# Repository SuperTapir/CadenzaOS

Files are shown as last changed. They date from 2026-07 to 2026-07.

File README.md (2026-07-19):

# Cadenza OS

**English** · [简体中文](README.zh-CN.md)

<p align="center">
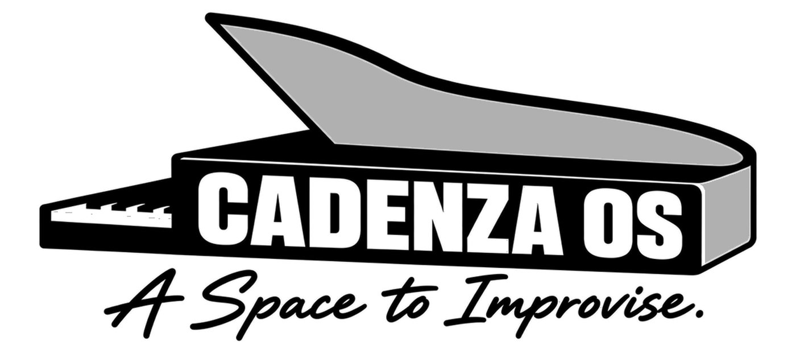
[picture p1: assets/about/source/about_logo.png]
Cadenza OS — A Space to Improvise.
  
</p>

**Cadenza** is a personal interactive-device and creative platform by Tapir.
Its system, **Cadenza OS**, explores a portable 1-bit App/Runtime, system
interaction model, and animation language for resource-constrained hardware.
The current prototype targets the original LILYGO T-Embed (not the CC1101
edition).

https://github.com/user-attachments/assets/4cbb17ba-b52b-44dc-b557-88dd9fdf3d63

The walkthrough above includes sound and covers Launcher, Timer, the background
Timer indicator, System Menu, Motion, Settings, and Animation Gallery. The
current build also adds the SIGHT note-reading trainer. Cadenza supports the
T-Embed 320×170 and Sharp Memory LCD 400×240 display profiles.

> **Prototype status:** desktop, headless, and firmware build gates are in
> place. Encoder feel, display behavior, real frame rate, and speaker quality
> still require validation on an original T-Embed device.

> **Non-commercial hobby project:** Cadenza is a personal project made for the
> enjoyment of designing and building it. There is no plan to commercialize
> it, sell it, or turn it into a business.

## Motivation

A *cadenza* is a passage in music where a performer is given room for free
expression. That idea fits this project: a restrained and coherent device that
leaves space for small games, tools, animation, and interaction experiments.

Cadenza grows out of Tapir's deep affection for Playdate's design and art
direction—not simply for it as a handheld, but for it as a carefully designed
digital object: a reflective black-and-white display, direct physical input,
expressive motion, and a small set of features with a strong point of view.
Many Launcher behaviors, interaction rhythms, animations, and visual details
in Cadenza deliberately study and attempt to recreate how Playdate works and
feels. Rebuilding those ideas is a way to understand the craft behind them and
to carry that learning into a personal platform, rather than an attempt to run
or replace Playdate software.

The T-Embed is the first software and interaction prototype. The longer-term
hardware direction centers on a 400×240 Sharp `LS027B7DH01` Memory LCD and a
dedicated handheld design. The software is structured so the prototype proves
the platform without defining the final device.

## Highlights

- One 1-bit framebuffer, App/Runtime, and layout model shared by the 320×170
  T-Embed and 400×240 Sharp profiles;
- six built-in Apps—Launcher, Timer, SIGHT, Motion, Settings, and Animation
  Gallery—with encoder navigation, button input, a System Menu, and explicit
  return to Launcher;
- system-owned background Timer, expiry alert, session volume, Reduced Motion,
  and vertical or horizontal Launcher orientation;
- 18 semantic sound cues plus bounded 1–4 note MIDI playback, backed by the
  same 44.1 kHz, four-voice synthesis core in the SDL callback and T-Embed I²S
  task;
- allocation-free Tween, Timeline, Spring, transitions, camera effects,
  particles, and atlas animation state machines;
- an SDL3 desktop simulator, deterministic headless host, PNG/GIF capture,
  pixel snapshots, and tests for lifecycle, input, animation, audio, and system
  services.

Cadenza is currently a 1-bit interaction and animation runtime, not a complete
game engine. Physics, collision, tilemaps, ECS, and level systems are
deliberately out of scope.

## Quick start on macOS

```bash
brew install cmake sdl3
./tools/simulator.py run --profile t-embed --scale 2 --overlay
```

For the source-watching development loop:

```bash
./tools/simulator.py dev --profile t-embed --scale 2 --overlay
```

Common presentation options are `--profile t-embed|sharp`, `--scale 1..4`,
`--palette reflective|pure`, `--overlay`, and `--device-frame`. The default
`reflective` palette approximates a reflective Memory LCD; `pure` is for strict
black-and-white inspection. These options do not change the framebuffer,
captures, snapshot hashes, or firmware output.

## Desktop controls

| Input | Action |
| --- | --- |
| Mouse wheel or `Left` / `Right` | Rotate the encoder |
| Tap `Space` / `Enter` | Click the button |
| Hold `Space` / `Enter` | Open the System Menu |
| `F1` | Toggle the debug HUD |
| `F2` / `F3` | Pause or resume / single-step while paused |
| `F4` / `F5` | Toggle fixed/real step / cycle time scale |
| `F6` / `F7` | Capture PNG / start or stop PNG+GIF recording |

See [`docs/development.md`](docs/development.md) for complete controls, Timer
behavior, display options, and the Launcher Cover workflow.

## Build and verification

```bash
tools/check.sh host           # host build and full test suite
tools/check.sh desktop        # SDL3 build and launch smoke test
tools/check.sh firmware       # ESP-IDF 5.5 T-Embed primary (UAC+CDC)
tools/firmware_uac.sh flash   # flash primary firmware to T-Embed
tools/check.sh firmware-pio   # PlatformIO rollback (no UAC)
tools/check.sh all            # host + desktop + ESP-IDF firmware + diff
```

Primary firmware needs ESP-IDF v5.5 (`CADENZA_IDF_PATH` or `../esp-idf-v5.5`).
PlatformIO rollback (no microphone):

```bash
../.platformio-env/bin/pio run
../.platformio-env/bin/pio run --target upload
../.platformio-env/bin/pio device monitor --baud 115200
```

Create an ad-hoc-signed macOS development package with:

```bash
./tools/simulator.py package
```

The resulting `.app` and zip are intended for local or same-architecture Mac
development. They are not Developer ID signed or notarized releases.

## Hardware safety

The current pin configuration comes from the official original LILYGO T-Embed
configuration. **Do not flash it to a T-Embed CC1101.** Check the packaging and
board markings before using firmware from this repository.

## Development disclosure

Most source code in this repository has been generated and iterated with
**OpenAI Codex** under Tapir's direction. Tapir defines the product vision,
requirements, architecture decisions, review standards, and acceptance
criteria; Codex performs much of the implementation, refactoring,
documentation, and test authoring.

AI-generated code is not treated as independently trustworthy. Accepted
changes are reviewed and checked through builds, tests, snapshots, research
records, and hardware gates where hardware is available. Tapir remains the
project's author and maintainer and is responsible for the work accepted into
the repository.

## Acknowledgements

- Deepest thanks to [Panic](https://panic.com/) and the
  [Playdate](https://play.date/) team. Cadenza would not exist without the
  affection and respect Tapir has for Playdate's industrial design, art
  direction, interaction design, and animation craft. The project openly
  studies and attempts to recreate many of those interaction patterns and
  qualities. Cadenza remains an independent project, is not compatible with
  Playdate software, and is not endorsed by Panic. The vendored Playdate
  Roobert font subset is used under CC BY 4.0 as documented in
  [`THIRD_PARTY_NOTICES.md`](THIRD_PARTY_NOTICES.md).
- [LILYGO](https://www.lilygo.cc/) created the T-Embed hardware used for the
  first prototype and publishes the reference material used by the platform
  adapter.
- SDL3, U8g2, doctest, stb_image_write, and gif-h make the portable build,
  rendering, testing, and desktop tooling possible. Exact versions, source
  boundaries, and licenses are recorded in
  [`THIRD_PARTY_NOTICES.md`](THIRD_PARTY_NOTICES.md).

## Further reading

- [`docs/project-vision.md`](docs/project-vision.md): long-term goals,
  motivation, and hardware direction;
- [`docs/platform-architecture.md`](docs/platform-architecture.md): platform
  responsibilities and architectural boundaries;
- [`docs/development.md`](docs/development.md): development, testing, and
  simulator reference;
- [`docs/verification.md`](docs/verification.md): current evidence, gates, and
  device verification scripts;
- [`docs/engine-adoption-decision.md`](docs/engine-adoption-decision.md): engine
  and library adoption boundaries;
- [`docs/audio-reference-research.md`](docs/audio-reference-research.md): audio
  research and adoption decisions;
- [`docs/audio-asset-contract.md`](docs/audio-asset-contract.md): delivery and
  acceptance rules for future WAV assets.

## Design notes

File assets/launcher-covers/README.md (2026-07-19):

# Launcher Covers

`timer.pbm`、`motion.pbm`、`settings.pbm` 与 `gallery.pbm` 是四个内置
App 经人工确认后的 350×155、1-bit 封面。`*_t_embed.pbm` 是直接从同一
高分辨率母图生成的 280×124 T-Embed 版本。它们以屏幕像素为
最终审阅单位，不在设备运行时解码 PNG、缩放或分配临时 framebuffer。

`source/` 保存四张清理后的原始 PNG，用于未来重新调阈值、支持新尺寸或
重新导出；固件不直接编译这些 PNG。

源插图由用户提供并经 AI 辅助精简；使用 Pillow 的 LANCZOS 缩放到
350×155 与 280×124。新版 MOTION、SETTINGS 与 GALLERY 使用五档 ordered dither，并启用通用
`--edge-cleanup`：同时邻接近黑与近白的抗锯齿过渡像素及其 1 px guard band
改用 coverage threshold，宽阔灰面仍保留 ordered dither，避免标题、圆环和
baseline、控制台或人物轮廓的灰边变成 Bayer 毛刺。SETTINGS 的母图另经插画门禁，
拒绝连续产品渲染光照，要求硬边离散平面与独立的实色外轮廓。TIMER 使用五档 ordered dither，并在已批准标题区域保留原 coverage hint，避免
改变其既有 hash。
禁止从已二值化的 PBM 二次缩放，否则细线会碎裂并产生孤立黑点。

MOTION 的可复现生成与检查命令：

```sh
python3 .codex/skills/generate-launcher-cover-art/scripts/prepare_cover.py \
  assets/launcher-covers/source/motion.png assets/launcher-covers \
  --name motion --levels 5 --edge-cleanup

python3 .codex/skills/generate-launcher-cover-art/scripts/prepare_cover.py \
  assets/launcher-covers/source/motion.png assets/launcher-covers \
  --name motion --levels 5 --edge-cleanup --check
```

GALLERY 使用相同管线：

```sh
python3 .codex/skills/generate-launcher-cover-art/scripts/prepare_cover.py \
  assets/launcher-covers/source/gallery.png assets/launcher-covers \
  --name gallery --levels 5 --edge-cleanup --check
```

SETTINGS 使用相同管线：

```sh
python3 .codex/skills/generate-launcher-cover-art/scripts/prepare_cover.py \
  assets/launcher-covers/source/settings.png assets/launcher-covers \
  --name settings --levels 5 --edge-cleanup --check
```

非 `--check` 模式还会自动生成双 profile 的硬阈值、ordered-dither pure/reflective
及 nearest-neighbor 4× 审阅图；硬阈值负责证明标题与主轮廓不依赖灰阶，4× 图负责
区分规则像素阶梯与贴边 Bayer 毛刺。

这些工具需要 Pillow；CMake 使用的 Python 能导入 Pillow 时会自动注册八个母图
来源检查，没有 Pillow 时仍保留不依赖 Pillow 的八个 PBM→header 检查。

TIMER 的可复现生成与检查命令：

```sh
python3 .codex/skills/generate-launcher-cover-art/scripts/prepare_cover.py \
  assets/launcher-covers/source/timer.png assets/launcher-covers \
  --name timer --levels 5 \
  --solid-light-region 0.026 0.40 0.70 0.92

python3 .codex/skills/generate-launcher-cover-art/scripts/prepare_cover.py \
  assets/launcher-covers/source/timer.png assets/launcher-covers \
  --name timer --levels 5 \
  --solid-light-region 0.026 0.40 0.70 0.92 --check
```

生成 packed headers：

```sh
python3 tools/pack_bitmap.py assets/launcher-covers/timer.pbm \
  lib/cadenza_apps/src/generated/timer_cover.h \
  --symbol kTimerCover \
  --provenance "Cadenza original AI-assisted 3D TIMER artwork, user-approved 2026-07-19; canonical PBM in assets/launcher-covers/timer.pbm"
```

`motion`、`settings`、`gallery` 以及对应的 `*_t_embed` 使用同样命令与
对应符号。CMake host tests 会使用 `--check` 验证八个 header 与 PBM
逐字节一致。

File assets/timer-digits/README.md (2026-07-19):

# Timer numeral atlases

`tools/generate_timer_digits.py` 生成 Cadenza 自有的工业仪表数字 atlas。运行时只读取已打包的 1-bit header，不依赖字体引擎、Pillow 或 heap。

- T-Embed：digit cell `50×84`、colon cell `28×84`，组合 `MM:SS` 为 `228×84`。
- Sharp：digit cell `68×120`、colon cell `36×120`，组合 `MM:SS` 为 `308×120`。
- `source/timer_digits_master.svg` 是平滑可编辑母稿；两个 PBM 是原生 profile 资产。

生成命令：

```bash
python3 tools/generate_timer_digits.py
python3 tools/pack_bitmap.py assets/timer-digits/timer_digits_t_embed.pbm \
  lib/cadenza_core/include/cadenza/presentation/generated/timer_digits_t_embed.h \
  --symbol kTimerDigitsTEmbed \
  --provenance "Cadenza-authored industrial Timer numerals; native 528x84 atlas from tools/generate_timer_digits.py"
python3 tools/pack_bitmap.py assets/timer-digits/timer_digits_sharp.pbm \
  lib/cadenza_core/include/cadenza/presentation/generated/timer_digits_sharp.h \
  --symbol kTimerDigitsSharp \
  --provenance "Cadenza-authored industrial Timer numerals; native 716x120 atlas from tools/generate_timer_digits.py"
```

封面裁切、灰阶缩略图和 reflective preview 使用 `tools/asset-requirements.txt` 中固定版本的 Pillow；该依赖仅属于离线资产流程。

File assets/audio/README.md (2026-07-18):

# Audio source assets

此目录用于未来经人工选中的交互音效无损母版。当前运行时仍使用参数合成，仓库尚未包含 sample voice 或默认 WAV 资产。

提交文件前请遵循 [`docs/audio-asset-contract.md`](../../docs/audio-asset-contract.md)，并为每个 WAV 提供 manifest。不要把临时生成结果、来源不明素材或有损预览文件提交到这里。

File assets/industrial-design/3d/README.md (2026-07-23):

# Cadenza 3D 概念模型 V1

这是用于讨论外观比例、握持和器件包络的参数化 OpenSCAD 概念模型，不是可直接开模、CNC 或装配的生产 CAD。

## 当前包络

- 主机本体概念尺寸：`120 × 50 × 16 mm`
- 一体式实心后壳最大凸出：约 `10 mm`
- 中央最大总厚度：约 `26 mm`；四周边缘仍保持圆润纤薄
- 固定屏幕玻璃：`62.8 × 42.82 × 1.64 mm`
- 屏幕可视区：`58.8 × 35.28 mm`
- 旋压 `A` 控制器有效哑光面径：约 `20.5 mm`；低饱和银蓝色外环总直径约 `22.6 mm`
- 屏幕玻璃包络隐藏在前壳下；外露黑色窗口约 `60.0 × 36.5 mm`，可视区外只留约 `0.6 mm` 细黑收口
- 正面以屏幕中心线为整机中轴，屏幕几何居中；左右控制区宽度完全相等
- `B` 面径约 `10.5 mm`；`Menu` 为约 `8.5 × 3.4 mm` 的低矮胶囊键；旋压 `A` 约 `20.5 mm`

模型包含屏幕、`B`、`Menu`、旋压 `A`、顶部金属 `Power/Lock`、向机顶中央收近的 USB-C 充电口、机顶一体化声学槽阵列、左端短边齐平红外光学窗、机底右下角 MicroSD 和干净的可维护后盖。USB-C 与 MicroSD 分属上、下两边，避免同时插拔干涉。左端约 `10 × 3 mm` 的深酒红烟熏长圆透镜同时服务红外发射与接收；透镜表面封闭并带轻微弧度，后方只若隐若现地表现一大一小两枚圆形光学元件，以区别于 USB 或耳机端口，外表不暴露 LED。窗口材料、红外透过率、内部遮光隔舱、发射角和接收角均由第三方验证。屏幕玻璃的安装黑边由珍珠银白前壳覆盖，屏幕表面比前壳低约 `0.5–0.7 mm`，正面只显示窄黑色窗口收口。`Menu` 键不再使用文字，改为键帽上的三点 `•••` 标识。当前不包含扩展坞、背板导轨或外接模块。

背面采用 Sony / 日系仪器方向：大面积安静表面中嵌入一块居中的长圆角电池与维修盖，只保留窄分件缝、四条开启防滑纹和一个低调紧固点。该结构借鉴 SONIC SticKURU Timer 背面“功能细节集中、其余表面克制”的秩序，不复制其具体电池仓几何。

背面采用一体式实心楔形后壳：从主机后壳的宽大根部连续收窄到外侧平台，约凸出 `10 mm`。侧面轮廓内全部为实体，没有空隙、背夹、支撑杆、翻板、转轴或活动支架。斜线是实心后壳的外轮廓，不是独立零件。外表面保留居中长圆角维修盖板和极少服务细节。它通过宽而顺滑的过渡与主体融合，避免成为额外挂载的“书包”。各摆放姿态的重心、摩擦力和按键操作稳定性必须由第三方用真实重量样机验证。

维修盖中央使用缩小后的浅浮雕花体 `Cadenza` 字样，同材质、同颜色，主要依靠侧光阴影显现，不做高对比印刷。字样以机顶（声学槽阵列与 Power/Lock 所在长边）朝上时保持正读；背面正投影视图已按这个正常观看方向校核，不上下翻转。

机底不使用独立深色橡胶条，改为两条与外壳一体成型、同色且仅轻微突出的纵向小棱。小棱沿机身前后厚度方向延伸，不沿机身左右长边横置；其轮廓必须完整收在机底银白侧壁内，不跨越与楔形后壳的交界线。实际防滑性必须结合表面纹理和样机摩擦测试确认。

机顶使用九条等形长圆声学槽：左右各四条服务扬声器，中间一条作为麦克风拾音入口，外观上是一组连续、对称且有秩序的开孔。正面不再出现独立麦克风黑点。槽阵内侧覆盖深灰色细密声学防尘网；中心拾音槽必须通过独立密封声道连接麦克风，并与左右扬声器音腔及壳体振动软隔离，不能共用音腔。第三方必须根据扬声器频响、声压、麦克风指向性和防尘要求选择网材、目数、声阻与固定工艺，并用声学样机验证回声、串音和结构振动。

当前 CMF 概念以 `PANTONE Cool Gray 2 C` 作为正面塑料按钮浅灰参考，以偏暖的 `PANTONE Black 7 C` 作为 `A/B` 字标深石墨灰参考。`A` 旋压控制器增加低反光、低饱和的银蓝色窄外环（约 `PANTONE 7544 C` 方向），内部有效操作面仍为哑光浅灰塑料；触觉点收敛为 10 个。所有键帽都使用大面积近似平整的顶面和小半径圆滑肩部，不做纯直筒圆柱，也不做过分饱满的半球；其中 A 保留约 `1.5–1.7 mm` 可抓握侧高，B 与 `•••` 只略高于面板。顶部 Power/Lock 仍为中性缎面银色。整体复古感来自博朗式的克制比例、低饱和材料、明确功能层级和精确细节秩序，不复制具体产品。模型中的 RGB 只能用于屏幕预览，实体必须用近期 Pantone 色卡和实际材料样片确认。

## 文件

- `cadenza-concept-v1.scad`：可继续调整的参数化源文件
- `cadenza-concept-v1.csg`：OpenSCAD 展开后的几何树，适合交换或排查模型
- `cadenza-concept-v1.stl`：通用网格预览文件
- `cadenza-concept-v1.3mf`：优先用于支持 3MF 的查看器
- `cadenza-concept-v1-preview.png`：快速预览图
- `cadenza-concept-v1-back-pod-preview.png`：一体式实心后壳与顺滑过渡的预览
- `cadenza-concept-v1-front.png`：用于检查屏幕中轴与左右控制区对称关系的正投影视图
- `cadenza-concept-v1-back.png`：用于检查日系仪器式电池/维修盖秩序的背面正投影视图
- `cadenza-concept-v1-side.png`：用于检查“外轮廓内全实体”的楔形侧面
- `cadenza-concept-v1-top.png`：用于检查 USB-C、扬声器防尘网开孔与 `Power/Lock` 的机顶布局
- `cadenza-concept-v1-bottom.png`：用于检查右下角 MicroSD 与两条纵向防滑小棱
- `cadenza-concept-v1-ir-left.png`：用于检查左端短边齐平红外发射/接收光学窗

## 边界

圆角、壁厚、卡扣、螺钉、按键行程、屏幕固定、音腔、天线净空、连接器安装、公差和材料收缩均未完成工程验证。第三方结构工程师必须以真实器件和制造工艺重新设计。

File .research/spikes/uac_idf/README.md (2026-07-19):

# CadenzaOS ESP-IDF 5.5 UAC / T-Embed firmware composition

这是 CadenzaOS **主固件组合根**（ESP-IDF 5.5：Runtime Apps + UAC2 麦 + CDC）。
PlatformIO Arduino 2.0.17 仅作无 UAC 回滚（`tools/check.sh firmware-pio`）。

```sh
# 从仓库根目录
tools/check.sh firmware          # 构建（firmware-uac 为同义别名）
tools/firmware_uac.sh flash      # 烧录
tools/firmware_uac.sh size
tools/firmware_uac.sh connectivity
```

SDK 组合：ESP32-S3、ESP-IDF 5.5.0、Arduino-ESP32 3.3.10、`usb_device_uac`
1.3.1、TinyUSB 0.19.0~3、`esp_codec_dev` 1.5.10、UAC2 microphone-only + CDC。
portable Runtime / voice / Apps 仍在仓库 `lib/`；本目录只做板级装配，不私补
本机 PlatformIO Arduino 2.0.17 package。

已定麦克风基线（2026-07-19 真机）：双 MEMS 平均、24 dB、USB 重连强制回收
I²S/DMA 帧对齐；macOS 枚举为 48 kHz mono 系统麦。

## 前置条件

- 官方 ESP-IDF v5.5 checkout；验证 commit 为
  `8c750b088c7cd857d079c0eeb495da199b359461`。
- `install.sh esp32s3` 与 `export.sh`，或由 `tools/firmware_uac.sh` 通过
  `CADENZA_IDF_PATH` / `../esp-idf-v5.5` 自动 `source export.sh`。

## 构建（底层命令；优先用 tools/ 入口）

```sh
cd .research/spikes/uac_idf
idf.py -B build-idf-arduino-composite build size

idf.py -B build-idf-hardware \
  -DSDKCONFIG="$PWD/sdkconfig.hardware" \
  -DSDKCONFIG_DEFAULTS='sdkconfig.defaults;sdkconfig.hardware.defaults' build
idf.py -B build-idf-hardware size

idf.py -B build-idf-connectivity \
  -DSDKCONFIG="$PWD/sdkconfig.connectivity" \
  -DSDKCONFIG_DEFAULTS='sdkconfig.defaults;sdkconfig.hardware.defaults' build
idf.py -B build-idf-connectivity size
```

它链接 ESP-IDF 内置的 NVS、`esp_netif`、event loop、Wi-Fi station、NimBLE、
software coexistence、`wifi_provisioning` 与 protocomm Security 2。Security 0/1
在该配置中关闭；仓库不带通用 verifier 或 salt，量产方必须覆盖弱符号
`cadenza_load_security2_material`，从受控平台边界提供设备材料。

`sdkconfig.defaults` 只启用 `esp_codec_dev` 的 ES7210 driver，关闭未使用 codec。
默认 board config 固定 I²C0 SDA 18/SCL 8、I²S1 MCLK 48/BCLK 47/LRCK 21/DIN 14，
48 kHz、32-bit stereo DMA 输入在 portable normalizer 中平均为 S16 mono。
已定真机基线：双 MEMS 平均、24 dB in-gain。

当前完整 candidate binary 为 388,032 B（`0x5ebc0`），size tool total image
387,911 B、DIRAM 146,103 B（42.75%）、Flash Code 235,552 B、Flash Data
75,328 B。UI/main、TinyUSB、UAC mic、ES7210 capture 与 speaker 的显式 stack
预算合计 26,624 B，运行时 free heap/high-water 仍待真机测量。

2026-07-18 clean reconfigure 后，不带连接 adapter 的完整 candidate 为
390,752 B，total image 390,607 B、static D/IRAM 147,767 B。带连接 adapter 的
candidate 为 1,176,672 B，total image 1,176,519 B、static D/IRAM 226,823 B，
相对前者分别增加 785,920 B、785,912 B 与 79,056 B；1.5 MiB app partition
剩余约 23%，static D/IRAM 余 114,937 B。该差值包含 Wi-Fi、NimBLE、protocomm、
Security 2 与它们的链接闭包，不代表运行时 heap/stack 已验收。

ESP-IDF 5.5 的官方 `protocomm_nimble.c` 会自行调用 `nimble_port_init()`、覆盖
`ble_hs_cfg` callback，并创建/停止 NimBLE host task。当前 adapter 因而把普通
App BLE 与 BLE provisioning 定义为排他角色：普通 BLE 仅在需要时启动自己的
NimBLE host；Security 2 配网仅在普通 BLE 未请求/未初始化时启动，否则返回 busy。
这不是推测性的共存承诺，角色切换与资源释放仍须真机验证。

`dependencies.lock` 锁定 32 个解析组件。供应链复验逐项校验所有
`CHECKSUMS.json`，共 7,600 个文件、0 个错误；ELF 审计确认 Cadenza adapter、
`wifi_prov_mgr_start_provisioning`、NimBLE init/stop 与 UAC public/upstream callback
符号同时存在，且没有修改 `managed_components` 源码。

`dependencies.lock` 是本次成功解析得到的完整依赖锁。不要修改本机 Arduino
2.0.17 framework package 来绕过 TinyUSB audio 配置。

PlatformIO 的 ESP-IDF builder 在本 spike 中曾因同一 managed-component object
出现重复 action 而失败；`platformio.ini` 仅保留失败复现入口。候选 baseline
使用官方 `idf.py`，现有 Arduino firmware target 继续作为回滚路径。
当前 UAC component 内部会在 TinyUSB alt-setting callback 中维护 `mic_active`，
但没有向 user callback 暴露 microphone close/open。candidate CMake 对锁定的
1.3.1 两个 callback 做编译期符号重命名；Cadenza adapter 提供公共入口、先委托
原实现，再把 mount/alt-setting 写入 callback-safe `UsbVoiceSessionBridge`。该方式
不修改 managed component 源码；升级 component 时必须重跑 callback 源码与 ELF
符号审计。它证明 session wiring 可构建，不把 build-only 行为当作真机断连/重连
验收。

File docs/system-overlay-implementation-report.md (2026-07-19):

# System Overlay 实现与验证记录

状态：portable 实现与软件门禁完成；实体 T-Embed 的手感、可读性和 100 次循环验收待真机。

## 已交付边界

- `SystemSurfaceCoordinator`：单 interactive slot、完整按键序列 capture、转场 defer、固定容量 transient queue 和稳定 rejection diagnostics；
- System Menu：只保留 Resume、Sound、Motion，以及非 Home 场景的 Home action；Connectivity/Device 等无动作状态不占菜单空间；不进入 App catalog，不暴露 callback、driver 或任意 View；
- suspend-with-snapshot：Menu active 时冻结 App update/input/render 与背景，但 `SystemServiceHost` 继续 begin/commit；
- stateless `Panel`、`MenuRow`、`Selection`、`VolumeIndicator` 与 `Switch`；
- 固定合成顺序：App/transition → transient → interactive Menu → FrameCoordinator critical indicator；
- 320×170 与 400×240 使用同一 model、layout policy 和 renderer；不透明 Menu
  drawer 在 160 ms 内从右侧滑入，mask 同步渐强，左侧冻结 App 仍保留上下文，
  视觉语义对齐 Playdate 的覆盖式 System Menu。最终视觉去掉标题栏、箭头、双边框
  和横向 value 文本列；可操作项使用大字号，Sound 始终显示实心/空心音量柱，Motion
  使用紧凑横向开关，不绘制无动作底栏，Home 页面不显示冗余 Home action。

## 输入与生命周期证据

`cadenza_system_surface_tests` 与 `cadenza_app_runtime_tests` 锁定：

- opening long-press 的 held/release/click 不确认 Menu；
- closing long-press 到 release 全部由 System 消费，下一新序列才恢复 App；
- Menu turn 不进入 App，快速 delta 有界且每帧最多一个 Navigate intent；
- 转场中的 Menu 请求先 capture，目标 App stable 后再冻结并打开；
- Menu 多帧期间 App 不 update/render，也不发生 exit/enter；
- 平台事件和 setting command 仍在 frame transaction 中提交；
- busy、denied、invalid action 和 transient full 都保留 surface 并累计诊断。

双 profile Menu golden：

- 320×170 右侧 Menu drawer：`17166433962280013512`；
- 400×240 右侧 Menu drawer：`13747170315493377016`；
- 320×170 transient + indicator：`325176067826602694`；
- 400×240 transient + indicator：`3852824331461943778`。

## 内存与固件差异

Apple arm64 Debug 对象探针：

| 对象 | 大小 |
|---|---:|
| `MonoFramebuffer` | 12,024 B |
| `SystemSurfaceCoordinator` | 200 B |
| `AppRuntime` | 24,912 B |

`system_overlay_size_probe` 带编译期断言，要求 `AppRuntime` 小于三块最大
`MonoFramebuffer`；实现只复用既有 `outgoingFrame_`/`incomingFrame_`，没有第三块
12 KiB framebuffer。

PlatformIO Arduino-ESP32 2.0.17：

| 指标 | 改动前 | 当前 | 增量 |
|---|---:|---:|---:|
| static RAM | 98,808 B | 99,000 B | +192 B |
| flash | 358,805 B | 361,705 B | +2,900 B |

ESP-IDF 5.5 connectivity candidate 也实际编译 `system_surface.cpp`：binary
1,188,496 B、total image 1,188,351 B、static D/IRAM 231,143 B、Flash
1,052,528 B。Overlay 没有新增 task 或 stack，coordinator 继续在既有 frame
transaction 内同步推进。GCC 14 candidate 发现并修复了 Xtensa 上 `int32_t` 为 `long` 时
`std::min/std::max(int32_t, int)` 推导失败的问题。

## 实体验收（2026-07-19）

在实体 320×170 T-Embed 上完成，结论如下：

1. 650 ms 长按适合频繁打开，保留 `InputConfig::longPressMs = 650`；
2. 触发 release、关闭 held release 与快速连续开/关手感通过，无误确认与输入泄漏；
3. Menu 文本、selection、音量格与开关在面板上可读；
4. Muted/有声反馈等价，反复 open/close 稳定，串口无 panic/TWDT；
5. 不调整视觉常量，无 contract 回写需求。

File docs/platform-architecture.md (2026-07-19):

# Cadenza OS 平台架构（原型 v0.1）

当前目标不是把三个 Demo 做完整，而是确定一套小应用可以长期生长的稳定边界。Demo 只负责证明平台契约确实可用。

## 运行链路

```text
platform callbacks ──→ bounded typed PlatformEvent queue
                              ↓ beginFrame
raw input ──→ InputReducer ──→ frozen SystemSnapshot + AppUpdateContext
                              ↓ typed SystemCommand queue
                         SystemServiceHost commit
                              ↓ same-frame AppRenderContext
                         AppRuntime + transition
                              ↓
                       canonical MonoFramebuffer
                              ↓
               T-Embed / SDL / headless / future Sharp

ES7210/I²S1 ──→ 48 kHz voice coordinator ──┬─→ analyzer snapshot ─→ Apps
                                           └─→ UAC packetizer ───→ macOS
SoundCue / bounded MusicalNoteSet ─→ 44.1 kHz sound service ─→ I²S0 / SDL / headless
monotonic now ─→ TimerService deadline ─→ snapshot / critical TimerAlert
```

## 平台负责什么

- 初始化硬件和维护稳定的帧循环；
- 将旋钮和按钮统一成与具体 GPIO 无关的 `InputFrame`；
- 组合 `cadenza_core`、`cadenza_apps`、`cadenza_system` 与平台 adapter；
- 注册应用、维护当前应用，并调用生命周期；
- 拦截“长按打开 System Menu”这样的系统手势；
- 绘制统一的应用切换转场；
- 提供 row-major、MSB-first、`1 = black` 的 1-bit 画布，禁止应用依赖彩色
  TFT 或 SDL 特性；
- 将显示提交与应用绘制分离；
- 拥有 `InteractionSoundService`，把 Navigate、Confirm、Back 等语义提交给
  独立音频消费者；允许具备 SoundPlay capability 的 App 提交最多四音、钢琴
  MIDI 范围内的 `MusicalNoteSet`，但应用不得操作 SDL、I²S、WAV 路径、Hz、
  waveform、gain、duration、priority、voice 或任意 oscillator。
- 拥有 voice capture 生命周期、consumer fan-out、隐私状态与错误降级；App 不得
  取得 raw PCM、codec、DMA、USB、Wi-Fi 或 BLE callback。
- 拥有单一 `TimerService`、单调 deadline、后台 indicator 与 critical alert；App
  不读取平台时钟，也不在自身 `dt` 中累计倒计时。

## 应用负责什么

每个内置应用只实现五个很小的接口：

```cpp
const char* name() const;
void onEnter();
void onExit();
void update(const AppUpdateContext& context);
void render(MonoCanvas& canvas, const AppRenderContext& context);
```

update context 只含 `dt`、`InputFrame`、只读 `SystemSnapshot`、catalog view、
`AppNavigator` 与绑定当前 App 身份的 `AppCommandPort`；render context 只含只读 snapshot。
应用不读取 GPIO，不直接持有屏幕，不自行实现页面切换，也不通过 `delay()` 控制
节奏。状态只属于应用实例；系统可以随时离开它，再通过 `onEnter()` 重新进入。

## 模块与所有权

- `cadenza_core`：App 契约/目录/生命周期、输入、图形、动画、声音语义；不知道
  bundled App 与平台 SDK。
- `cadenza_apps`：Launcher、Timer、SIGHT、Motion、Settings、Gallery；只能依赖窄 App
  context。
- `cadenza_system`：帧事务、权威系统状态、sound/voice services、固定队列、USB
  packetizer 与 DMA normalizer；不含平台 header。
- platform roots：headless、SDL、当前 Arduino firmware、候选 ESP-IDF firmware；
  负责硬件/API 对接，不重新定义业务状态或 PCM 语义。

System Overlay 属于 `cadenza_core` 的 portable presentation state，不是隐藏 App。
它只允许一个 interactive surface，按 App/transition、transient、interactive、
persistent/critical 的固定顺序合成。System Menu 打开时复用 Runtime 已有 framebuffer
冻结 active App；AppId 与 enter/exit 生命周期不变，system frame transaction 继续。
按钮从 long-press 到 release 锁存给 System，避免打开/关闭边界输入泄漏。

## 关键决定

### 输入采样不绑定帧率

主循环每次迭代都采样编码器，事件累积到下一帧再交给应用。这样即使某帧传输较慢，也不会因为只在 60 FPS 的绘制点读取 GPIO 而轻易丢失旋转边沿。

### 先做静态注册

应用目前随固件编译并在 `setup()` 中注册。这个选择让生命周期、内存占用和崩溃边界更容易验证。SD 卡资源、脚本应用和动态加载等到平台契约稳定后再做。

### 唯一权威画面是 1-bit framebuffer

T-Embed 虽然是彩屏，应用拿到的仍然只有黑白图元接口。U8g2 的精选 raster
与字体代码只写入 caller-owned framebuffer；TFT、SDL、PNG、GIF 和测试都只
读取同一份像素。Sharp profile 已在桌面和快照中验证，未来只需增加 presenter，
不再替换画布或 App 代码。

### 两块屏幕使用各自的原生分辨率

T-Embed 后端使用 320 × 170，Sharp 后端使用 400 × 240。平台不对整幅画面做非等比缩放；应用从 `MonoCanvas` 读取实际宽高，按区域、边距和锚点响应式布局。这样既不会把 Sharp 的像素构图锁死在临时硬件上，也能充分利用 T-Embed 的整块屏幕。

### 动画与内存边界

Tween、Sequence、Parallel、Timeline、Spring、粒子和状态机都使用值语义或
固定容量，不在逐帧路径分配。SDL3、stb 和 gif-h 只属于 desktop adapter；
core 不包含 Arduino、TFT_eSPI 或 SDL header。转场采用明确的 source/
destination framebuffer 所有权，代价见 [`memory-budget.md`](memory-budget.md)。

### 音频时钟不绑定图形帧

App 与 Runtime 只在状态实际变化时提交 `SoundCue`。16 项固定 SPSC 队列把
主线程与音频消费者隔离；Navigate/Boundary 最多占 12 项，为关键提示和控制
保留容量。Muted/StopAll 另有原子安全邮箱，因此即使关键 cue 填满队列也不能
阻塞静音。

`AudioEngine` 由唯一消费者拥有：桌面是 SDL3 AudioStream callback，T-Embed
是固定到 core 0 的 FreeRTOS task，headless 测试同步拉取。三者消费相同的
44.1 kHz、S16、mono PCM。T-Embed adapter 只负责将 mono 复制为 right-left
I²S frame；任何平台 adapter 都不得另写一套音色。

当前音色是集中在 `sound_cue_library.cpp` 的 16 项参数合成 palette。四声部
`AudioEngine` 提供 wavetable Sine、预计算指数包络与二次谐波；固定容量的
consumer-owned event 调度器支持 sample-offset 延迟，Muted/StopAll 会同时清空
当前声部和未来 event。它不是不可替换的产品资产；未来 WAV 仍映射到相同
`SoundCue` Event，母版、平台转换、来源权利和真机验收遵循
[`audio-asset-contract.md`](audio-asset-contract.md)。

### 帧事务与异步回调

Wi-Fi、BLE、USB、I²S 等 callback 只能写入有界 adapter/mailbox 或
`PlatformEvent` queue；它们不能调用 App 生命周期或直接修改 snapshot。
SDK callback 使用单 producer/单 consumer 的 `PlatformEventMailbox<N>`，满时
拒绝 newest 并记录 posted/consumed/rejected/high-water；主 system loop 再将
Wi-Fi/Bluetooth LE 等 typed event 摄取进 host。App 只看到稳定的
`ConnectivitySnapshot`，不看到 mailbox、SSID/凭据、socket 或 GATT callback。
`beginFrame()` 在预算内摄取事件并冻结 update snapshot，App update 只排队命令，
`commitCommands()` 按 FIFO 提交并生成同帧 render snapshot。队列满、拒绝原因和
high-water 都可观测，避免把中断/SDK 线程变成隐式重入路径。

Timer 使用同一 frame transaction，但时间真相来自显式 `beginFrameAt(nowMs, dt)`：
firmware、SDL 和 headless 分别注入各自 64-bit 单调时间。动画 `dt` 为零或被 clamp
不会暂停 Timer；只有 Pause 命令会。到期 edge 在 begin phase 产生一次 bounded
alert 请求，App command 仍在 commit phase 生效。

### App 能力路由不是进程沙箱

组合根用固定 `AppDescriptor`/`AppCapabilitySet` 声明每个 App 的最小能力；未声明
即默认拒绝。Runtime 只把绑定当前 AppId 的 operation port 放进 update context，
App 不能通过该 API 自选 caller。port 在入队前检查 capability，SystemServiceHost
在 commit 时通过只读 catalog resolver 再检查一次，因此错误 adapter 直接注入 App
信封也不能绕过策略。System 与 USB 使用不同 owner，拒绝原因、owner、operation 和
queue high-water 可审计。

这是同一地址空间内的 policy enforcement，不是 native process sandbox：C++ 固件
中的恶意或内存越界代码仍可能绕过类型边界。当前目标是约束受支持 App API、减少
误用并提供可验证审计；若未来加载不可信第三方代码，需要 MPU/process/WASM 等另一个
隔离层，不能把 capability set 宣称为安全沙箱。

### 系统资源使用租约

网络、BLE advertising/scanning 与 voice analyzer 使用固定容量 owner-aware lease，
而不是“最后一次 bool 写入获胜”。Foreground lease 在 App 实际完成 transition swap
的同一帧、command commit 前自动回收；Session 由会话结束释放；Persistent 仅允许
受信 System/平台 owner，普通 App 会被拒绝。资源 desired state 从 owner count 推导，
所以一个 App 退出不会错误关闭另一个 owner 正在使用的资源，最后一个 owner 释放后
才停止硬件。acquire 幂等，unknown release、容量失败、自动清理与 high-water 都有
计数器。

### Voice session、隐私与 backpressure

capture coordinator 固定输出 48 kHz、S16、mono、480-sample/10 ms blocks。
Analyzer 与 USB 各有容量 4 的 SPSC queue；慢 consumer 只丢自己的 newest block，
不阻塞采集也不破坏另一个 consumer。USB 再切成 48-sample/1 ms packets，underflow
发等长静音，disconnect/alt inactive 清除 stale data。任一 consumer active 时全局
显示 `MIC`；USB streaming 时默认抑制系统 cue，避免扬声器被板载麦克风回录。

T-Embed 候选输入由 ES7210/I²S1 adapter 独占，输出由 I²S0 adapter 独占；两者不得
共享 task、DMA 或可变 buffer。当前自动化覆盖 portable 语义和各自构建，真实并发、
左右通道、增益、时钟和声学泄漏仍是到货后的硬件门禁。

## 后续平台工作

1. 增加应用级持久化存储命名空间；
2. 根据真机测量决定是否复用 Gallery/Runtime 的离屏 framebuffer；
3. 实现 Sharp presenter，并在实体屏上对比 400×240 快照；
4. 根据实体 T-Embed 试听选择默认音色，并在需要时实现 sample voice；
5. 定义休眠、背光/对比度等系统服务，而不是让应用直接操作硬件。
6. 为 Wi-Fi provisioning、凭据、BLE service/RF coexistence 单独建立 OpenSpec，
   复用 platform-event → service state machine → snapshot/command，不暴露 raw socket
   或 GATT callback。

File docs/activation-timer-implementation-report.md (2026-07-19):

# Activation Timer 实现与验证报告

日期：2026-07-19  
OpenSpec changes：`build-activation-timer-app`、`polish-activation-timer-presentation`

## 产品行为

首个可用 App 使用 `TimerApp` / `kTimerAppId` 和获批的 TIMER Launcher Cover，
catalog 数值仍为 `0x0101`，旧 Clock C++ 符号、兼容 alias 与 Cover 资产均已删除。
内部功能为单任务 Activation Timer：

- Ready 默认 10 分钟，旋钮以整分钟在 1–99 分钟间循环设定，短按开始；
- Running 短按暂停，误转旋钮只给 Boundary，不修改 deadline；
- Paused 旋钮按整分钟增减并将秒数归零，短按继续；
- 离开 Timer、回 Launcher、打开 System Menu 或切换其他 App 时继续计时；
- 到期由 system-owned critical alert 抢占当前界面，确认后回到最近配置时长；
- Reset 不加入 System Menu。首版用 Paused 调整和到期后保留时长覆盖重设需求，
  避免为单个 App 引入长期的 Menu contribution 契约。

## 架构边界

`TimerService` 是 `SystemServiceHost` 持有的单一权威状态机。App 只能读取冻结的
`TimerSnapshot`，并通过 `TimerControl` capability 提交 Start/Pause/Resume/
SetRemaining 命令；只有 system owner 能 Acknowledge。service 固定状态、无 callback、
无平台 handle、无逐操作堆分配。

计时真相使用 64-bit 单调毫秒 deadline：firmware 注入
`esp_timer_get_time()/1000`，SDL 注入 `SDL_GetTicks()`，headless 注入模拟时间。
presentation `dt` 仍可为零或被限制到 50 ms，不影响倒计时。timestamp 回退被拒绝且
不能增加 remaining；一次大步跨越只产生一个 expiration generation。

Timer Alert 高于 System Menu。到期时若按钮 sequence 已开始，第一次 release 只解除
capture，必须下一次完整短按才确认。Alert active 时 App update 和 transition 均冻结，
system service 仍推进。后台 Running/Paused Timer 在 owner App 外显示向上取整的
`T 08` / `P 08` 指示，owner 前台不重复显示。

## 声音

新增第 16 个语义 `TimerComplete`，不改变原 15 项 PCM golden。最终候选为三次
清脆上行铃击：783.99 Hz 位于 0 ms、1046.50 Hz 位于 140 ms，第三击在
290 ms 叠加 1318.51/1567.98 Hz 明亮和弦；最后非零采样在 699.841 ms。
44.1 kHz / S16 / mono 一秒 PCM FNV-1a 为 `0xF5AB40E42CF75F78`，导出 WAV
SHA-256 为 `85c913ef78cbab8221c2774eeac184072ac54e91cde29f6a59ce6727ffdf5fda`，
峰值 5622，RMS 1275.800。

到期 edge 立即播放一次，此后每 2 秒当前帧至多再请求一次，不补播卡顿期间错过的
历史重复。Muted 下 PCM 保持全零但 alert 完整；Acknowledge 走 StopAll 安全邮箱，
清除 active voice、scheduled event 和已排队提醒。

## 自动化证据

- TimerService：Ready/Running/Paused/Expired、1/99 分钟、inclusive deadline、
  pause/resume、07:18 + 2 分钟、timestamp regression、large step、single
  generation、deterministic replay、owner/state/duration 和零分配；
- command/frame：默认拒绝 capability、commit 再校验、FIFO、update/render snapshot、
  `dt=0` 与 clamp 独立、Muted、repeat no-backlog 和 acknowledge stop；
- App/surface：Ready/Running/Paused/Expired 输入、离开 App、后台 indicator、Menu
  preemption、held-button sequence、transition freeze、双 profile alert golden 和
  alert 零分配；
- presentation：双 profile 原生 Timer 数字 atlas、`10:00`/`05:00`/`00:01`
  等宽与冒号光学中心、Starting/Pausing/Resuming 粗扫光首/中/末帧、Reduced
  Motion 静态双框及 onEnter/onExit 清理；
- Menu：mask 在 panel 尚未到达的整屏区域渐现、opening/closing 同进度逐像素反向
  等价、fully-open 与稳定 Menu 逐像素相同；
- Cover：1400×620 平滑母稿、350×155 与 280×124 PBM/header 可复现、reflective
  palette、静态 Cover、launch/return endpoint 与 30 FPS 邻帧变化门禁；
- E2E：Launcher → Timer → Start → System Menu Home → Expire → Acknowledge →
  Timer → Start，以及桌面真实 InputReducer 路径；
- 320×170 Ready hash `12921254497184521768`，400×240 Ready hash
  `4523606151491982558`；两个 PNG、Timer Alert、Menu 与 handoff PNG 已人工检查；
- 当前 macOS ABI：`SystemSnapshot` 88 B、`TimerService` 64 B、
  `SystemSurfaceCoordinator` 208 B，仍不新增第三块 framebuffer；
- normal host suite 77/77、warnings-as-errors 与 ASan+UBSan host suite 76/76
  均通过；最终粗扫光改动另在 strict/sanitized allocation 与 App 关键帧 focused
  suite 通过；SDL 3.4.12 dummy
  T-Embed/Sharp 实进程通过；OpenSpec、source/research/naming audit 均通过；
- PlatformIO 6.1.19、`espressif32@6.12.0`、Arduino-ESP32 2.0.17 实际编译通过：
  RAM 100,112 / 327,680 B（30.6%），Flash 433,029 / 3,145,728 B（13.8%），
  `firmware.bin` SHA-256
  `659a9d49d04dee0c8f982e124c770af656807bf875df00ae55059de47948b5c0`；
- ESP-IDF v5.5 候选共享源码图也实际编译通过，包含 `timer_service.cpp`：
  image 1,242,819 B，生成 bin 1,242,928 / 1,536,000 B，尚余 293,072 B（19%），
  SHA-256 为
  `45601e5f9c01ea2550f60d15747db6d46c8d0ebf63f1ebd7dc75b16e327e8c69`。

## 仍需实体设备确认

自动化不能替代真实旋钮 detent 速度、1–99 分钟循环调节手感、T-Embed 屏幕可读性、
扬声器响度/疲劳感、外壳共振和长时间运行。软件实现已经完成，但 TimerComplete 最终
音色和 2 秒重复间隔在实体试听前仍是候选；deep sleep、断电/重启恢复也明确不在本次
范围内。

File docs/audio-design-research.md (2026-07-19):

# Cadenza 交互声音与 Playdate 听感调研

> 状态：源码参考、公开实机样本和平台边界调研已完成；最终实体 T-Embed 听感仍是实现后的硬件验收项。完整参考矩阵见 `docs/audio-reference-research.md`，采纳边界见 `docs/audio-engine-adoption-decision.md`。

本调研服务于 Cadenza 的系统交互声音，不讨论背景音乐、语音或录音。资料优先采用平台厂商、芯片厂商与硬件厂商的一手文档；“事实”“设计推论”“待验证”分开记录，避免把审美判断冒充硬件结论。

## 结论

Cadenza 不应追求“低采样率等于复古”的表面效果。Playdate 的 1-bit 视觉背后是 44.1 kHz 的现代音频系统；其值得继承的是约束方法：短促、克制、与动作同步、在小扬声器上成立、允许静音、永远不承担唯一信息通道。

Cadenza 的声音意象定为“纸张视觉 × 精密小机构 × 微型数字乐器”。实现从首轮 Triangle/Square 草案收敛为四声部 Semantic Hierarchy：Sine 共振与指数衰减承担低调、圆润的触点，Triangle/Square/Noise 保留给方向、边界和拒绝；确认/开启使用上行动势，返回/关闭使用下行动势，旋钮 tick 需要冷却而不能排队轰炸。

## 已拍板的 Semantic Hierarchy

当前 Semantic Hierarchy 共 17 项，另有 TimerComplete 业务 cue；按信息重要度控制密度，而不是让所有操作复用同一个滑音：

| 家族 | Cue | 设计职责 |
| --- | --- | --- |
| Input | Navigate、Boundary | 高频操作的低调触点；到边界必须与移动成功不同 |
| Action | Confirm、Back、ToggleOn、ToggleOff、Reject | 用方向、时序和材质区分进入/返回、状态开/关与未执行 |
| Surface | MenuOpen、MenuClose | 与菜单形变同帧的单动作上扬/下潜，不借用 Confirm/Back 双敲 |
| Outcome | Complete、Warning、Failure | 只用于确有结果的较重要事件，允许更完整但仍短促的结构 |
| System | Notification、Connect、Disconnect、PowerOn、PowerOff | 用于非直接输入或硬件生命周期，不伪造不存在的触发点 |

Navigate/Select v6 与 ToggleOn/ToggleOff 已在本地 A/B 试听中获用户接受；正式实现只保存重新创作的合成参数，不嵌入三个参考 WAV。Select 使用四个约 1.64–5.84 kHz 的极短阻尼共振器；Toggle 以两个错时事件和相反方向提高 On/Off 区分度。详细测量、相似度和 fallback 边界见 [`audio-palette-calibration.md`](audio-palette-calibration.md)。

## Playdate 公开实机样本分析

样本来自公开的 [Playdate - Unboxing and Setup](https://www.youtube.com/watch?v=OwCXGcFwhJI)，不是 Playdate SDK 或系统资产。分析保留原视频时间轴，以 44.1 kHz 解码公开音轨、2,048-sample Hann window / 256-sample hop 查看频谱，并用对应视频帧确认动作：

| 时间点 | 画面动作 | 可观察声音 | 设计影响 |
| --- | --- | --- | --- |
| `10:29.15` 附近 | System Menu 从 `screenshot` 移到 `saved` | 约 40 ms 的稳定短音，主峰约 860 Hz | Navigate 应非常短、单一、轻，不承担奖励感 |
| `10:34.00–10:34.20` | 关闭 System Menu，回到 Launcher | 约 0.2 s，从约 940 Hz 向约 660 Hz 下行 | Back/Close 用下降轮廓表达收束，长度仍明显短于转场动画 |

录像包含讲解人声、房间声、视频压缩和相机/设备距离未知，因此以上是“数量级与轮廓证据”，不是对 Playdate 私有母带的精确还原。Cadenza 不复制这些频率或声音；参数将重新创作。最重要的观察是：Playdate 的日常系统反馈并不持续铺底，也不使用夸张的 chiptune 乐句。

## 一手资料事实

### Playdate：复古外观不等于受限音频

- [Designing for Playdate](https://help.play.date/developer/designing-for-playdate/) 明确说明 Playdate 可播放 44,100 Hz 的压缩或未压缩音频，并要求在设备扬声器与耳机上验证低频缺失、峰值噪声和样本响度一致性。
- [Inside Playdate / Sound](https://sdk.play.date/inside-playdate) 记录了短样本内存播放、长文件流式播放、ADPCM/MP3/PCM、实时 synth、channel、signal 与 effect。合成器提供正弦、方波、锯齿、三角、噪声、wavetable、ADSR、音高/振幅调制；说明“computer-y”是可选择的音色，不是硬件上限。
- [Playdate Pulp](https://play.date/pulp/docs/) 把声音创作压缩成五种 voice（sine、square、sawtooth、triangle、noise）、音符网格和 ADSR。Sound 只允许单 voice、最多四小节；Song 才允许五 voice、最多 32 小节。这个产品分层证明：交互短音值得拥有比音乐更严格的创作边界。
- Pulp 文档还允许 Launcher 卡片配置 launch sound。声音不是游戏启动后的附加物，而可以与 Launcher 的选中、启动动画共同组成第一次接触。
- [Playdate UX 与无障碍检查清单](https://help.play.date/developer/user-experience-checklist/) 要求音量一致且不过响，在真实 Playdate 和多种环境中试听，并为依赖声音的玩法提供可见提示。
- [Playdate 用户手册](https://help.play.date/hardware/manual/) 把系统音量作为随时可调的全局能力，而不是由单个游戏各自解释。

### 通用交互反馈：重要程度、可关闭、重复变化

- [Apple HIG: Feedback](https://developer.apple.com/design/human-interface-guidelines/feedback) 要求反馈强度与信息重要程度匹配，并建议用视觉、声音、触觉等多种通道共同表达，避免声音成为唯一通道。
- [Apple HIG: Playing audio](https://developer.apple.com/design/human-interface-guidelines/playing-audio) 指出非必要交互音应服从静音与用户音量预期；重复声音可以轻微改变音高与音量以降低机械疲劳。
- 这并不意味着随机化每次 cue 的语义音程。系统反馈的方向性必须稳定；只允许不改变身份的微小变化。

### T-Embed 与 ESP32-S3：原型硬件已经具备数字音频链路

- [LILYGO T-Embed 官方资料](https://wiki.lilygo.cc/products/t-embed-series/t-embed/) 记录原版设备带 MAX98357A I²S 放大器与内置扬声器。
- [LILYGO 官方 sound 示例](https://github.com/Xinyuan-LilyGO/T-Embed/tree/master/examples/sound) 将 BCLK/WCLK/DOUT 分别定义为 GPIO 7/5/6，并使用 I²S 输出。厂商示例把库音量设为最大诊断值 21；这不能直接当作产品默认响度。
- [Arduino-ESP32 I²S 文档](https://docs.espressif.com/projects/arduino-esp32/en/latest/api/i2s.html) 支持标准 I²S、mono/stereo、8/16-bit 与可选引脚映射。Cadenza 只需 44.1 kHz、16-bit mono PCM，不需要媒体解码框架。
- ESP32-S3 的 [LEDC 文档](https://docs.espressif.com/projects/esp-idf/en/latest/esp32s3/api-reference/peripherals/ledc.html) 也能产生 PWM，但 T-Embed 已有 I²S DAC/功放链路；使用 LEDC 蜂鸣器会主动丢失现有硬件能力，且不利于未来 sample voice，因此不选。

## 从 Playdate 推导出的 Cadenza 原则

以下为设计推论，不是 Panic 对其系统私有音色参数的公开说明。

### 1. 语义先于波形

声音应绑定“选择真的改变”“切换真的完成”“动作被拒绝”，而不是绑定 GPIO 边沿。相同点击在不同状态下可以是 Confirm、Toggle 或 Reject；只有 Runtime/App 知道结果。

### 2. 声音与动画共用动作方向

| 语义 | 视觉动作 | 声音轮廓 |
| --- | --- | --- |
| Navigate | 选择卡片弹一下 | 极短、干燥、单音 |
| Confirm | 内容展开/进入 | 上行二音或上滑 |
| Back | 内容收回/返回 | Confirm 的下行镜像 |
| MenuOpen | Surface 从右侧牵开 | 低音区单起音上扬，音身短于动画 |
| MenuClose | Surface 向右卷收 | 同族单起音下潜，收尾比展开更干脆 |
| ToggleOn | 开关进入活跃态 | 短上滑 |
| ToggleOff | 开关进入安静态 | 更短下滑 |
| Boundary | 位置不再移动 | 低、钝、少量噪声 |
| Reject | 动作未执行 | 与成功音不同的短噪声脉冲 |

### 3. 舒适来自密度控制

- 一个 `InputFrame` 即使聚合多个 detent，也只触发一个 Navigate。
- Navigate 设置最短重触发间隔；窗口内请求直接丢弃，不排队补播。
- 错误音不能比成功音更响，只需更容易区分。
- 重要完成音必须稀少；日常选择不应借用“奖励”动机。

### 4. 小扬声器是母带目标

电脑音箱能重放的低频可能在 T-Embed 上消失；裸方波高频又可能在小声腔中显得尖锐。首版集中使用中频、短 attack/release 和保守 gain，最终频率与响度必须在实体设备上调整。

## 首轮参数范围（历史设计起点）

| Cue | 建议时长 | 方向 | 原语 | 重复策略 |
| --- | ---: | --- | --- | --- |
| Navigate | 28–40 ms | 轻微上扬或固定 | triangle + 低增益 square | 约 20 ms 冷却 |
| Boundary | 45–70 ms | 下落 | triangle/noise | 不排队 |
| Confirm | 90–140 ms | 上行 | 两个 triangle voice | 高优先级 |
| Back | 80–130 ms | 下行 | 两个 triangle voice | 高优先级 |
| Toggle | 60–100 ms | on 上行/off 下行 | triangle/square | 状态改变才播放 |
| Reject | 60–100 ms | 不规则下落 | noise + triangle | 高于 Navigate 优先级 |

所有范围都必须满足：开头和结尾不在峰值硬切、混音饱和而不环绕、Muted 立即清空 voice。

该表保留为设计演进记录，不再是当前 palette 的实现约束。获批 Select 约 10 ms，Toggle 约 63–65 ms，MenuOpen/MenuClose 约 160/140 ms；当前 18 项枚举的精确参数与 golden 以 `sound_cue_library.cpp` 和测试为准，最终扬声器 gain 仍由真机决定。

## 评估矩阵

自动化可以证明：

- PCM 格式、确定性、非零输出、最终回零；
- 包络首尾、音高方向、复音抢占、饱和；
- Navigate 冷却、静音、Settings 文案和 Runtime 路由；
- SDL/firmware 构建与设备失败降级。

自动化不能证明：

- T-Embed 声腔中的实际响度、刺耳程度与低频可闻性；
- 旋钮连续操作一分钟后的疲劳感；
- 动画可见冲击与扬声器出声之间的端到端延迟；
- 最终 Sharp 定制硬件上的音色迁移效果。

## 真机验证脚本

1. 系统音量 Medium，距离设备约正常手持距离；慢转 24 格，确认每次有效选择有反馈且无爆音。
2. 一秒内快速转动多格，确认声音密度被抑制、不在停止后继续补响。
3. 连续执行打开/System Menu Home 20 次，确认 Confirm/Back 方向可辨且 Menu/转场起点同步。
4. 在 Settings 循环 High → Muted → Low → Medium；Muted 切换瞬间不得残留尾音，视觉仍完整表达状态。
5. 分别在安静室内、普通环境噪声下试听；检查 Low 可用、Medium 舒适、High 不破音。
6. 录制扬声器输出并检查直流点击、削顶和明显缓冲间断；记录固件 FPS/最慢帧，确认 I²S 不破坏图形交互。

通过以上实体步骤前，项目只能声称“音频逻辑、输出链路与构建已验证”，不能声称“最终听感已验收”。

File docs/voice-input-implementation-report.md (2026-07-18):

# Portable Voice Input 实现与自动化证据

日期：2026-07-18

本报告只覆盖 portable/system/headless 与 current firmware build 证据。没有实体
T-Embed，因此不代表 ES7210 真实采音、macOS 枚举、录音质量、USB 时钟稳定或
Wi-Fi/BLE 射频共存通过；这些项目继续标记为 hardware validation pending。

## 已实现契约

- 固定 PCM：48,000 Hz、signed 16-bit、mono、10 ms / 480 samples；
- 单一 `VoiceCaptureCoordinator` 聚合 Analyzer/USB consumer intent，并区分
  unavailable、stopped、starting、running、error；
- Analyzer 与 USB 各自使用容量 4 的固定 SPSC queue，producer 不等待，满时对
  该 consumer 执行 drop-newest 并累计 overrun/high-water；
- Analyzer 输出 RMS、peak、clipping 和带 attack/release 的基础 VAD；App 只能从
  `SystemSnapshot.voice` 读取结果并提交 analyzer start/stop command，不能取得 PCM；
- 任一 consumer active 时 frame coordinator 绘制持续 `MIC` 隐私标记；USB active
  时 SoundCue 默认抑制并累计 `suppressedSoundCues`；
- USB packetizer 把一个 480-sample block 切为十个 1 ms / 48-sample packet；
  underflow 补同长度 silence，inactive/disconnect/reactivation 清除 stale/partial data；
- `UsbVoiceSessionBridge` 用 callback-safe atomics 接收 USB mount 与 microphone
  alt-setting，数据 owner 在下一次 input callback 同步状态；close 后立即撤销 capture
  intent，generation 变化保证 close/open 夹在两次数据 callback 之间时也会 flush；
- headless microphone 可注入 silence、constant、sine、speech burst、error 和
  consumer overrun，使用相同 system service/queue 路径。
- `VoiceDmaNormalizer` 接受任意长度的 32-bit DMA slot chunk，跨调用保留 partial
  stereo frame/block，支持声道选择或平均、MSB/LSB alignment、S16 saturation；
  连续 3 次 timeout/read error 后清空 partial data 并进入 capture error。

## 固定容量与资源结果

在 AppleClang 21、64-bit host 上：

| 对象 | `sizeof` |
|---|---:|
| `VoiceBlock` | 968 B |
| `VoiceCaptureCoordinator`（两个 4-block queue） | 7,840 B |
| `SystemServiceHost` | 9,728 B |

10,000-block burst 测试保持 USB sequence 逐块连续且 USB high-water 为 1；故意每
11 block 才消费一次的 Analyzer 达到 high-water 4，只增加自己的 overrun，清空后
从新 sequence 恢复。该用例包含 20,064 个断言，并在 normal、strict-warning 与
ASan/UBSan 构建下通过。

current PlatformIO/Arduino 2.0.17 firmware 在链接 portable voice core 后：

- RAM：92,824 / 327,680 B（28.3%）；
- flash：344,521 / 3,145,728 B（11.0%）；
- 相对迁移前一轮 84,696 B / 342,605 B，增加 8,064 B RAM、1,892 B flash。

这只证明当前旧 firmware 能容纳 portable 状态与队列；它尚未包含 ES7210 capture
task/DMA，也不是 ESP-IDF 5.5 UAC candidate 的最终资源数。

## 已运行门禁

```text
tools/check.sh host                       49/49 pass
strict-warning disposable build          48/48 pass (desktop target disabled)
ASan/UBSan disposable build               48/48 pass (desktop target disabled)
tools/check.sh desktop                    launch pass (SDL 3.4.12; CoreAudio unavailable in runner)
cadenza_voice_input_core_tests            5 cases / 20,064 assertions pass
cadenza_usb_voice_packetizer_tests        3 cases / 47 assertions pass
cadenza_headless_microphone_tests          3 cases / 39 assertions pass
tools/check.sh firmware                    success, size as above
openspec validate ... --strict             valid
git diff --check                           pass
```

ESP-IDF 5.5 UAC spike 直接链接 portable coordinator/packetizer/session bridge 后
成功：binary 242,256 B（`0x3b250`）；共享 descriptor contract 的 host lint 为 2
cases / 31 assertions，session bridge 为 3 cases / 28 assertions。上游 component
未公开 mic lifecycle callback，因此 candidate 在 CMake 中只对锁定的
`usb_device_uac` 1.3.1 两个 callback 名做编译期重命名，Cadenza 公共 callback
先调用原实现，再发布 alt-setting 状态。ELF 符号审计确认原实现与公共入口均存在；
未修改 managed component 源码，也未用超时猜测断连。该证据仍不能替代真机
reconnect/alt-setting 验收。

完整 hardware candidate 进一步把 portable Runtime、全部 bundled Apps、u8g2、
ESP-IDF `esp_lcd` ST7789 presenter、GPIO encoder、官方 `esp_codec_dev` 1.5.10
（component hash
`896c67360ae1f8dedaf8a53dfe48c015317fa455f061a5165307892296990028`）接入后，
同一 build 同时链接 ES7210/I²C0/I²S1 input、MAX98357A/I²S0
output、DMA normalizer、portable sound/voice、session bridge 与 UAC。构建成功，
binary 388,032 B（`0x5ebc0`），size tool total image 387,911 B，DIRAM 146,103 B
（42.75%，`.bss` 85,488 B），Flash Code 235,552 B、Flash Data 75,328 B；
1 MiB app partition 尚余 63%。
speaker 独占 I²S0/core 0/4,096 B stack/4×128-frame DMA；microphone 独占
I²S1/core 1/6,144 B stack/4×240-frame DMA，两者只使用对象内 local buffer。
UI/main task 预留 8,192 B stack，ST7789 用 8-row / 5,120 B 固定 transfer buffer，
不分配整幅 RGB565 framebuffer。ELF 审计确认 Launcher、FrameCoordinator、display
presenter、UAC lifecycle 和上游委托实现同时存在。相对 current PlatformIO build，
total image 增加 43,390 B；静态 DIRAM 增加 53,279 B，但两套 SDK 的 size 分类并非
完全同口径。host 并发模型以 496 个断言验证输出队列压力不会破坏输入 timeline。
以上仍只证明 SDK/链接/静态预算，不证明真实显示方向、输入电气、同时时钟与声学
回录。

## 仍待完成

- 真机 Mac 枚举、重连/睡眠、至少 30 分钟录音、时钟漂移、声学泄漏和 RF/功耗。

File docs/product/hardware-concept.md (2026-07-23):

# Cadenza 硬件概念设计边界

## 结论

Cadenza 后续只在产品概念和工业设计层面讨论硬件，不再由本项目产出可直接打板、代焊、开模或量产的电气与结构工程文件。专业硬件工程师和结构工程师负责器件选型、原理图、PCB、精确结构、制造资料、样机验证与最终放行。

本文记录产品意图和空间概念，不是制造依据。

## 产品意图

Cadenza 是一台属于项目所有者个人、用于日常工具、实验和轻量交互的可扩展手持设备，也可以被理解为一块带完整外壳、显示与输入的专属开发板。硬件概念应优先满足：

- 阳光下可读、低功耗的常显信息界面；
- 单手或双手均可完成的导航、确认、返回和菜单操作；
- 清晰的提示音，以及与电脑连接的能力；
- 安静、克制、耐用，避免游戏掌机式的复杂控制布局；
- 可拆卸维护主要部件，不把屏幕、排线、电池等脆弱部件永久封死。
- 未来可以重新讨论外部模块，但当前阶段先把主机自身功能、体积、操作和外观做好，不让扩展结构主导设计。

具体能力是否采用、如何实现，均由后续专业工程设计确认。

## 外观与交互概念

- 形态：横向手持设备，正面以中央屏幕为视觉中心。
- 显示：固定使用 Sharp `LS027B7DH01`，2.7 英寸、400 × 240 黑白反射式 Memory LCD；玻璃包络约为 `62.8 × 42.82 × 1.64 mm`，可视区约为 `58.8 × 35.28 mm`。
- 左侧输入：独立 `B` 与 `Menu`，用于返回和系统操作。
- 右侧输入：一个可旋转、可按压的主控制器；旋转用于导航，中心按压作为 `A/确认`。
- 其他可见元素：向机顶中央收近的 USB-C 充电口、机顶中央竖向长圆扬声器开孔阵列、机顶右侧独立 `Power/Lock` 键、屏幕凹槽上侧内壁中央的隐藏式麦克风微孔，以及机底右下角 MicroSD。USB-C 与 MicroSD 分属上、下两边，避免同时插拔干涉。
- `Power/Lock`：采用类似 Playdate 的顶部低矮胶囊形金属键，尺寸小、行程明确、不易误触；表面为细腻喷砂或缎面银色，不使用镜面高光，也不使用突兀的大型彩色电源键。
- 设计语言：参考现有 Timer 的圆润胶囊形态，正面、侧面与背面连续过渡，端部圆润，分件线克制；控制件数量少，层级清楚，避免装饰性开孔和无功能细节。
- 风格定位：整体属于 Sony 式消费电子与日系测量/文具仪器之间的克制工具感。重点是精确比例、清楚层级、低饱和配色、细小而可信的功能标识、明确但不过度暴露的分件关系；避免玩具感、电竞感、户外三防感和黑客工具感。
- 背面语言：参考 SONIC SticKURU Timer 背面“功能细节集中、其余表面安静”的秩序。设置一块居中的长圆角电池与维修盖，只保留细分件缝、少量开启防滑纹和低调紧固点；不复制其具体电池仓，不增加扩展导轨或装饰面板。
- 桌面支撑：背面采用一体成型的实心楔形后壳，从主机后壳曲面直接连续收窄到外侧平台，最大凸出约 `10 mm`。侧面外轮廓内全部为实体，交界处无肩台或分件线；斜线是后壳外轮廓，不是支撑杆。无空隙、背夹、翻板、转轴或铰链。外侧平台保留居中长圆角维修盖板，盖板中央使用同材质浅浮雕的花体 `Cadenza` 字样。机底不贴深色橡胶条，只保留两条与外壳一体成型、同色且轻微突出的纵向小棱；小棱沿机身前后厚度方向延伸。第三方必须验证内部维修路径、各摆放姿态的实际角度、重心、摩擦力、倾倒稳定性和按键操作稳定性。
- CMF：外壳使用珍珠银白、细腻哑光磨砂质感；`B`、`Menu` 与旋压 `A` 的操作面使用 `PANTONE Cool Gray 2 C` 浅灰作为颜色参考，并保持同样的哑光磨砂触感；`A/B` 字标使用偏暖的 `PANTONE Black 7 C` 深石墨灰参考，不用纯黑。`A` 旋压控制器使用约 `22.6 mm` 的低反光银蓝色窄外环（约 `PANTONE 7544 C` 方向）包围约 `20.5 mm` 哑光浅灰有效操作面，环形触觉点收敛为 10 个。所有键帽使用近似平整的宽顶面与小半径圆滑肩部，避免直筒圆柱和饱满半球；A 保留约 `1.5–1.7 mm` 可抓握侧高，B 与 `•••` 只略高于面板。顶部 `Power/Lock` 保持中性喷砂/缎面银色。不使用橙色或其他高饱和强调色。
- 潘通标注用于建立视觉基准，`C` 后缀描述的是 coated 印刷色卡，不等同于塑料色母或金属表面配方。第三方必须使用近期实体色卡，在真实树脂、纹理、丝印或镭雕工艺上打样，并在目标光源下确认色差；模型中的 RGB 近似值不能作为生产验收值。
- 屏幕边界：屏幕玻璃是整机比例锚点，安装黑边由珍珠银白前壳覆盖，可视区外只留约 `0.5–0.8 mm` 细黑收口。屏幕表面比前壳低约 `0.5–0.7 mm`，形成窄而连续的保护唇边；不做凸起屏幕或“大壳套小屏”。
- 正面对称：以屏幕中心线作为整机正面中轴，屏幕必须几何居中；左右控制区宽度完全相等。`B` 保持普通圆键，`Menu` 收缩为低矮次要胶囊键，不写文字，直接在键帽上使用三点 `•••` 标识；旋压 `A` 面径约 `20.5 mm`，作为主控制器稍大，但必须与左侧 `B + •••` 组合的整体视觉重量平衡。正面不设置任何独立麦克风黑点；麦克风拾音入口并入机顶九条等形声学槽的正中一条，左右各四条服务扬声器，内部声道和音腔必须完全隔离。
- 复古语言：参考博朗经典产品的克制比例、低饱和 CMF、清楚的操作层级、精确的圆角与标识秩序，不复制任何具体机型的外壳或控件布局。复古感应来自长期耐看的秩序，而不是装饰性仿旧。

历史探索曾使用 `130 × 60 mm` 的 PCB 平面和约 `132 × 64 mm` 的整机平面包络进行比例讨论。当前对称版主机本体约为 `120 × 50 × 16 mm`，一体式实心后壳最大凸出约 `10 mm`，因此中心最大总厚度约 `26 mm`；四周边缘仍保持圆润纤薄。屏幕玻璃上下名义余量约 `3.6 mm`，屏幕几何居中，左右控制区各约 `28.6 mm` 宽。此前 `106 mm` 的极限紧凑稿和 `114 mm` 的轻微偏心稿均因左右不协调而放弃。这些数字都只是工业设计目标，不能作为板框、外壳或开模尺寸；第三方必须结合真实器件、强度和装配重新验证。

## 已确定的必要硬件

以下是基础主机必须具备的产品能力。除屏幕外，这份清单不指定具体芯片、型号、针脚或电路实现。

- **固定屏幕**：Sharp `LS027B7DH01`，并为屏幕玻璃、可视区和 FPC 保留安全安装空间。
- **运算平台**：能够稳定运行 Cadenza OS、Launcher、1-bit 图形、动画和内置应用的主控、运行内存与程序存储。
- **主控制器**：一个可连续旋转并可按压的物理控制器；旋转负责导航和调节，按压对应 `A/确认`。
- **独立按键**：`B/返回` 与 `Menu/系统菜单`。
- **电源操作**：明确、独立且不易误触的开机、关机或锁定操作。
- **声音输出**：使用一只质量稍好的全频动圈扬声器，而不是蜂鸣器；优先保证提示音、语音和常用应用声音清晰自然。
- **声音输入**：内置麦克风，用于录音、声音感知和后续交互实验。
- **动作感知**：内置动作或姿态传感器。
- **触觉反馈**：内置振动执行器及其驱动能力。
- **便携供电**：内置可充电电池、电量检测、充电与必要的电池安全保护。
- **USB-C**：至少承担充电、固件更新、恢复和与电脑的数据连接。
- **持久存储**：内部存储用于系统和恢复，另内置 MicroSD 卡槽保存应用资源与用户数据。
- **无线连接**：基础主机具备无线通信能力；采用哪些无线标准及天线方案由第三方评估。
- **红外**：内置红外接收与发射能力；左端短边设置约 `10 × 3 mm`、与外壳齐平的深酒红烟熏长圆光学透镜，表面封闭并带轻微弧度。发射 LED 与接收器隐藏在窗内并通过内部遮光结构隔离；外观模型用一大一小两枚若隐若现的圆形光学元件暗示其功能，避免被误认为数据端口。窗口材料、红外透过率、发射距离和有效角度由第三方结合真实器件验证。
- **NFC**：内置 13.56 MHz NFC 读写及模拟能力。
- **Sub-GHz**：内置 Sub-GHz 收发能力；可用频段和发射能力必须遵守销售或使用地区法规。
- **维护与恢复能力**：设备在系统或固件异常时仍可刷写、恢复和诊断。
- **完整产品结构**：前后壳、屏幕保护、控制件、扬声器音腔和可维护的装配方式。

## 声音产品目标

- 扬声器优先朝向正面或上方，不能被桌面或正常握持明显遮挡；当前概念把细密扬声器孔移到顶部斜面，以便屏幕尽量占满正面高度。
- 扬声器长圆开孔内侧覆盖一整片细密声学防尘网。麦克风使用屏幕凹槽上侧内壁中央的侧向隐藏微孔，正视时由前壳保护唇遮挡。外观微孔可通过密封声道将实际麦克风单元横向引开，并与扬声器独立音腔、壳体振动做软隔离；若需在播放时拾音，还应预留回声消除能力。网材、目数、声阻、防水防尘等级与固定工艺由第三方通过声学样机确认，不得导致可感知的音量或高频损失。
- 概念包络可按约 `20 × 30 mm` 至 `30 × 40 mm`、深度 `4–7 mm` 的单只全频扬声器预留，并留出约 `5–15 cm³` 的独立密闭后腔讨论空间。
- 在 `0.5 m` 距离，常用音量可先以约 `65–75 dBA` 为目标，最大音量约 `80 dBA` 且不出现明显破音；优先覆盖约 `400 Hz–10 kHz`，常用音量下 `500 Hz–8 kHz` 的 THD 概念目标小于 `5%`。
- 不接受壳体共振、杂音、明显底噪或开关机爆音。麦克风、马达与扬声器应彼此隔离，降低串扰。
- 上述数字是第三方声学设计与样机验收的起点，不是当前模型已经实现的性能。第三方必须用量产结构样机验证扬声器与功放匹配、音腔、频响、声压、失真、握持/桌面遮挡、麦克风串扰、振动串扰、温升和功耗。

## 尚未确定是否内置

以下能力可以有价值，但目前不属于已经确认的基础硬件：

- 独立实时时钟；

## 已明确不做

- 不内置 GPS，也不把 GPS 扩展模块列为产品必做内容。
- 不内置温度、湿度、气压或空气质量等环境传感器，也不把环境传感器扩展模块列为产品必做内容。

## 未来扩展方向（当前暂缓）

曾讨论过借鉴 Flipper Zero / Flipper One 的外部模块思路，但当前阶段不把扩展接口列为基础主机的必要硬件，也不在外观上设置扩展仓、背部导轨或外接模块。先完成一台体积紧凑、功能完整、外观干净的主机。

未来重启扩展设计时，再重新评估以下体验目标：

- 不打开主外壳即可连接和更换扩展模块；
- 扩展区域有明确方向，尽量避免插反、错位和意外短路；
- 模块安装后不遮挡屏幕、主要按键、扬声器和 USB；
- 可以连接常见的数字模块、简单传感器、灯光、旋钮或实验附件；
- 主机能够识别或由用户选择当前附件，并在软件中提供对应入口；
- 不使用扩展时，接口可由保护盖或结构设计隐藏，保持整机外观完整；
- 外壳概念应考虑小型直插模块、短线连接和较大背负式附件三类形态。

当前 3D 模型不为扩展接口占用外部空间。未来若恢复这一需求，不在概念阶段自行规定 GPIO 数量、总线类型、针脚定义、电压、电流、热插拔、ESD、防反接或连接器型号；这些内容必须由专业工程师统一设计和验证。

首批可以讨论的附件方向包括：

- 其他用途的实验传感器；
- 灯光或其他有线控制附件；
- 无线或红外实验模块；
- 面包板转接、调试和个人创作模块；
- 改变握持、摆放或佩戴方式的纯机械附件。

这些只是产品可能性，不代表基础设备必须内置所有对应硬件。

## 内部空间概念

概念模型可以用简单包络体表达以下内容及相互位置：

- 屏幕、可视区及排线弯折空间；
- 主板区域和安装平面；
- 电池及线材出口；
- 扬声器与音腔；
- USB 接口和插拔空间；
- 旋转编码器、按键及其按压行程；
- 麦克风及声孔；
- 螺钉、外壳分件和基本拆装路径。

包络模型只回答“能否大致容纳、比例是否合理、操作位置是否自然”，不回答电气连接、精确堆叠、公差、强度、散热、声学或可制造性。

## 3D 概念模型交付

必须交付：

- 外观曲面和整体比例模型；
- CMF、颜色、纹理与表面处理提案；
- 正视、侧视、剖视、爆炸图和场景渲染；
- 内部器件包络和空间分区；
- 用于人体工学讨论的低成本外形样机；
- 提供给专业工程师的 STEP 概念参考或设计 brief。

当前 V1 参数模型位于 `assets/industrial-design/3d/`，包含可编辑的 OpenSCAD 源文件、3MF、STL、CSG 与预览图。它表达约 `120 × 50 × 16 mm` 的严格对称横向主机、最大凸出约 `10 mm` 的一体式实心后壳、下沉屏幕包络和主要控制件位置，不包含外部扩展结构。

不应把概念模型用于 CNC、开模或最终 3D 打印装配。固定柱、卡扣、壁厚、拔模、圆角、公差、材料收缩、按键手感、连接器方向、排线折弯和装配顺序均须由专业人员重新设计并实测。

## 专业工程交接内容

进入实物开发时，本项目只向专业人员提供：

- 功能清单与优先级；
- 用户流程和输入语义；
- 外观方向、目标尺寸范围及内部空间意图；
- 屏幕、输入、音频、连接和续航目标；
- 若未来恢复扩展需求，再补充附件使用场景、安装形态和安全目标；
- 概念 3D 模型、渲染图和未决问题清单；
- 成本、可维护性和样机阶段的验收目标。

专业人员必须重新完成并负责：

- 器件选型、原理图、PCB、天线、电源、USB 与音频设计；
- 精确结构、堆叠、公差、材料、强度、散热与声学设计；
- BOM、Gerber、CPL、DFM/DFA、生产测试及认证；
- 样机调试、可靠性验证、制造复核和下单放行。

## 这次教训

规则检查、仿真、导入成功、零碰撞或文件可上传，都不能独立证明一块板或一套结构可以制造并可靠工作。无法由项目所有者理解、复核和承担验证成本的工程交付，不应被描述为可下单设计。

今后所有相关交付必须显著标注为“概念设计”，并区分：

- 已确定的产品需求；
- 供专业人员参考的设计建议；
- 必须由专业工程验证的未知项。

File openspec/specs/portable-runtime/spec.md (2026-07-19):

# portable-runtime Specification

## Purpose
定义 Cadenza OS 1-bit 互动运行时的可移植边界，包括 App 生命周期、输入语义、平台适配、模拟时间、诊断和明确的非游戏引擎范围。
## Requirements
### Requirement: Runtime scope is explicit
The project SHALL define the current deliverable as a 1-bit interaction and animation runtime for Cadenza OS, while physics, collision, Tilemap, ECS, and level systems SHALL remain outside this change.

#### Scenario: Scope is reviewed
- **WHEN** a contributor reads the project and change documentation
- **THEN** the runtime goals and excluded game-engine capabilities are stated without contradicting the long-term personal-platform vision

### Requirement: Core is standard C++
Application, runtime, input semantics, graphics, and animation headers and sources SHALL compile as C++17 without Arduino, ESP32, TFT_eSPI, or SDL headers.

#### Scenario: Host compiles the core
- **WHEN** the host build compiles all core sources
- **THEN** it succeeds without defining Arduino compatibility shims

### Requirement: Platform dependencies are adapters
Hardware time, raw input, logging, memory metrics, and framebuffer presentation SHALL enter the core through explicit adapters or injected values; T-Embed, desktop, and future Sharp presentation SHALL not change App behavior contracts.

#### Scenario: Platform headers are audited
- **WHEN** core include and source trees are searched for platform APIs
- **THEN** direct `Serial`, GPIO, `millis`, `micros`, TFT_eSPI, and SDL usage is absent

### Requirement: Simulation time is controllable

The runtime SHALL update applications and animations only from an injected presentation/simulation delta, while system deadline services SHALL use a separately injected nondecreasing monotonic time; pausing or clamping presentation delta SHALL not silently pause or shorten a running Timer.

#### Scenario: Simulation is paused
- **WHEN** monotonic time and input polling continue while presentation simulation delta is zero
- **THEN** App and animation state do not advance while a Running Timer remaining value continues to follow its monotonic deadline

#### Scenario: Long frame is clamped for presentation
- **WHEN** one platform frame stalls for 2 seconds and presentation delta is clamped to 50 ms
- **THEN** animation receives 50 ms while TimerService observes the full monotonic advance and does not gain 1.95 seconds

### Requirement: Logging is optional and structured
The core SHALL emit diagnostics through an optional sink and SHALL behave correctly with a no-op sink.

#### Scenario: Runtime has no logger
- **WHEN** an App transition runs without a configured log sink
- **THEN** the transition completes without platform calls or null access

### Requirement: Input semantics are shared
Raw turn and button events SHALL be reduced by one core `InputReducer` into a per-frame `InputFrame` containing saturated turn delta, press, release, click, long-press, and held duration.

#### Scenario: Short press is reduced
- **WHEN** a button-down and button-up occur after debounce but before the long-press threshold
- **THEN** exactly one click and one release are delivered and no long-press is delivered

#### Scenario: Long press is reduced
- **WHEN** a button remains down through the configured long-press threshold
- **THEN** exactly one long-press is delivered and release does not produce a click

#### Scenario: High-speed turn input is accumulated
- **WHEN** raw turn deltas exceed the range of an 8-bit signed integer before a frame is taken
- **THEN** the frame preserves the value within the documented 16-bit saturation bounds rather than wrapping

### Requirement: Application lifecycle is platform-independent

Launcher, Timer, Motion, Settings, and Gallery SHALL implement the same static App lifecycle and registry contract on firmware, headless host, and desktop simulator; the configured Home App SHALL be reached through an explicit System Menu action rather than a direct long-press transition. System Menu SHALL suspend the active App without changing AppId, while system-owned Timer state continues independently. Timer service remaining active SHALL NOT imply that its passive status indicator is visible on non-Home Apps.

#### Scenario: App is switched
- **WHEN** the runtime opens a registered App and completes its transition
- **THEN** the outgoing App receives `onExit`, the incoming App receives `onEnter`, and only the active App receives normal updates

#### Scenario: System Menu gesture is used
- **WHEN** any stable App receives long-press
- **THEN** the runtime opens the system-owned Menu over that App without changing current AppId or emitting App exit/enter

#### Scenario: System Menu returns Home
- **WHEN** a non-Home App is active and the user confirms Home in System Menu
- **THEN** the Menu closes and the runtime initiates a normal transition to the composition root configured Home App without App-specific hardware handling

#### Scenario: Active App is suspended by Menu
- **WHEN** System Menu remains active for one or more frames
- **THEN** the active App receives no normal update/input/render until resume, system services continue, and resume does not emit App exit/enter

#### Scenario: Timer owner leaves foreground
- **WHEN** Timer App starts a Timer and transitions to Launcher or another App
- **THEN** Timer App stops receiving normal updates but the Timer service remains owned, continues toward its deadline, remains visible in system snapshot, and its passive indicator is shown only while Home/Launcher is the current App

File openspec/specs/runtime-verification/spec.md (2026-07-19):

# runtime-verification Specification

## Purpose
定义 core、headless、desktop 与 firmware 的分层验证、golden/snapshot、共享源码审计、性能预算和实体设备声明规则。
## Requirements
### Requirement: Development follows a TDD gate
Every behavior introduced by this change SHALL first have an automated test or executable failing case that demonstrates the missing contract, followed by implementation and relevant regression verification.

#### Scenario: A capability task is completed
- **WHEN** an implementation task is marked complete
- **THEN** its associated test is present, was capable of failing before implementation, and passes after implementation

### Requirement: App lifecycle is tested
Automated tests SHALL cover registration, initial entry, open guards, `onExit`/`onEnter` order, transition input freeze, System Menu input ownership, suspend-with-snapshot, transition defer, explicit Menu Home return, capacity diagnostics, and both framebuffer profiles.

#### Scenario: Lifecycle suite runs
- **WHEN** the host test suite / runtime test target executes lifecycle cases
- **THEN** it proves the opening and closing button sequences do not leak, Menu active freezes App update/render without exit/enter, system services continue, transition-time Menu requests open on the stable destination, and Home uses the configured normal Back transition

### Requirement: Input state machine is tested
Automated tests SHALL cover debounce, short press, long press, release, repeated samples, turn direction, saturation, and frame reset behavior without GPIO.

#### Scenario: Boundary timing is tested
- **WHEN** release occurs immediately before, at, and after the long-press threshold
- **THEN** click and long-press outputs match the defined inclusive boundary

### Requirement: Transitions are tested

Automated tests SHALL cover every direct transition endpoint, representative midpoint, lifecycle swap, interruption guard, and source/destination immutability. Staged handoffs SHALL additionally cover pre-midpoint App launch-frame or Cover-bridge composition, exact continuity across the midpoint buffer swap, post-midpoint destination composition, direction routing, per-App distinction, fallback, motion profiles, 30 FPS adjacent-frame change bounds, fixed return Cover geometry, and the absence of a third full-screen buffer. System Menu tests SHALL cover monotonic open/close motion, closing input ownership, frozen App lifetime, one-shot sound/diagnostics, and release after full exit.

#### Scenario: Transition suite runs
- **WHEN** direct and staged transitions are rendered from known source, bridge, and destination patterns
- **THEN** golden endpoint, phase, midpoint-continuity, and direction results match for both profiles where resolution affects geometry

### Requirement: Tween numerical behavior is tested
Automated tests SHALL cover every easing endpoint/interior sample, Tween start/mid/end, delay, completion, seek, Sequence, Parallel, and Timeline offsets.

#### Scenario: Tween golden vectors run
- **WHEN** the animation numerical suite executes
- **THEN** all values and state transitions match exact or epsilon-appropriate expectations

### Requirement: Reverse and repeat behavior is tested
Automated tests SHALL cover reverse playback, yoyo, repeat count, repeat delay, boundary crossing, and infinite-repeat safety.

#### Scenario: Repeat boundary is crossed with a large delta
- **WHEN** one update spans multiple repeat boundaries
- **THEN** final value, repeat state, and callback count match the defined traversal semantics

### Requirement: Both display profiles have snapshots

Approved screenshot/framebuffer snapshots SHALL cover Launcher, Clock, Motion, Settings, Gallery, system menu/overlay surfaces, and representative transitions at 320×170 and 400×240. Typography migrations SHALL update the full matrix rather than a single representative screen, and failures SHALL emit inspectable lossless PNG output.

#### Scenario: Snapshot regression runs
- **WHEN** deterministic fixed-step scenes render their capture frames after the typography migration
- **THEN** dimensions and framebuffer hashes match approved snapshots or fail with inspectable PNG output for the exact App, surface and profile

#### Scenario: Launcher interaction regression runs
- **WHEN** automated Launcher cases exercise loop boundaries, repeated and reversed turns, both Motion profiles, orientation switching, and click before settle
- **THEN** logical selection, continuous visual position, immutable Cover pixels, opened App, command count, geometry/text diagnostics, and final stable frames match the launcher-card-navigation contract

### Requirement: Simulator tests require no hardware
All unit, integration, deterministic replay, screenshot, and desktop smoke tests SHALL run without a connected T-Embed or physical display.

#### Scenario: Clean host executes tests
- **WHEN** tests run on a macOS host with build dependencies but no serial or GPIO device
- **THEN** the complete P7 host suite passes

### Requirement: Build matrix is verified
Completion SHALL require successful host tests, SDL3 desktop build, desktop smoke/E2E, and PlatformIO T-Embed compile, plus `git diff --check` or equivalent whitespace validation.

#### Scenario: Change completion is audited
- **WHEN** P0–P7 are claimed complete
- **THEN** fresh command output proves every required build and test gate and lists P8 as the only intentionally unexecuted phase

### Requirement: 新版 Cover 的来源、端点与固件成本可验证
验证套件 SHALL 覆盖三张批准母图的双 profile 来源复现、PBM/header 一致性、Launcher 静态交互、launch p0、return bridge、snapshots、完整 build matrix 与 firmware size gate；TIMER 资产与 hash SHALL 保持原批准值。

#### Scenario: 三组批准资产进入集成
- **WHEN** 新 source、PBM 与 headers 纳入构建
- **THEN** 资产、immutability、handoff、snapshot、host/desktop/firmware-compatible build 与 size gate 全部通过

#### Scenario: 派生资产发生漂移
- **WHEN** PBM 无法由记录母图复现或 header 与 canonical PBM 不一致
- **THEN** 验证指出具体 App/profile/文件并失败，不允许用刷新 snapshot 掩盖错误

### Requirement: Desktop 可近似反射屏而不改变 1-bit 真值
Mac SDL 模拟器 SHALL 默认提供基于 Playdate 1.12.3 参考的暖灰 reflective ink/paper 呈现，并 SHALL 提供显式 pure 黑白模式。palette 转换 SHALL 只发生在 SDL texture 呈现边界，不得改变 MonoFramebuffer、截图/录制、hash、headless 输出或 firmware。

#### Scenario: 默认启动 Desktop
- **WHEN** 用户未指定 palette 启动任一 framebuffer profile
- **THEN** SDL 窗口将黑白像素分别显示为 `#322F28` 与 `#B1AEA7`

#### Scenario: 检查纯 1-bit 对比
- **WHEN** 用户以 `--palette pure` 启动 Desktop
- **THEN** SDL 窗口使用 `#000000` 与 `#FFFFFF`，而两种 palette 下 canonical framebuffer hash 相同

#### Scenario: 传入未知 palette
- **WHEN** 用户传入不支持的 palette 名称
- **THEN** Desktop 拒绝启动并显示包含受支持值的 usage

#### Scenario: 在 Retina Mac 启动 Desktop
- **WHEN** SDL/macOS 提供 2x backing scale
- **THEN** 窗口请求 high-pixel-density surface，日志报告逻辑尺寸、2x 实际像素尺寸与 `2.00x` density，同时 framebuffer 仍按整数最近邻呈现

### Requirement: Cover 目标尺寸必须直接源自母图
Sharp 350×155 与 T-Embed 280×124 Cover SHALL 分别从同一高分辨率 PNG 母图直接 LANCZOS fit 并阈值化，不得从已 1-bit 化的另一个 profile 资产二次缩放。转换参数 SHALL 可复现，运行时仍 SHALL 只 blit 目标尺寸 packed bitmap。

#### Scenario: 检查 Cover 来源
- **WHEN** 对任一内置 Cover 运行母图来源检查
- **THEN** 两个 profile 的 PBM 像素分别与其记录的目标尺寸和阈值直接转换结果完全一致

### Requirement: Timer 状态机和时间边界先由失败测试锁定
自动化 SHALL 在实现前覆盖 Ready/Running/Paused/Expired、1/99 分钟选择与服务边界、非法命令、capability/owner、deadline 前/等于/之后、timestamp regression、large step、generation 和 zero-allocation。

双 profile AppRuntime 测试 SHALL 在 Home/Launcher 前台以后台 `T 99` 验证最大分钟标签及右侧 padding 均位于 System indicator 胶囊内，并 SHALL 断言非 Home 前台不绘制该 indicator。

#### Scenario: Deadline inclusive boundary
- **WHEN** host 分别推进到 deadline 前 1 ms、恰好 deadline 和 deadline 后 1 ms
- **THEN** 只有后两者为 Expired，expiration edge/generation/cue 次数与规格一致

#### Scenario: 最大标签在 Home 上可测
- **WHEN** Home 前台且后台 Timer 显示 `T 99` 或 `P 99`
- **THEN** indicator 胶囊完整包住标签与右侧 padding

### Requirement: Timer 后台与 alert 输入链路有可执行 E2E
Headless/desktop E2E SHALL 从 Launcher 打开 Timer、设定并开始、打开 System Menu或返回 Launcher、跨过 deadline、确认 alert、再次启动，并 SHALL 覆盖 alert 出现在 held button 与 App transition 中的 trace。

#### Scenario: 完整十分钟流程的缩时重放
- **WHEN** deterministic host 以缩时 monotonic trace 执行 Launcher→Timer→Start→Home→Expire→Acknowledge→Timer→Start
- **THEN** Timer 在后台连续、alert 抢占和恢复正确、最近时长保留、current App/lifecycle/input owner/声音序列全部匹配规格

### Requirement: Timer 变更通过完整构建与审计门禁
完成 SHALL 需要相关 unit/integration/snapshot/PCM/headless/desktop 测试、strict warnings、sanitizer、shared-source/platform-header/allocation audit、SDL build/smoke、PlatformIO T-Embed compile、size report 与 `git diff --check`。

#### Scenario: 完成审计
- **WHEN** Timer App 被声明完成
- **THEN** 新鲜命令输出证明所有软件门禁通过，并明确列出只能在实体 T-Embed 执行的旋钮手感、响度和长时间运行验收

### Requirement: Timer migration and presentation are exhaustively verified
自动化验证 SHALL 覆盖产品 Clock 残留审计、双 profile 代表时间几何、Start/Pause/Resume 首帧中点末帧与清理、Alert 多相位/循环/Reduced Motion/Muted/确认抢占、Menu 中间帧全屏 mask 和 fully-open 像素一致性。

#### Scenario: 完整变更门禁
- **WHEN** 该 change 声明实现完成
- **THEN** host suite、strict warnings、sanitizer、SDL smoke/E2E、allocation/size audit、PlatformIO T-Embed 构建和 `git diff --check` 均有通过证据

### Requirement: Typography visual regression must be reviewed as a complete matrix
Completion SHALL produce a deterministic contact sheet containing every built-in App, business Display typography and representative system surface at both display profiles. The review SHALL record whether each frame has accidental text clipping, overlap, illegible thin strokes, inconsistent hierarchy, excessive density, incorrect business-font replacement, or incorrect selected-row inversion; any observed severe defect SHALL be fixed before approval.

#### Scenario: Final typography baseline is audited
- **WHEN** the implementation is proposed as visually complete
- **THEN** an inspectable contact sheet and review record cover the full matrix, with no unresolved severe typography defect

### Requirement: Font flash cost must be explicit
The build SHALL report the compiled bytes for each font descriptor and their total, and SHALL enforce a documented typography flash budget without allocating runtime heap or additional framebuffer storage.

#### Scenario: Font assets are regenerated
- **WHEN** the deterministic font conversion runs
- **THEN** its manifest reports per-role bitmap, glyph metadata and kerning bytes plus the total used by all unique font resources

### Requirement: HomeOnly 角标与 Settings 滚动有自动化回归
自动化 SHALL 锁定 `HomeOnly` Timer/MIC 角标仅在 Home 可见、在代表性非 Home App 不可见，并 SHALL 验证 Settings 在双 profile 下可通过旋钮到达最后一项且选中行完整落在 canvas 内。

#### Scenario: Timer 角标 Home 可见非 Home 不可见
- **WHEN** 后台 Timer Running 且分别渲染 Home 与 Settings（或 Motion）画面
- **THEN** 仅 Home framebuffer 含 Timer indicator 像素，非 Home 不含

#### Scenario: MIC 角标 Home 可见非 Home 不可见
- **WHEN** `microphoneInUse` 为真且分别在 Home 与非 Home App 上跑 frame
- **THEN** 仅 Home 出现 MIC 角标，非 Home 不出现

#### Scenario: Settings 旋到末项仍可见
- **WHEN** 在 320×170 与 400×240 上将 Settings 选中项转到最后一项
- **THEN** 选中行完整位于 canvas 可视区内且可通过 click 触发该行动作（如打开 About）

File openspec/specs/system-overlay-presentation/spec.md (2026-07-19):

# system-overlay-presentation Specification

## Purpose
定义系统 surface 固定层级与容量、按钮序列唯一输入 owner、Menu 暂停 App、与 App transition 的组合语义，以及非交互反馈不得抢占输入的契约。
## Requirements
### Requirement: 系统 surface 使用固定层级与容量
系统 SHALL 以 base App、transient feedback、单个 interactive surface 和 persistent/critical indicator 的固定顺序合成画面，interactive surface 容量 SHALL 为一且不得使用无界 stack 或逐帧 heap 分配。

#### Scenario: System Menu 覆盖 App
- **WHEN** System Menu 在稳定 App 画面上打开
- **THEN** 系统先呈现冻结 App 背景，再呈现 Menu 和更高优先级 indicator，App 不得覆盖系统 surface

#### Scenario: Interactive slot 已占用
- **WHEN** 一个普通 interactive surface 已 active 且另一个普通请求到达
- **THEN** 新请求按稳定 busy/reject policy 处理，现有 surface、App 和 framebuffer 保持有效且诊断计数增加

### Requirement: 完整按钮序列只属于一个输入 owner
系统 SHALL 将一次 button press、long-press、release/click 序列锁存给唯一 App 或 System owner；打开、关闭或替换 surface 不得把同一序列的后续事件交给另一 owner。

#### Scenario: 长按打开菜单后释放
- **WHEN** 用户在 App 中按住按钮至 long-press 打开 System Menu 后释放
- **THEN** release 只完成系统 capture，Menu 不执行当前选项且 App 不收到 release/click

#### Scenario: 菜单关闭期间保持按下
- **WHEN** 一个菜单动作在按钮序列尚未完成时关闭 Menu
- **THEN** 该序列的剩余事件仍由 System 消费，直到新的空闲序列才允许 App 接收按钮输入

#### Scenario: Menu active 时旋转
- **WHEN** interactive System Menu active 且用户产生 turn input
- **THEN** turn 只改变 Menu selection，active App 不接收该 turn

### Requirement: System Menu 暂停 App 而不退出 App
系统 SHALL 在 System Menu active 时停止 active App 的普通 update、input 和 render，使用进入 Menu 前的已提交 framebuffer 作为冻结背景；system services SHALL 继续 begin/commit，关闭 Menu 不得产生 App `onExit` 或 `onEnter`。

#### Scenario: Menu 打开多个 frame
- **WHEN** Menu 保持 active 并经过多个 frame
- **THEN** App update/render 计数和背景像素保持冻结，系统时间、平台事件摄取和系统服务状态继续推进

#### Scenario: Resume 当前 App
- **WHEN** 用户选择 Resume 或关闭 Menu
- **THEN** 同一个 App 在下一稳定 frame 恢复 update/input，期间没有 exit/enter 生命周期事件

### Requirement: Menu 与 App transition 的组合确定
普通 Menu 请求在 App transition 期间 SHALL 捕获触发输入并 defer 到 transition 完成后的首个稳定 frame，且不得冻结半完成 transition 或把输入交给 outgoing/incoming App。

#### Scenario: 转场中长按
- **WHEN** 用户在 App transition 进行时触发 Menu long-press
- **THEN** 系统捕获完整按钮序列，正常完成 transition，然后在目标 App 的稳定画面上打开 Menu

### Requirement: Surface 请求与结果异步且可诊断
系统 surface 的 open、action、close、reject SHALL 在明确 frame 阶段推进，不得从 draw 或 App callback 同步重入 Runtime/SystemService；容量耗尽、busy、invalid action 与 denied owner SHALL 产生稳定拒绝原因和累计诊断。

#### Scenario: Action 在 render 前提交
- **WHEN** Menu action 修改一个系统设置
- **THEN** action 通过 typed command 在 frame commit 阶段执行，Menu render 读取 commit 后 snapshot 且 draw 调用不改变 authoritative state

#### Scenario: 无效 action
- **WHEN** surface 收到当前 model 不支持的 action id
- **THEN** action 被拒绝、现有 surface 保持可用并记录 stable invalid-action diagnostic

### Requirement: 非交互反馈不得抢占 App 输入
Transient feedback 和 passive indicator SHALL 可按各自 scope 覆盖允许的画面但不得成为按钮/turn owner；其容量、过期、去重或丢弃策略 SHALL 有界且可测试。`HomeOnly` passive indicator SHALL 不得覆盖非 Home App 画面。

#### Scenario: Toast 显示期间操作 App
- **WHEN** 无 interactive surface 且 transient feedback 可见
- **THEN** App 继续 update 并接收输入，feedback 按注入时间过期而不阻塞 App

#### Scenario: HomeOnly indicator 不阻挡非 Home 输入
- **WHEN** 非 Home App 前台且仅有 `HomeOnly` passive indicator 处于逻辑 active
- **THEN** 该 App 继续 update 并接收输入，且画面上不出现该 indicator

### Requirement: 被动 indicator 使用显式 presentation scope
系统 SHALL 为被动/persistent indicator 使用封闭的 presentation scope；`HomeOnly` scope SHALL 仅在当前 AppId 等于配置的 Home/Launcher AppId 时合成该 indicator，且 SHALL 不成为按钮/turn owner。

#### Scenario: HomeOnly 在 Launcher 可见
- **WHEN** 一个 `HomeOnly` passive indicator 处于 active 且当前 App 为 Home
- **THEN** 系统在 persistent indicator layer 绘制该 indicator，Home App 继续接收输入

#### Scenario: HomeOnly 在非 Home App 不可见
- **WHEN** 同一 `HomeOnly` indicator 仍 active 但当前 App 不是 Home
- **THEN** 该 indicator 不绘制到 framebuffer，且不改变 App update/input 所有权

#### Scenario: System Menu 覆盖非 Home 时不显示 HomeOnly
- **WHEN** 非 Home App 前台且 System Menu active，同时存在 `HomeOnly` indicator
- **THEN** indicator 保持不绘制；Menu 关闭后若仍停留在该非 Home App，indicator 仍不绘制

### Requirement: USB MIC 隐私角标遵循 HomeOnly
当 `voice.microphoneInUse` 为真时，系统 SHALL 以 `HomeOnly` scope 绘制 MIC 隐私角标；声音 cue 抑制等非呈现策略 SHALL 不因 scope 改变而失效。

#### Scenario: Launcher 上 USB 麦占用显示 MIC
- **WHEN** USB voice streaming 使 `microphoneInUse` 为真且当前为 Home
- **THEN** framebuffer 在约定 MIC 区域出现可读角标

#### Scenario: 非 Home App 上不显示 MIC 角标
- **WHEN** `microphoneInUse` 为真且当前为非 Home App
- **THEN** 该 App 画面上不出现 MIC 角标像素，同时 cue 抑制策略仍可生效

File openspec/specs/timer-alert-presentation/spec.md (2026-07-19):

# Timer Alert Presentation Specification

## Purpose
定义 Timer 完成后的视觉告警、确认路径、后台提示、声音协作以及 Reduced Motion 呈现边界。
## Requirements
### Requirement: 后台 Timer 使用持久系统指示
Running 或 Paused Timer 的 owner App 不在前台时，系统 SHALL 仅在 Home/Launcher 前台于 persistent indicator layer 显示紧凑状态和向上取整的剩余分钟；indicator SHALL 使用 `HomeOnly` scope、不抢占输入，owner App 前台 SHALL 不重复显示，且非 Home 前台 App SHALL 不显示该 indicator。

#### Scenario: Launcher 显示后台 Timer
- **WHEN** Timer 启动 10 分钟 Timer 后返回 Launcher 且 remaining 为 07:18
- **THEN** Launcher 保持可操作并显示可读的 Running indicator `T 08`

#### Scenario: 非 Home App 不显示后台 Timer 角标
- **WHEN** Timer 在后台 Running 或 Paused 且当前 App 为 Settings、Motion 或其他非 Home App
- **THEN** 该 App 画面不绘制 Timer status indicator，Timer 服务继续推进

#### Scenario: 最大分钟数保持在 indicator 内
- **WHEN** Launcher 前台且后台 Running 或 Paused Timer 显示 `T 99` 或 `P 99`
- **THEN** indicator SHALL 按当前 profile 的 Compact 字体测量宽度，完整包住标签和右侧 padding，不得溢出胶囊

### Requirement: 到期使用 critical Timer Alert
Timer 进入 Expired SHALL 打开 system-owned TimerAlert，覆盖任意 App 或 System Menu、冻结 App update/input/render 并保持 system services 推进；确认 SHALL 停止 alert 并恢复原 current AppId，不产生 App exit/enter。

#### Scenario: 其他 App 中到期
- **WHEN** Motion App active 时 Timer 到期
- **THEN** TimerAlert 覆盖 Motion、current AppId 不变、Motion 不再 update，确认后恢复同一 Motion 实例

#### Scenario: System Menu 中到期
- **WHEN** System Menu active 时 Timer 到期
- **THEN** TimerAlert 以 critical 优先级替换 Menu、复用冻结背景且确认后返回被覆盖 App而不是执行隐藏的 Menu action

### Requirement: Alert 捕获完整按钮 sequence
TimerAlert SHALL 在出现时接管后续 input，并 SHALL 在已有按钮 sequence 未 release 时保持 unarmed；触发前的 release/click 不得确认 alert或泄漏到 App。

#### Scenario: 按住按钮时到期
- **WHEN** 用户按住按钮且 Timer 在该 sequence 中到期
- **THEN** alert 出现但第一次 release 只完成 capture，用户下一次完整短按才确认

### Requirement: Alert 与 transition 组合确定
TimerAlert SHALL 在 App transition 期间立即拥有输入并在当前可组合 frame 上显示，不得等待目标 App update 或丢失 expiration generation。

#### Scenario: launch transition 中到期
- **WHEN** Timer 到 Motion 的 transition 中 Timer 到期
- **THEN** alert 在该帧后成为唯一 interactive surface、App transition 不接收确认输入且确认后 runtime 回到确定的 stable App state

### Requirement: Alert 双 profile 可读且无声等价
TimerAlert SHALL 在 320×170 和 400×240 显示完成状态、configured duration 和确认提示，并 SHALL 在 Muted/Reduced Motion 下保持完整意义、bounds 安全和稳定 snapshot。

#### Scenario: 静音到期
- **WHEN** sound volume 为 Muted 且 Timer 到期
- **THEN** 不输出 PCM，但高对比 critical surface 持续到短按确认且所有文字在 framebuffer 内

### Requirement: Timer Alert owns a deterministic visual phase
SystemSurfaceCoordinator SHALL 在 Timer 首次进入 Expired 时将 Alert presentation elapsed 清零，在 Alert 活跃期间推进 elapsed，并在确认或离开 Expired 后清除。该 elapsed SHALL 为只读 presentation 信息且不得写入 Timer snapshot。

#### Scenario: 到期 edge 启动反馈
- **WHEN** Timer 状态从非 Expired 进入 Expired
- **THEN** Alert 获得输入和 App 冻结权，presentation elapsed 从零开始推进

#### Scenario: 确认到期
- **WHEN** 用户确认 Alert 或 Timer 不再 Expired
- **THEN** Alert 退出且 presentation elapsed 被清零

### Requirement: Timer Alert adapts to Motion Profile
`renderTimerAlert` SHALL 接收 visual elapsed 与 MotionProfile，并保留大号 `TIME UP` 作为到期告警主视觉。Normal SHALL 使用约 1.2 秒循环的两侧短导轨，不进行全屏反相；Reduced Motion SHALL 使用与 elapsed 无关的静态双框高强调。

#### Scenario: Normal 周期循环
- **WHEN** 以相差 1.2 秒的 elapsed 绘制同一 Timer snapshot
- **THEN** framebuffer 像素完全相同，且周期内代表相位存在可见差异

#### Scenario: Reduced Motion 静态替代
- **WHEN** 以不同 elapsed 和 Reduced Motion 绘制 Alert
- **THEN** framebuffer 像素完全相同且保持静态双框

### Requirement: Existing Timer Alert ownership and audio remain intact
视觉反馈 SHALL 保持 Alert 冻结 App、拥有输入并使用 TimerComplete 声音；TimerComplete SHALL 为三次具有快速起音与自然衰减的清脆铃击，并在末次形成明亮和弦，Alert SHALL 约每两秒重复一次且不得补播错过的轮次。Muted SHALL 仅抑制声音而不抑制视觉反馈。

#### Scenario: Muted Alert
- **WHEN** Timer 在 Muted 状态到期
- **THEN** Alert 视觉仍然活跃、输入仍被抢占且不会提交可听声音

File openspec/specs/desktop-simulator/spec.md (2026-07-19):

# desktop-simulator Specification

## Purpose
定义 SDL3 桌面模拟器作为共享 Runtime 的平台适配器所需的显示、输入、profile、设备外框和真实可执行 smoke 契约。
## Requirements
### Requirement: Desktop has an independent build target
The project SHALL provide a CMake desktop executable using SDL3 and the same core library compiled by the firmware target.

#### Scenario: Desktop target is built
- **WHEN** CMake configures with SDL3 available and builds the simulator target
- **THEN** the executable links without Arduino or TFT_eSPI

### Requirement: Both display profiles are selectable
The simulator SHALL run at native logical resolutions 320×170 for T-Embed and 400×240 for Sharp without non-uniform content scaling.

#### Scenario: Profile is changed
- **WHEN** the user selects either supported profile
- **THEN** the runtime receives that canvas width and height and Apps lay out against the actual dimensions

### Requirement: Integer presentation is supported
The simulator SHALL display framebuffer pixels using nearest-neighbor 1×, 2×, 3×, or 4× integer scale.

#### Scenario: Scale is selected
- **WHEN** a scale from 1 through 4 is chosen
- **THEN** one logical pixel occupies an exact square of that integer size without interpolation

### Requirement: Desktop input maps to raw device semantics
Mouse wheel and Left/Right keys SHALL emit turn events, while Space and Enter SHALL emit button events that pass through the shared InputReducer and System Overlay input router.

#### Scenario: Keyboard enters an App
- **WHEN** the user rotates selection with an arrow key and taps Enter
- **THEN** the same click semantics used by T-Embed open the selected App

#### Scenario: Desktop long press opens System Menu
- **WHEN** Space or Enter is held past the configured long-press threshold in any stable App
- **THEN** the runtime opens the same system-owned Menu used on T-Embed without immediately changing current App

#### Scenario: Desktop Menu returns home
- **WHEN** scripted desktop input selects Home in System Menu from a non-Home App
- **THEN** the runtime closes Menu and returns to the configured Home App through the shared transition path

### Requirement: Basic runtime metrics are visible
The simulator SHALL expose FPS, frame duration, current App, and recent input events without modifying the App framebuffer used for snapshots unless the overlay is explicitly included.

#### Scenario: Overlay is toggled
- **WHEN** the diagnostics overlay is enabled or disabled
- **THEN** App state and framebuffer truth remain unchanged

### Requirement: Existing Apps complete the desktop loop
Launcher, Timer, Motion, Settings, and Gallery SHALL open, receive input, render, switch, open/close System Menu, and return home through its explicit Home action in the macOS simulator.

#### Scenario: Full navigation smoke path runs
- **WHEN** scripted inputs visit every registered App and use System Menu Home to return to Launcher
- **THEN** no platform-specific alternate UI, App implementation, or direct long-press Home shortcut is invoked

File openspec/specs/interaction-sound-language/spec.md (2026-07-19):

# interaction-sound-language Specification

## Purpose
定义 Cadenza OS 的交互声音语义、克制音色方向、高频输入抑制、会话音量、静音与视觉等价反馈契约。
## Requirements
### Requirement: 语义声音词汇

系统 SHALL 定义 Input 家族的 Navigate、Boundary，Action 家族的 Confirm、Back、ToggleOn、ToggleOff、Reject，Surface 家族的 MenuOpen、MenuClose，Outcome 家族的 Complete、Warning、Failure，以及 System 家族的 Notification、Connect、Disconnect、PowerOn、PowerOff；调用方 SHALL 请求交互语义而不是平台设备操作或资源路径。

#### Scenario: Launcher 或 System Menu 选择改变
- **WHEN** 旋钮输入实际改变 Launcher 或 System Menu 当前选择
- **THEN** 系统触发一次 Navigate，并保留同步的视觉选择反馈

#### Scenario: 打开 App
- **WHEN** 用户确认打开 App
- **THEN** 系统触发 Confirm，且提示与转场开始属于同一次语义动作

#### Scenario: 无效动作
- **WHEN** 用户动作没有改变状态或被边界拒绝
- **THEN** 系统不触发成功提示，并可触发 Boundary 或 Reject

#### Scenario: System Menu 展开与收起
- **WHEN** System Menu 开始展开或收起
- **THEN** 系统分别触发 MenuOpen 或 MenuClose，声音与视觉形变同帧开始，且不得复用 Confirm 或 Back

#### Scenario: Menu Home 返回
- **WHEN** 用户确认 Menu 中的 Home 动作
- **THEN** 系统触发 Back，且 Menu 关闭与到配置 Home App 的 transition 属于同一次语义动作

#### Scenario: 结果与系统事件
- **WHEN** 调用方提交一个有效的 Outcome 或 System cue
- **THEN** 系统按其稳定语义播放对应 palette，且声音不替代视觉状态

### Requirement: 克制的 Cadenza 声音语言
系统 SHALL 使用短促、带 attack/release 的参数化数字音色，以 triangle 为主体、低增益 PolyBLEP square 为数字边缘；Confirm 与 ToggleOn SHALL 具有上行动势，Back 与 ToggleOff SHALL 具有下行动势，Boundary/Reject SHALL 与成功音色可区分。

#### Scenario: 成对提示方向可辨
- **WHEN** 以相同音量依次渲染 Confirm 与 Back
- **THEN** Confirm 的结束频率高于开始频率，Back 的结束频率低于开始频率

#### Scenario: 避免直流点击
- **WHEN** 任一系统 cue 开始和结束
- **THEN** 非零 attack 或 release 使波形不会从峰值瞬时切入或切断

#### Scenario: Playdate 风格密度
- **WHEN** 日常 Navigate 与 Confirm/Back 同时出现在短交互序列
- **THEN** Navigate 保持单一短音，Confirm/Back 仅使用短方向轮廓，不形成持续音乐或奖励音墙

### Requirement: 高频输入抑制

系统 SHALL 为 Navigate 使用最短重触发间隔，并 SHALL 把单个 `InputFrame` 中任意幅度的 turn 聚合为至多一个 Navigate，不得排队补播被抑制、溢出或丢弃的历史 tick。

#### Scenario: 快速连续旋转
- **WHEN** 多次 Navigate 请求发生在冷却窗口内
- **THEN** 只有第一次请求启动 voice，其余请求被丢弃且稍后不会补播

#### Scenario: 冷却后再次旋转
- **WHEN** Navigate 冷却时间已经过去并再次改变选择
- **THEN** 新的 Navigate 被接受

### Requirement: 音量、静音与视觉等价反馈

系统 SHALL 提供 Muted、Low、Medium、High 四档会话音量且默认 Medium；进入 Muted SHALL 立即停止所有 active 与 delayed voice，此后渲染全零。任何重要状态 SHALL 具有声音之外的视觉反馈。

#### Scenario: Settings 切换音量
- **WHEN** 用户在 Settings 的 Sound 行确认
- **THEN** 音量循环到下一档，屏幕文字立即显示新档位，并以新设置决定是否播放反馈

#### Scenario: 立即静音
- **WHEN** 活动声音期间把音量设为 Muted
- **THEN** 活动与延迟 voice 被清除且下一批样本全部为零

#### Scenario: 无声使用
- **WHEN** 系统处于 Muted
- **THEN** 选择、确认、返回和错误仍通过现有或新增视觉状态表达

### Requirement: TimerComplete 是持续但有界的提醒语义
系统 SHALL 提供与 Navigate、Confirm 和 Toggle 可辨的 TimerComplete cue；Expired edge SHALL 立即请求一次并在未确认时以固定有界间隔重复，frame stall SHALL 不补播错过的历史重复，确认 SHALL 停止活动及已调度提醒声音。

#### Scenario: Timer 正常到期
- **WHEN** Running Timer 首次跨过 deadline 且音量非 Muted
- **THEN** 系统请求一次 TimerComplete，之后每个提醒间隔至多一次且不会形成无界 cue queue

#### Scenario: 到期后立即确认
- **WHEN** TimerComplete 尚在播放或含 scheduled event 时用户确认 alert
- **THEN** 所有 alert voice/scheduled event 停止且稍后不再补播

#### Scenario: 静音到期
- **WHEN** volume 为 Muted 且 Timer 到期
- **THEN** PCM 保持数字零、suppressed cue 可诊断且 TimerAlert 提供完整视觉反馈

### Requirement: TimerComplete 合成保持克制和可验证
TimerComplete SHALL 使用固定容量参数化 tone/event palette、非零 attack/release 和确定 event structure；它 SHALL 足以引起注意但不得成为持续音乐、无限 voice 或 caller 自定义 waveform。

#### Scenario: PCM golden 生成
- **WHEN** portable audio core 以固定 sample rate/volume 渲染 TimerComplete
- **THEN** duration、event offsets、peak/RMS、回零和 PCM hash 匹配批准的 golden，且 cue 结束后所有样本精确为零

### Requirement: 分层的 Cadenza 声音语言
系统 SHALL 使用原创参数合成实现经人工拍板的 Semantic Hierarchy palette；Navigate、ToggleOn 与 ToggleOff SHALL 分别以 Select、Turn On、Turn Off 的时长、低调程度和动作轮廓作为本地校准参考，但 SHALL NOT 嵌入或分发参考采样。Input SHALL 最轻，Action SHALL 可辨动作类型，Surface SHALL 使用低于 Confirm/Back 的单起音形变声，Outcome 与 System MAY 使用更完整音身，但不得形成持续背景音乐。

#### Scenario: Navigate 近似校准
- **WHEN** headless 渲染 Navigate
- **THEN** 输出为极短、低注意力的合成反馈，时长、包络峰和主频范围处于已记录校准边界且结束后精确静音

#### Scenario: Toggle 成对可辨
- **WHEN** 以相同音量依次渲染 ToggleOn 与 ToggleOff
- **THEN** 两者在时长和材质上同族、动作轮廓可辨，且不被误认为 Confirm 或 Back

#### Scenario: 进入与退出保持拍板原型
- **WHEN** headless 分别渲染 App 进入使用的 Confirm 与长按返回使用的 Back
- **THEN** Confirm 保持两段上行调音敲击，Back 保持不对称的两段下行且第二段更闷更短；两者的事件 offset、有效时长、包络峰和主频范围处于已记录的 `09-semantic-hierarchy-full` 校准边界，并与旧版连续 Triangle/Square 滑音可区分

#### Scenario: Menu Surface 成对可辨
- **WHEN** headless 分别渲染 MenuOpen 与 MenuClose
- **THEN** 两者均为无延迟第二敲击的单动作声，MenuOpen 在约 160 ms 内从低音区明显上扬，MenuClose 在约 140 ms 内明显下潜，且上下文试听不被误认为 Confirm/Back

#### Scenario: 家族层级
- **WHEN** 依次渲染 Input、Action、Surface、Outcome 与 System cue
- **THEN** 每个 cue 使用唯一名称和确定性合成定义，且重要状态仍具有非声音反馈

### Requirement: 参考音频不进入产品
系统 SHALL 只记录参考音频的非版权听感特征与本地校准结论，SHALL NOT 把用户提供或任天堂参考 WAV、其 PCM、波形片段或可逆变形加入仓库、生成代码或运行时资产。

#### Scenario: 重新生成 palette
- **WHEN** 开发者构建或导出全部 cue
- **THEN** 结果仅由仓库内参数与合成原语确定，不读取本地参考文件

#### Scenario: 审计仓库资产
- **WHEN** 执行 shared-source 与音频资产审计
- **THEN** 不存在 Select、Turn On、Turn Off 或任天堂参考采样的嵌入副本

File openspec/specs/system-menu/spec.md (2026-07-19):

# system-menu Specification

## Purpose
定义系统拥有的 System Menu：长按开闭、最小系统动作、有界 UI primitives、语义反馈，以及普通 App 不得改写菜单结构的边界。

## Requirements
### Requirement: 长按从任意 App 打开系统菜单
系统 SHALL 将共享 long-press gesture 解释为打开或关闭 System Menu，不要求 App 实现硬件处理；System Menu SHALL 由系统拥有且不进入 App catalog。

#### Scenario: 非 Home App 打开菜单
- **WHEN** active App 稳定且用户触发 long-press
- **THEN** System Menu 覆盖该 App，catalog/current AppId 不变且不开始 Home transition

#### Scenario: Home 打开菜单
- **WHEN** Home App active 且用户触发 long-press
- **THEN** System Menu 打开但省略冗余的 Home action，导航顺序只包含当前可用动作

### Requirement: System Menu 提供最小系统动作
首版 System Menu SHALL 只提供 Resume、Sound、Motion 以及仅在非 Home App 中出现的 Home action；动作和状态 SHALL 来自 stable enum/typed snapshot/command，不得持有平台 driver 或任意 callback。Connectivity、Device 等只读信息 SHALL 不为了填充空间而进入此高频菜单。

#### Scenario: 返回 Launcher
- **WHEN** 用户在非 Home App 的 Menu 中确认 Home
- **THEN** Menu 关闭并以 Back 语义启动到配置 Home AppId 的正常 transition

#### Scenario: 修改声音设置
- **WHEN** 用户确认 Sound 行
- **THEN** 系统提交现有 typed volume command并在同帧 render显示 commit 后值，Muted 时视觉反馈仍完整

#### Scenario: 不展示无动作的状态行
- **WHEN** System Menu 渲染
- **THEN** Connectivity、Device 等无直接动作的状态不占用菜单行或页脚，复杂状态留给独立系统页面

### Requirement: 系统菜单使用有限且一致的 UI primitives
System Menu SHALL 使用 stateless Panel、Header、MenuRow、Selection、Value 与 StatusIndicator primitives；primitives SHALL 只依赖 canvas、bounds 和显式 visual state，不得拥有 input、service、App、callback 或动态树。

#### Scenario: 双 profile 渲染
- **WHEN** 同一个 Menu model 分别在 320×170 和 400×240 profile 渲染
- **THEN** 两者以有界时间从右侧滑入不透明 Menu panel，mask 同步渐强，冻结 App 的左侧上下文经 mask 后仍可见，并保持相同项目顺序、selection 和动作语义，所有文字与边框在 framebuffer bounds 内且可读
- **AND** Header 与可容纳的短 action label 优先使用接近行高的大字号，长 label 由 bounded-text 确定性降级，value 保持次级字号

#### Scenario: 选择与控件状态
- **WHEN** 行被选择或未选择，Sound 为任意音量，或 Motion 开关变化
- **THEN** 每种状态都有不依赖声音的稳定视觉表达并通过 snapshot/golden 锁定

### Requirement: 菜单导航与提示音使用语义反馈
Menu selection 变化 SHALL 产生至多一次 Navigate；打开、关闭、返回 Home、设置修改和拒绝 SHALL 使用既有 Confirm、Back、Toggle/Boundary/Reject 语义，不得请求资源路径或自定义 waveform。

#### Scenario: 快速旋转菜单
- **WHEN** 单个 frame 的任意 turn delta 改变 Menu selection
- **THEN** selection 按有界规则移动且至多提交一次 Navigate，不补播被抑制的历史 tick

#### Scenario: Home 不出现冗余动作
- **WHEN** current App 已是 Home
- **THEN** Home action 不渲染且旋钮导航跳过该 action，不产生隐藏 selection 或 transition

### Requirement: 普通 App 不控制系统菜单结构
第一阶段普通 App SHALL 不能枚举、删除、重排系统条目或注入任意 View/同步 callback；任何未来 App contribution SHALL 通过独立规格定义有界 descriptor 与异步 result。

#### Scenario: App context 被审计
- **WHEN** core/App public headers 与 bundled App source 被检查
- **THEN** 不存在可修改 System Menu system items 或传入 renderer/callback 指针的 App API

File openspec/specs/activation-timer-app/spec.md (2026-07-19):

# Activation Timer App Specification

## Purpose
定义 Activation Timer App 的时长调整、启动暂停、完成确认、后台运行与系统服务交互契约。

## Requirements

### Requirement: Activation Timer 提供低摩擦分钟设定
Timer App SHALL 在没有活动倒计时时进入 Ready，默认配置 10 分钟，并 SHALL 允许旋钮以整分钟在 1–99 分钟内循环调整；单帧任意 turn delta SHALL 只产生一次语义反馈。

#### Scenario: 首次进入 Timer
- **WHEN** 系统尚未启动或恢复任何 Timer 且用户打开 Timer App
- **THEN** App 显示 10:00、Ready 状态、可见时间体和按下开始提示

#### Scenario: 设定穿越边界
- **WHEN** Ready 为 99 分钟继续增加，或为 01 分钟继续减少
- **THEN** duration 分别循环到 01:00 或 99:00，视觉保持两位分钟并产生一次 Navigate

### Requirement: 单按钮控制开始暂停和继续
Timer App SHALL 在 Ready 短按开始，在 Running 短按暂停，在 Paused 短按继续；长按 SHALL 始终保留给 System Menu。

#### Scenario: 开始十分钟行动
- **WHEN** Ready 配置为 10 分钟且用户短按
- **THEN** Timer 进入 Running、remaining 从 10:00 开始按系统单调时间减少并产生成功视觉/声音反馈

#### Scenario: 暂停后继续
- **WHEN** Running 短按后经过任意系统时间再短按
- **THEN** Paused 期间 remaining 不变且 Resume 从同一 remaining 建立新 deadline

### Requirement: 暂停状态允许重设剩余分钟
Paused 状态 SHALL 允许旋钮按整分钟在 1–99 分钟间循环调整 remaining，每次调整 SHALL 将秒数归零，并 SHALL 以新 remaining 继续；Running 旋钮 SHALL 不修改 deadline。

#### Scenario: 暂停时延长时间
- **WHEN** Paused remaining 为 07:18 且旋钮增加 2 分钟
- **THEN** remaining 变为 09:00、configured duration 同步为新的可复用时长且一次反馈表达状态改变

#### Scenario: 暂停调整穿越边界
- **WHEN** Paused remaining 为 99:00 且旋钮增加 1 分钟
- **THEN** remaining 和 configured duration 均变为 01:00，并产生一次 Navigate

#### Scenario: 最后一分钟暂停后调整
- **WHEN** Paused remaining 为 00:18 且旋钮增加 1 分钟
- **THEN** remaining 和 configured duration 均变为 01:00，而不是 02:00 或 01:18

#### Scenario: 运行时误转旋钮
- **WHEN** Running 收到任意 turn delta
- **THEN** deadline 和 remaining 真相不改变并至多产生一次 Boundary

### Requirement: 到期确认保留最近时长
Expired SHALL 由系统 alert 接管输入；用户确认后 Timer SHALL 回到 Ready 并保留最近 configured duration，不自动开始下一轮。

#### Scenario: 完成后再来一次
- **WHEN** 10 分钟 Timer 到期且用户短按确认
- **THEN** alert 停止、Timer App 下次显示 Ready 10:00，用户再短按才开始新一轮

### Requirement: 剩余时间同时提供精确和感知表达
Timer App SHALL 同时渲染 `MM:SS` 和随剩余比例单调减少的 1-bit 时间体，并 SHALL 在 Ready、Running、Paused 和 Reduced Motion 下保持无声音也可识别的状态。

#### Scenario: 双 profile 运行画面
- **WHEN** 同一 10 分钟 Timer 在 320×170 和 400×240 分别渲染 10:00、05:00 和 00:01
- **THEN** 数字、状态、操作提示和时间体均在 bounds 内可读，时间体填充比例依次单调减少且不依赖颜色

### Requirement: App 生命周期不拥有 Timer 真相
Timer App 的 `onEnter`、`onExit`、update 和 render SHALL 不重置或累加 authoritative Timer；离开并返回 SHALL 读取同一个 system snapshot。

#### Scenario: 返回 Launcher 后重开
- **WHEN** Running Timer 离开 Timer App、在 Launcher 经过两分钟后重新打开
- **THEN** current Timer identity/state 保持且 remaining 减少约两分钟，不从初始时长重启

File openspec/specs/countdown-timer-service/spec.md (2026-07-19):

# Countdown Timer Service Specification

## Purpose
定义独立于前台 App 生命周期的倒计时服务状态机、单调时钟、完成事件、持久快照、后台运行、恢复语义与确定性验证边界。

## Requirements

### Requirement: 系统拥有单个封闭状态 Timer
SystemServiceHost SHALL 拥有至多一个 `Ready`、`Running`、`Paused` 或 `Expired` Timer，并 SHALL 在 frozen `SystemSnapshot` 中暴露 configured duration、remaining、owner 和 expiration generation，不暴露 callback、driver 或可变 service。

#### Scenario: 初始快照
- **WHEN** SystemServiceHost 初始化
- **THEN** Timer 为 Ready、configured/remaining 为 10 分钟、owner invalid 且 generation 为 0

### Requirement: Running 使用单调 deadline
TimerService SHALL 以注入的 nondecreasing monotonic time 建立 deadline 并从 `deadline - now` 推导 remaining；presentation/App simulation delta SHALL 不成为 Timer 的权威时间。

#### Scenario: App simulation 冻结但时间继续
- **WHEN** presentation delta 连续为 0 而注入 monotonic now 前进 120 秒
- **THEN** Running remaining 减少 120 秒且 App/animation state仍可保持冻结

#### Scenario: 时间源倒退
- **WHEN** 注入 now 小于上一帧 now
- **THEN** Timer remaining 不增加、deadline 不后移并记录稳定 clock-regression 诊断

### Requirement: Timer 命令类型化且受 capability 与 owner 约束
App SHALL 只能以 `TimerControl` capability 提交 Start、Pause、Resume 和 SetRemaining；host SHALL 在提交和 commit 时验证 caller、1–99 分钟范围及合法状态，并 SHALL 允许 system owner Acknowledge Expired。

#### Scenario: 无权限 App 启动 Timer
- **WHEN** 不含 TimerControl 的 App 提交 Start
- **THEN** 命令以 CapabilityDenied 拒绝且 Timer snapshot 不变

#### Scenario: 非法状态继续
- **WHEN** Ready Timer 收到 Resume 或 Running Timer 收到 SetRemaining
- **THEN** 命令以稳定 InvalidState/InvalidCommand 原因拒绝且 deadline 不变

### Requirement: Timer 跨前台生命周期继续
Running Timer SHALL 在 owner App exit、Launcher active 或 System Menu suspend-with-snapshot 期间继续，且 foreground resource cleanup SHALL 不取消 session Timer。

#### Scenario: System Menu 覆盖到期
- **WHEN** Running Timer 剩余 5 秒且 System Menu 保持打开 10 秒
- **THEN** Timer 在 deadline crossing 时进入 Expired，不能等 Menu 关闭后才计算到期

### Requirement: 到期边沿精确一次且无 backlog
TimerService SHALL 在 `now >= deadline` 的首帧只产生一次 Running→Expired edge并递增 generation；frame stall 跨过 deadline 或多个提醒间隔 SHALL 不补播历史到期/提醒事件。

#### Scenario: 大步跨越 deadline
- **WHEN** remaining 为 1 秒且下一个 monotonic now 前进 30 秒
- **THEN** Timer 只进入一次 Expired、generation 只增加 1 且该帧至多请求一次 TimerComplete

### Requirement: Timer 服务确定且无逐帧分配
TimerService、command、snapshot 和 diagnostics SHALL 使用固定值类型与有界状态，host/headless/desktop/firmware 同一源码 SHALL 对相同 time/command trace 产生相同状态。

#### Scenario: 重放状态 trace
- **WHEN** 两个 host 重放相同 Start、advance、Pause、SetRemaining、Resume、Acknowledge trace
- **THEN** 每帧 TimerSnapshot、generation、rejection 和 cue request 序列一致且 allocation probe 为零

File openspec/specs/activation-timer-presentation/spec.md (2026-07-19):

# Activation Timer Presentation Specification

## Purpose
定义 Activation Timer 在双 framebuffer profile 下的数字层级、状态动效、背景纹理与可读性呈现契约。

## Requirements

### Requirement: Timer is the only current product identity
系统 SHALL 在产品文案、C++ API、host 成员、注册、测试场景、诊断标签、文档与资产中使用 Timer；`TimerApp` 与 `kTimerAppId` SHALL 取代旧 Clock 符号，且 `kTimerAppId` SHALL 保持数值 `0x0101`。系统 MUST NOT 提供旧符号兼容 alias。

#### Scenario: 全仓迁移完成
- **WHEN** 执行源码、测试、文档和资产名称审计并构建所有目标
- **THEN** 现行产品实现只暴露 Timer 命名，且 catalog ID 仍为 `0x0101`

### Requirement: Timer uses native industrial numeral atlases
Timer SHALL 使用仅含 `0–9` 与冒号的双 profile 原生 1-bit bitmap atlas 组合 `MM:SS`，MUST NOT 对通用字体进行运行时缩放。数字 SHALL 等宽，冒号 SHALL 由两个光学校正的倒角方点构成。

#### Scenario: 双 profile 绘制代表时间
- **WHEN** 在 320×170 与 400×240 profile 绘制 `10:00`、`05:00` 和 `00:01`
- **THEN** 时间体为 228×84 与 308×120，数字 advance 等宽、冒号光学居中且 geometry diagnostics 为零

### Requirement: Timer state changes have local presentation feedback
TimerApp SHALL 为 Starting、Pausing、Resuming 持有不改变服务 snapshot 的 presentation elapsed。Normal Motion SHALL 为 Start/Resume 使用约 240/180 ms 的左至右局部扫光，为 Pause 使用约 180 ms 的右至左逆向扫光；Reduced Motion SHALL 使用约 100 ms 的无位移高对比边框。

#### Scenario: 启动暂停恢复
- **WHEN** 相应 Timer 命令成功提交
- **THEN** 首帧、中点和末帧呈现对应局部反馈，且既有 ToggleOn/ToggleOff 声音保持不变

#### Scenario: App handoff 清理反馈
- **WHEN** Timer App 在反馈结束前离开并重新进入
- **THEN** 未完成反馈被清除且不会在返回后继续播放

### Requirement: Timer presentation remains allocation free
Timer 绘制和状态反馈 SHALL 使用固定资产与栈/对象内状态，不得在 steady-state update/render 中产生运行时分配。

#### Scenario: 反馈循环接受 allocation 审计
- **WHEN** 对 Start、Pause、Resume 及其关键帧执行 allocation harness
- **THEN** 运行时分配计数保持为零

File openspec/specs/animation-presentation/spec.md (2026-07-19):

# animation-presentation Specification

## Purpose
定义建立在动画核心之上的转场、选择反馈、相机效果、粒子和 Gallery 展示契约，并保证 reduced-motion、可逆预览与双分辨率行为一致。
## Requirements
### Requirement: Runtime transitions are selectable strategies

AppRuntime SHALL accept a direct or staged transition strategy and duration without requiring Apps to know transition details. The default Launcher/App route SHALL select directional staged Cover handoffs, while venetian blinds and the existing direct transition set SHALL remain selectable rather than hard-coded runtime drawing.

#### Scenario: Transition is selected
- **WHEN** an App is opened with a specified transition
- **THEN** that strategy composes captured outgoing and incoming frames while lifecycle ordering remains correct

#### Scenario: Direct transition is selected
- **WHEN** an App is opened with a specified direct transition
- **THEN** that strategy composes captured outgoing and incoming frames while lifecycle ordering remains correct

#### Scenario: Default Launcher handoff is selected
- **WHEN** the default Runtime opens an App from Launcher or returns from an App to Launcher
- **THEN** it selects the corresponding staged Cover handoff and preserves the same lifecycle ordering contract

### Requirement: Core transition set is complete
The presentation layer SHALL implement Dip/Fade, horizontal wipe, diagonal wipe, iris, venetian blinds, and checker/dither dissolve for 1-bit source and destination frames.

#### Scenario: Transition endpoints are rendered
- **WHEN** every transition renders progress 0 and progress 1
- **THEN** output exactly equals source at 0 and destination at 1

### Requirement: Selection feedback has overshoot and pulse
The UI SHALL provide reusable selection feedback with a short overshoot or pulse envelope that is interruptible and respects reduced-motion settings.

#### Scenario: Selection changes rapidly
- **WHEN** repeated turn input changes selection before feedback completes
- **THEN** feedback retargets continuously without a visible state jump or unbounded amplitude

### Requirement: Camera punch and shake are deterministic
The presentation layer SHALL provide a short camera punch and bounded camera shake using explicit duration, amplitude, decay, and seed.

#### Scenario: Shake is replayed
- **WHEN** two fresh effects use the same seed and fixed time sequence
- **THEN** their camera offsets match and return exactly to neutral at completion

### Requirement: Particles use a fixed pool
The presentation layer SHALL provide fixed-capacity particles with position, velocity, lifetime, optional acceleration, visual primitive/sprite, deterministic seed, and an explicit full-pool policy.

#### Scenario: Particle pool is full
- **WHEN** an emitter requests more particles than capacity
- **THEN** the configured reject-or-replace policy is applied without allocation or storage corruption

### Requirement: Frame animation and state machines are available
Sprite animation SHALL support atlas frame sequences in once, loop, and ping-pong modes, and a fixed-capacity state machine SHALL switch named animation states through explicit triggers.

#### Scenario: State transition changes animation
- **WHEN** a valid trigger moves from idle to active
- **THEN** the configured active frame sequence begins according to its reset policy

### Requirement: Knob can directly control progress
Presentation demos SHALL allow turn input to scrub a Tween, transition, frame animation, or Timeline progress without requiring time playback.

#### Scenario: Knob reverses progress
- **WHEN** turn delta changes controlled progress from a larger to a smaller value
- **THEN** the visual state moves backward deterministically without completion side effects

### Requirement: Animation Gallery centralizes visual QA
The runtime SHALL register an Animation Gallery App containing discoverable pages for easing, Tween composition, Spring, transitions, selection feedback, camera effects, particles, sprite/state animation, and dither/pattern effects.

#### Scenario: Gallery is navigated
- **WHEN** the user rotates through Gallery pages and presses to change demo mode
- **THEN** every required effect can be previewed and its relevant progress or parameters are visible

### Requirement: Motion comfort is configurable
Effects SHALL consume a normal or reduced-motion profile that reduces shake, elastic overshoot, camera displacement, and particle density without disabling core navigation feedback.

#### Scenario: Reduced motion is enabled
- **WHEN** Settings selects quiet/reduced motion
- **THEN** Gallery and runtime effects use reduced amplitudes and density while transitions remain functional

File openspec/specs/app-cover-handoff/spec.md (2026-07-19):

# App Cover Handoff Specification

## Purpose
定义 Launcher Cover 与 App 首帧之间连续、确定、无分配的交接过程及返回 Launcher 时的像素连续性契约。

## Requirements

### Requirement: App switches preserve static Cover identity
The default system transition between Launcher and an App SHALL preserve the App's static Cover identity without passing interaction, time, launch, or lifecycle state to the Cover renderer. A launch sequence SHALL be a separate renderer and returning to Launcher SHALL use a static Cover bridge.

#### Scenario: Launcher opens an App with a Cover
- **WHEN** Launcher opens a registered App that renders a Cover
- **THEN** the transition preserves the selected Cover identity into the App's independent launch sequence without changing the approved Cover pixels

#### Scenario: App has no Cover
- **WHEN** Launcher opens or returns from a registered App whose Cover renderer declines to draw
- **THEN** the bridge uses a deterministic bounded fallback and completes without invalid or clipped geometry diagnostics

### Requirement: Handoff is staged around the lifecycle midpoint
A staged handoff SHALL compose `source -> launch-or-bridge frame -> destination`, perform exactly one outgoing `onExit` followed by incoming `onEnter` at the midpoint, and SHALL NOT deliver normal App update input until the destination is stable.

#### Scenario: Transition crosses its midpoint
- **WHEN** a staged transition advances from immediately before to at or after progress 0.5
- **THEN** the last pre-midpoint frame and first post-midpoint frame meet at the same bridge state while lifecycle callbacks occur once in exit-before-enter order

#### Scenario: Input arrives during handoff
- **WHEN** turn, click, or held input is present before the transition completes
- **THEN** neither outgoing nor incoming App receives a normal update from that input

### Requirement: Handoff reuses two transition buffers
The Runtime SHALL create and preserve the final launch or bridge frame using the existing outgoing and incoming transition framebuffers and SHALL NOT add a third full-screen transition framebuffer or perform runtime heap allocation.

#### Scenario: Midpoint buffer ownership changes
- **WHEN** a staged transition reaches its lifecycle midpoint
- **THEN** the bridge becomes the outgoing phase source before the destination first frame replaces the incoming buffer

### Requirement: Enter and return have directional timing
Normal motion SHALL use a longer Launcher-to-App handoff that presents the App launch sequence and a shorter App-to-Launcher handoff that resolves directly into the App Cover and Launcher chrome. Reduced Motion SHALL preserve the identity ordering while reducing nonessential waiting and displacement.

#### Scenario: Launcher opens an App
- **WHEN** the default Normal-motion transition starts from Home and targets a visible App
- **THEN** Launcher chrome recedes into the App's independent launch sequence and its stable final frame resolves through ordered dither into the App first frame

#### Scenario: App returns to Launcher
- **WHEN** the default transition targets Home from an App
- **THEN** the App frame resolves to that App's Cover bridge and Launcher chrome returns without replaying the launch loading interval

#### Scenario: Return preserves shared Cover geometry and frame cadence
- **WHEN** each built-in App returns at fixed 30 FPS on either framebuffer profile
- **THEN** the transition starts at the exact outgoing App frame, keeps the selected Cover pixels fixed at the Launcher's content rectangle from the lifecycle midpoint onward, ends at a stable Launcher frame, and changes no more than 16% of framebuffer pixels between adjacent samples

#### Scenario: Reduced Motion is active
- **WHEN** either directional handoff begins under Reduced Motion
- **THEN** source, bridge, and destination remain visually ordered while pure wait time is no greater than under Normal motion

### Requirement: Existing direct transitions remain compatible
Transitions that do not declare staged bridge behavior SHALL retain the existing direct outgoing/incoming capture, endpoint, lifecycle, and custom-duration semantics.

#### Scenario: Caller injects a direct transition
- **WHEN** AppRuntime is constructed with or configured to use Cut, Venetian Blinds, Dip, Wipe, Iris, Dissolve, or another direct strategy
- **THEN** the Runtime does not replace its incoming source with a Cover bridge and the strategy receives the same direct frame model as before this change

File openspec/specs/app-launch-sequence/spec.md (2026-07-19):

# App Launch Sequence Specification

## Purpose
定义各 App 在系统交接之后可独立实现的启动序列边界、上下文输入、端点一致性、生命周期隔离、双 profile 确定性与降级行为。

## Requirements

### Requirement: Apps can provide an independent launch sequence
An App SHALL be able to provide an optional const full-screen launch-frame renderer driven by normalized progress and a read-only AppRenderContext. The Runtime MAY call it before `onEnter`; rendering a launch frame MUST NOT mutate App state, Cover pixels, lifecycle, catalog, or system services.

#### Scenario: Runtime samples a launch sequence
- **WHEN** a registered App is launched from Home and implements the launch renderer
- **THEN** the Runtime can render any progress in `[0, 1]` deterministically before `onEnter` without delivering an App update

#### Scenario: Progress is sampled repeatedly
- **WHEN** the same App, profile, and normalized progress are rendered more than once
- **THEN** the resulting framebuffer bytes are identical and no allocation or diagnostic failure occurs

### Requirement: Built-in Apps have distinct launch identities
Timer, Motion, Settings, and Animation Gallery SHALL each provide a visually distinct code-native launch sequence whose first phase continues its static Cover identity and whose final frame can hand off to the App first frame.

#### Scenario: Built-in launch frames are compared
- **WHEN** representative early, middle, and final launch progress values are captured for all built-in Apps
- **THEN** every App has distinct framebuffer hashes at one or more representative phases and all frames remain valid at both display profiles

### Requirement: Missing launch sequences have a bounded fallback
If an App does not implement launch-frame rendering, Runtime SHALL use a deterministic static Cover bridge or bounded name fallback and SHALL still preserve lifecycle ordering and transition completion.

#### Scenario: Third-party App has no launch renderer
- **WHEN** Launcher opens a registered App whose launch renderer returns false
- **THEN** Runtime uses the fallback handoff without calling the renderer again as ordinary App content or exposing uninitialized transition pixels

### Requirement: Launch-frame progress is scrubbable for verification
Launch renderers SHALL produce valid frames for forward, repeated, and decreasing progress values without completion callbacks or irreversible side effects.

#### Scenario: Verification seeks backward
- **WHEN** a test renders progress 0.8 followed by 0.3 and then 0.8 again
- **THEN** both 0.8 frames match exactly and the 0.3 frame represents the earlier phase

### Requirement: Launch sequence endpoints are visually continuous
Each built-in launch sequence SHALL begin with the exact centered static Cover bridge and SHALL end with the exact first App framebuffer produced for the same App state and SystemSnapshot after its normal `onEnter` semantics. Intermediate frames SHALL evolve between those identities without a hard replacement by an unrelated full-screen composition.

#### Scenario: Launch endpoints are compared
- **WHEN** progress 0 and progress 1 are captured for a built-in App at either display profile
- **THEN** progress 0 matches the centered Cover bridge byte-for-byte and progress 1 matches the App first frame byte-for-byte

#### Scenario: Launch is sampled at 30 FPS
- **WHEN** the full handoff is rendered at fixed 30 FPS
- **THEN** adjacent frames change only a bounded portion of framebuffer pixels and no single frame performs an unmasked full-composition jump

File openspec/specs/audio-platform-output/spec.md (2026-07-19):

# audio-platform-output Specification

## Purpose
定义 portable 音频核心在 headless、SDL3 与原版 T-Embed I²S 上的统一输出格式、线程所有权、失败降级、生命周期和可验证边界。
## Requirements
### Requirement: 同一 core 跨平台消费

SDL、T-Embed 与 headless SHALL 消费 portable core 的同一命令与 44,100 Hz、16-bit mono 合成渲染契约；平台层不得重新定义 cue 音色或语义。

#### Scenario: Headless 观测
- **WHEN** 测试触发任一 cue 并同步消费命令、拉取固定样本数
- **THEN** 测试可检查 PCM、峰值、包络、样本数、结束静音与确定性 hash 而无需设备

#### Scenario: 无输出设备
- **WHEN** 平台音频初始化失败或 headless 不创建设备
- **THEN** 图形、输入和 Runtime 继续运行，错误被报告而不是崩溃

### Requirement: SDL AudioStream callback 输出
桌面应用 SHALL 请求 44,100 Hz、S16、mono AudioStream，由 callback 按设备请求持续消费命令和生成 PCM；音频 SHALL 按真实设备时间而非 simulation speed 运行，并 SHALL 安全停止、销毁。

#### Scenario: 桌面交互
- **WHEN** AudioStream 已启动且主线程提交 cue
- **THEN** callback 在后台生成 PCM，图形循环不被同步播放阻塞

#### Scenario: 调试暂停
- **WHEN** simulation 被暂停且已有 cue 尚未结束
- **THEN** 已有 cue 按真实音频时间自然结束，暂停期间不因 App update 产生新 cue

#### Scenario: 生命周期关闭
- **WHEN** 桌面应用退出
- **THEN** stream 在 Runtime/host 析构前停止并销毁，callback 不访问失效状态

### Requirement: 原版 T-Embed I²S task 输出
固件 SHALL 使用独立 audio task 和 I²S DMA，通过 BCLK GPIO 7、WCLK GPIO 5、DOUT GPIO 6 输出 44,100 Hz、16-bit right-left frames；adapter SHALL 把每个 core mono sample 复制到左右 slot。

#### Scenario: 固件初始化
- **WHEN** 当前 Arduino-ESP32 2.0.17 legacy I²S driver 可用
- **THEN** driver 以指定格式和引脚启动，固定 task 持续供给 DMA，产品默认增益不采用厂商示例最大值

#### Scenario: Mono 转 I²S frame
- **WHEN** core 产生一块 mono PCM
- **THEN** adapter 输出等量左右相同的 stereo frame，顺序与 MAX98357A/driver 配置一致

#### Scenario: I²S 失败
- **WHEN** driver 安装、设定引脚或写入失败
- **THEN** audio adapter 禁用并报告诊断，主 Runtime 继续工作

### Requirement: 验证与真机声明

项目 SHALL 自动验证 portable 合成原语、延迟调度、命令队列、语义路由、静音、参考资产未嵌入、SDL dummy callback、无设备降级、firmware 编译和 I²S frame；项目 SHALL 明确区分自动化特征证明、用户上下文试听与实体 T-Embed 听感验证。

#### Scenario: 自动化门禁
- **WHEN** 执行音频特征、host、desktop、shared-source 与 firmware 检查
- **THEN** PCM golden、延迟/包络、新音频测试和既有回归通过，桌面与固件目标成功构建

#### Scenario: 无实体设备
- **WHEN** 当前环境不能采集 T-Embed 扬声器输出
- **THEN** 文档不得声称最终真机听感通过，并列出可重复的真机步骤与预期

#### Scenario: 参考资产隔离
- **WHEN** 在没有本地参考 WAV 的干净 checkout 构建全部目标
- **THEN** palette 仍可确定性构建和导出，且产物不包含参考 PCM

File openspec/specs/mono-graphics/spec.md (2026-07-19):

# mono-graphics Specification

## Purpose
定义跨 T-Embed 与 Sharp profile 共用的 1-bit framebuffer、MonoCanvas 图元、字体/位图光栅、裁剪与 presenter 像素契约。
## Requirements
### Requirement: Framebuffer format is canonical
The core SHALL own a row-major, MSB-first packed 1-bit framebuffer with `1` representing black, stride `(width + 7) / 8`, and supported dimensions 320×170 and 400×240.

#### Scenario: Buffer size is calculated
- **WHEN** a 400×240 framebuffer is initialized
- **THEN** its stride is 50 bytes and its active storage is exactly 12,000 bytes

#### Scenario: Pixel bit is addressed
- **WHEN** a pixel at a known coordinate is set and cleared
- **THEN** only the specified MSB-first bit changes

### Requirement: Software primitives are deterministic
The core canvas SHALL draw clear, pixel, line, rectangle, filled rectangle, circle, filled circle, and text using integer software rasterization independent of display backends.

#### Scenario: Primitive golden cases render
- **WHEN** boundary, degenerate, and representative primitives are rendered
- **THEN** their exact framebuffer bytes match approved golden results

### Requirement: Drawing is clipped and diagnosable
Every draw operation SHALL respect a half-open clip rectangle and framebuffer bounds; invalid or fully clipped primitives SHALL not write outside storage and SHALL be observable through an optional diagnostic sink.

#### Scenario: Out-of-bounds geometry is drawn
- **WHEN** a primitive crosses every canvas edge
- **THEN** in-bounds pixels are correct, guard bytes are unchanged, and a diagnostic count is updated

### Requirement: Bitmap and sprite drawing are available
The canvas SHALL draw packed 1-bit bitmaps and sprite source regions with copy, set-black, and XOR composition.

#### Scenario: Transparent-style sprite is composed
- **WHEN** a sprite region is drawn with set-black composition
- **THEN** source black pixels are applied while source white pixels leave the destination unchanged

### Requirement: Sprite atlases have fixed metadata
A sprite atlas SHALL reference one bitmap plus a fixed-capacity list of named or indexed frame rectangles and SHALL report lookup or capacity failure explicitly.

#### Scenario: Atlas capacity is exhausted
- **WHEN** a frame is added beyond atlas capacity
- **THEN** the operation fails without changing existing frame metadata

### Requirement: Basic transforms are supported
Sprite drawing SHALL support integer translation and horizontal or vertical flip while respecting source and destination clipping.

#### Scenario: Flipped clipped sprite is drawn
- **WHEN** a horizontally flipped sprite is partially outside the clip rectangle
- **THEN** visible pixels preserve the correct reversed source mapping

### Requirement: Pixel fonts have a legal resource pipeline

Text rendering SHALL use platform-independent bitmap font descriptors with glyph metrics, baseline, tracking, kerning, explicit semantic role, integer scaling, and documented source/license provenance. Measurement, alignment, bounded layout, black/white rasterization and clipping SHALL consume the same descriptor selected by the role. The repository SHALL include a repeatable offline conversion path and stale-output check for every compiled font resource.
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

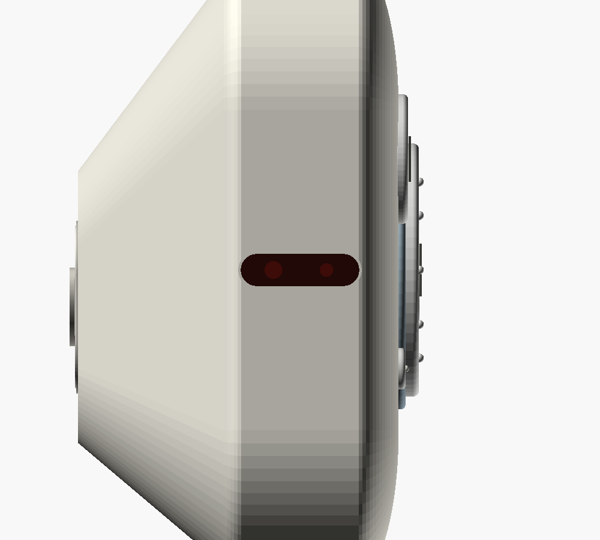
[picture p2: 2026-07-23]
assets/industrial-design/3d/cadenza-concept-v1-ir-left.png

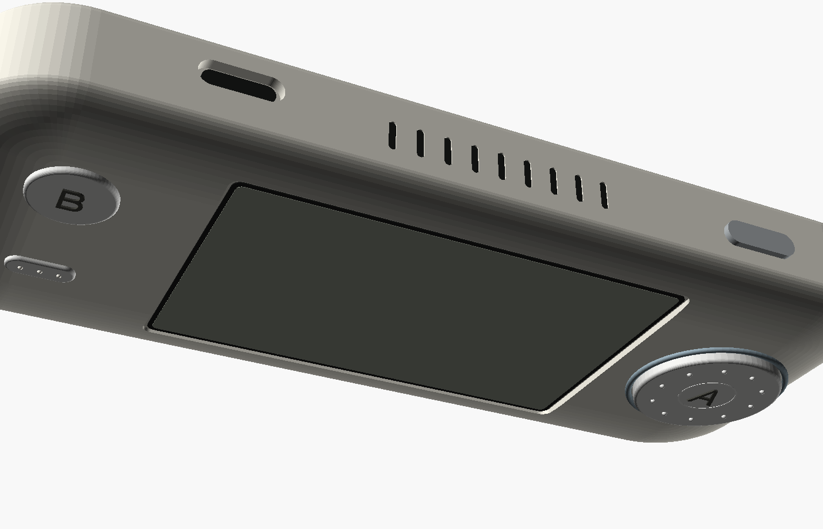
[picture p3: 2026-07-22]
assets/industrial-design/3d/cadenza-concept-v1-preview.png

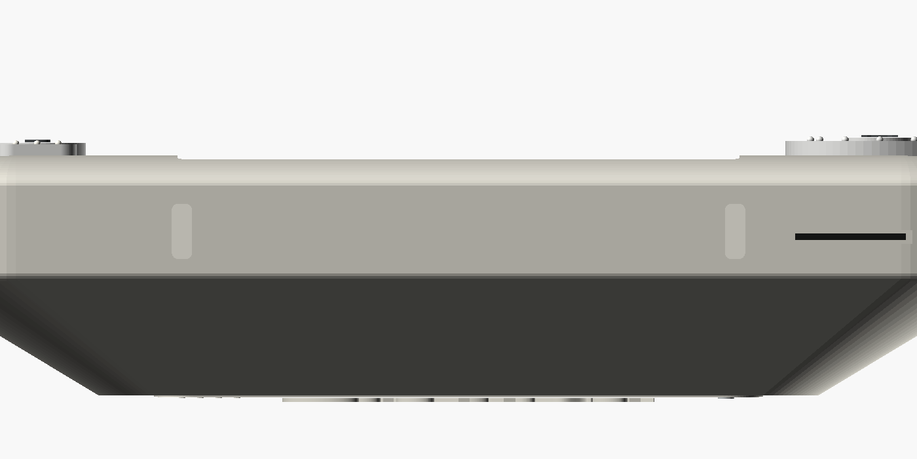
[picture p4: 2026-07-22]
assets/industrial-design/3d/cadenza-concept-v1-bottom.png

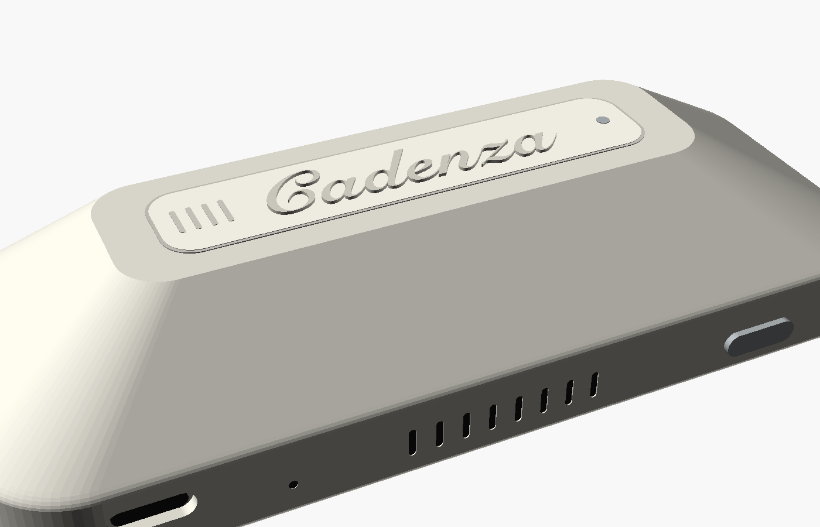
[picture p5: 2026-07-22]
assets/industrial-design/3d/cadenza-concept-v1-back-pod-preview.png

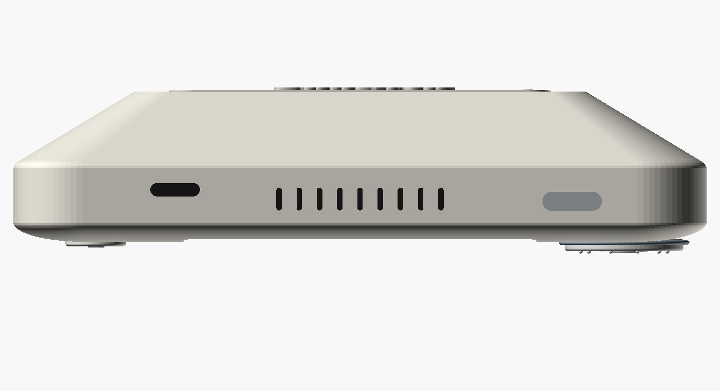
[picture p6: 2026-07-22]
assets/industrial-design/3d/cadenza-concept-v1-top.png

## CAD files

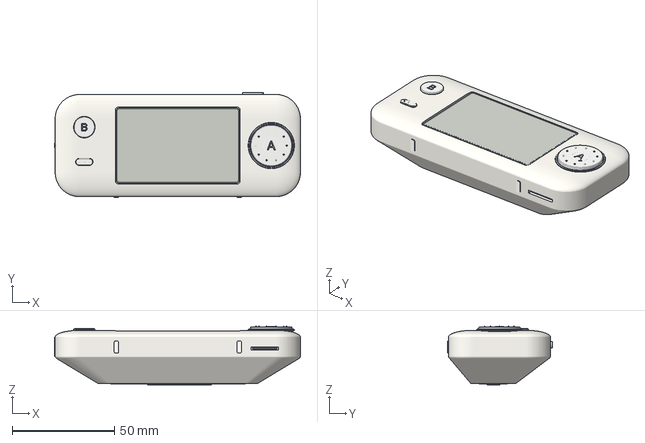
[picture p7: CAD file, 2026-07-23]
assets/industrial-design/3d/cadenza-concept-v1.3mf
120.3 x 51.2 x 28.7 mm

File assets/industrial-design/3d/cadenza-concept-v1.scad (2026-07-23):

// Cadenza compact handheld — industrial-design concept model V1
// Units: millimetres. This is a visual/space concept, not production CAD.

$fn = 72;

body_w = 120;
body_h = 50;
body_d = 16;
rear_wedge_depth = 10;

screen_glass_w = 62.8;
screen_glass_h = 42.82;
screen_view_w = 58.8;
screen_view_h = 35.28;
screen_aperture_w = 60.0;
screen_aperture_h = 36.5;
screen_x = 0;

pearl = [0.84, 0.83, 0.79];
pearl_highlight = [0.93, 0.92, 0.88];
button_gray = [0.816, 0.816, 0.808]; // screen approximation: PANTONE Cool Gray 2 C
button_highlight = [0.86, 0.86, 0.85];
graphite = [0.10, 0.105, 0.10];
display_gray = [0.55, 0.57, 0.52];
label_gray = [0.245, 0.245, 0.225]; // screen approximation: PANTONE Black 7 C
metal_silver = [0.62, 0.64, 0.65];
ring_silver_blue = [0.53, 0.60, 0.64]; // muted cool silver-blue; PANTONE 7544 C direction

module pebble(size = [106, 50, 16], plan_r = 12, edge_r = 3.4) {
    core = [size[0] - 2 * plan_r, size[1] - 2 * plan_r, size[2] - 2 * edge_r];
    minkowski() {
        cube(core, center = true);
        scale([plan_r, plan_r, edge_r]) sphere(1);
    }
}

module rounded_plate(size = [10, 10, 1], radius = 2) {
    linear_extrude(height = size[2], center = true)
        offset(r = radius)
            square([size[0] - 2 * radius, size[1] - 2 * radius], center = true);
}

module capsule_slot(width, height, depth) {
    hull() {
        translate([-(width - height) / 2, 0, 0]) cylinder(h = depth, r = height / 2, center = true);
        translate([ (width - height) / 2, 0, 0]) cylinder(h = depth, r = height / 2, center = true);
    }
}

// Instrument-like keycap: a broad, nearly flat crown with a small continuous
// shoulder radius. This avoids both a raw cylinder and an over-soft pillow.
module softened_round_button(diameter, core_h, edge_r) {
    minkowski() {
        cylinder(h = core_h, d = diameter - 2 * edge_r, center = true);
        sphere(r = edge_r, $fn = 36);
    }
}

module softened_capsule_button(width, height, core_h, edge_r) {
    minkowski() {
        capsule_slot(width - 2 * edge_r, height - 2 * edge_r, core_h);
        sphere(r = edge_r, $fn = 36);
    }
}

// Rounded annular section for a jewellery-like bezel instead of a sharp,
// stacked cylindrical ring.
module rounded_control_ring(outer_d, inner_d, rise) {
    rotate_extrude(convexity = 10)
        translate([(outer_d + inner_d) / 4, 0, 0])
            scale([(outer_d - inner_d) / 4, rise]) circle(r = 1);
}

// Capsule cut/insert on the left short end. The long axis follows the body
// thickness (Z), matching the quiet horizontal window seen on handheld IR
// remotes; shallow cylinder depth follows the body X axis.
module left_end_capsule(length, height, depth, x) {
    hull() {
        for (z = [-(length - height) / 2, (length - height) / 2]) {
            translate([x, 0, z])
                rotate([0, 90, 0]) cylinder(h = depth, d = height, center = true);
        }
    }
}

module face_label(value, size, at, z) {
    color(label_gray)
        translate([at[0], at[1], z])
            linear_extrude(height = 0.22)
                text(value, size = size, halign = "center", valign = "center",
                     font = "Arial:style=Regular");
}

module enclosure() {
    color(pearl)
        difference() {
            // One continuous moulded exterior: the rear wedge is part of the
            // same base volume as the rounded handheld body, not an add-on.
            hull() {
                pebble([body_w, body_h, body_d], 12, 3.4);
                translate([0, -3.0, -body_d / 2 - rear_wedge_depth + 1.0])
                    rounded_plate([78, 22, 2.0], 6.0);
            }

            // Shallow screen pocket: the cover surface sits below the pearl
            // shell, leaving a narrow protective lip around the aperture.
            translate([screen_x, 0, body_d / 2 - 0.15])
                rounded_plate([screen_aperture_w + 1.0,
                               screen_aperture_h + 1.0, 1.50], 1.35);

            // Top-edge USB-C charging port, moved inward from the left end.
            translate([-32, body_h / 2 - 0.35, -1.0])
                rotate([90, 0, 0]) capsule_slot(10, 3.4, 2.4);

            // Nine visually identical top slots: the centre slot is the mic
            // inlet, while the four slots on either side serve the speaker.
            // Their internal acoustic chambers remain fully separated.
            for (x = [-14 : 3.5 : 14]) {
                hull() {
                    for (z = [-0.9, 2.1]) {
                        translate([x, body_h / 2 - 0.35, z])
                            rotate([90, 0, 0]) cylinder(h = 2.4, d = 0.95, center = true);
                    }
                }
            }
            // MicroSD sits alone at the bottom-right corner.
            translate([42.5, -body_h / 2 + 0.4, -0.8])
                rotate([90, 0, 0]) cube([13.5, 1.5, 3.0], center = true);

            // Shallow pocket for a flush smoked IR transmit/receive window on
            // the left short end. No emitter package is exposed externally.
            left_end_capsule(10.0, 3.0, 2.2, -body_w / 2 + 0.45);
        }

    // Dark recesses immediately behind the USB-C and MicroSD openings.
    color(graphite) {
        translate([-32, body_h / 2 - 1.25, -1.0])
            rotate([90, 0, 0]) capsule_slot(8.6, 2.3, 0.5);
        translate([42.5, -body_h / 2 + 1.25, -0.8])
            rotate([90, 0, 0]) cube([12, 0.7, 0.5], center = true);
    }

    // Closed deep-wine smoke optical lens, slightly crowned rather than cut
    // through like a connector. The production resin must pass the selected
    // IR wavelength while still hiding the electronics in normal light.
    color([0.16, 0.045, 0.035])
        left_end_capsule(9.6, 2.6, 0.34, -body_w / 2 - 0.08);

    // Two extremely restrained optical ghosts behind the smoked cover make
    // its purpose legible: a larger emitter optic and a smaller receiver eye.
    // They are visual concept cues, not exposed packages.
    color([0.31, 0.055, 0.040]) {
        translate([-body_w / 2 - 0.265, 0, -2.15])
            rotate([0, 90, 0]) cylinder(h = 0.035, d = 1.45, center = true);
        translate([-body_w / 2 - 0.265, 0, 2.15])
            rotate([0, 90, 0]) cylinder(h = 0.035, d = 1.10, center = true);
    }

    // Two tiny moulded shell ridges create the bottom footprint. They are not
    // separate dark rubber strips and should almost disappear visually.
    for (x = [-30, 30]) {
        color(pearl_highlight)
            translate([x, -body_h / 2 - 0.10, -0.2])
                rotate([90, 0, 0]) rounded_plate([2.2, 6.0, 0.42], 0.7);
    }
}

module display() {
    // The physical 62.8 x 42.82 mm glass envelope is buried under the front
    // enclosure. Only a narrow dark aperture remains visible around the LCD;
    // the mounting border and adhesive area are hidden by the pearl shell.
    color(graphite)
        translate([screen_x, 0, body_d / 2 - 0.65])
            rounded_plate([screen_aperture_w, screen_aperture_h, 0.14], 1.1);
    color(display_gray)
        translate([screen_x, 0, body_d / 2 - 0.56])
            rounded_plate([screen_view_w, screen_view_h, 0.08], 0.8);
}

module left_buttons() {
    // B remains the secondary action key. Only a shallow ellipsoidal dome is
    // exposed; a broad flat crown keeps it precise rather than pillow-like.
    color(button_gray)
        translate([-45.7, 9.0, body_d / 2 + 0.15])
            softened_round_button(10.5, 0.35, 0.45);

    // Menu is deliberately smaller and quieter: a low horizontal capsule,
    // not another action button competing with B or A.
    color(button_gray)
        translate([-45.7, -8.0, body_d / 2 + 0.10])
            softened_capsule_button(8.5, 3.4, 0.20, 0.35);

    // Three quiet dots identify Menu directly on the keycap.
    for (x = [-48.0, -45.7, -43.4]) {
        color(pearl_highlight)
            translate([x, -8.0, body_d / 2 + 0.55])
                sphere(d = 0.58);
    }

    face_label("B", 3.7, [-45.7, 9.0], body_d / 2 + 0.78);
}

module a_controller() {
    controller_x = 45.7;

    // A restrained cool silver-blue rounded bezel adds identity while keeping
    // the active face matte and visually quiet.
    color(ring_silver_blue)
        translate([controller_x, 0, body_d / 2 + 0.16])
            rounded_control_ring(22.6, 20.8, 0.40);

    color(button_gray)
        translate([controller_x, 0, body_d / 2 + 0.55])
            softened_round_button(20.5, 1.20, 0.50);

    // A faint centre ring marks the press zone without stacking another
    // cylindrical button on top of the rotary surface.
    color(button_highlight)
        translate([controller_x, 0, body_d / 2 + 1.66])
            difference() {
                cylinder(h = 0.08, d = 8.2, center = true);
                cylinder(h = 0.10, d = 7.7, center = true);
            }
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

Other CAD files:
assets/industrial-design/3d/cadenza-concept-v1.stl

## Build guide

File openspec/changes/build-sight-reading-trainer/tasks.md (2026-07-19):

## 1. 规格与验证基线

- [x] 1.1 校验调研记录中的版本、commit、许可证、源码依据与采用/不采用结论，并通过 OpenSpec 严格校验
- [x] 1.2 为音高拼写、洗牌袋、关卡题库、输入状态机与音乐音符播放补充先失败的单元/集成测试

## 2. 受控音乐音符播放

- [x] 2.1 增加受 `SoundPlay` capability 约束的 `MusicalNoteSet`、系统命令与音频命令，并覆盖数量和 MIDI 范围校验
- [x] 2.2 实现固定音色的 MIDI 音高转换、单音/和弦播放、Replay 重启语义及普通队列水位策略
- [x] 2.3 覆盖频率、四声部上限、静音、StopAll、无削波、确定性与归零尾部的 PCM/队列测试

## 3. SIGHT 训练模型与交互

- [x] 3.1 实现 `SpelledPitch`、固定唱名、三个关卡题库、常用大小三和弦与无直接重复的确定性洗牌袋
- [x] 3.2 实现关卡选择、问题、答案三态交互，确保问题态转轮无动作且答案态默认聚焦 `NEXT`
- [x] 3.3 覆盖 Reveal、Replay、Next、Level、长按系统菜单及重新进入 App 的行为测试

## 4. 五线谱渲染与字形资产

- [x] 4.1 建立 Bravura 子集字形的离线转换、许可证归属、生成物可复现性与尺寸约束
- [x] 4.2 实现双谱表、谱号、音符、符干、加线、和弦错位、升降号及答案布局的整数像素渲染
- [x] 4.3 为 400×240 与 320×170 两种 profile 增加边界音、相邻和弦音与状态页快照验证

## 5. App 与 Launcher 集成

- [x] 5.1 增加稳定的 `kSightAppId`、App 源文件、构建清单及资源声明
- [x] 5.2 在固件、桌面与 headless 入口中按 Timer → SIGHT → Motion 注册，并更新顺序、切换与 capability 测试
- [x] 5.3 验证 App 退出、切换、静音及系统菜单期间不会遗留持续音频或破坏既有交互音效

## 6. Launcher 封面评审与集成

- [x] 6.1 在 `review/2026-07-19/build-sight-reading-trainer/` 生成、清理并检查 SIGHT 灰度 master 与两种尺寸的 1-bit 像素候选稿
- [x] 6.2 向用户展示实际像素候选稿并取得明确视觉基线批准
- [x] 6.3 仅在批准后打包正式头文件、接入 SIGHT AppCover，并通过 cover provenance 与尺寸检查

## 7. 全量验证、文档与提交

- [x] 7.1 运行相关单测、集成测试、快照、桌面/headless/固件构建与资源体积检查，记录真实结果
- [x] 7.2 更新用户文档与验证记录，明确首版范围、真实硬件试听状态及后续 Level 扩展边界
- [x] 7.3 对照 proposal、design、spec 与 tasks 做逐项审计，确认无未完成项或无依据声明
- [x] 7.4 检查最终 diff 与仓库状态，创建包含完整 SIGHT 功能的提交

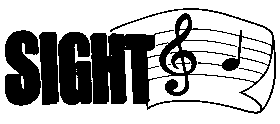
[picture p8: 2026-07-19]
assets/launcher-covers/review/2026-07-19/build-sight-reading-trainer/sight-illustrated-v3-dimensional/candidate/review/sight_t_embed_threshold.png

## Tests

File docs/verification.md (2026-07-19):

# P0–P7 and interaction-audio verification record

Verified on macOS on 2026-07-18. This file records authoritative gates, not a
claim that physical-device P8 work has happened.

| Phase | Evidence |
| --- | --- |
| P0 decisions | `project-vision.md`, `reference-research.md`, and `engine-adoption-decision.md`; SDL3/U8g2/doctest/stb/gif-h adopted at narrow seams, LVGL/Tweeny full-runtime adoption rejected by measured spikes |
| P1 decoupling | `cadenza_portable_core_compile_probe` and `cadenza_shared_source_audit`; T-Embed and desktop adapters feed shared `InputReducer`, App, Runtime, canvas, and animation code |
| P2 simulator MVP | `cadenza_desktop_smoke_tests` visits every registered App including Gallery through desktop input mapping; SDL dummy launch succeeds for the real executable |
| P3 debugging | simulation controller, PNG, recording, desktop model, device-preview, and diagnostic tests cover pause/step/speed/fixed-real modes, capture, GIF finalization, HUD data, and invariance |
| P4 animation core | easing/Tween/composition/Spring suites cover endpoints, interior vectors, delay, finite/infinite repeat, yoyo/reverse, callback, seek, pause, large delta, capacity, and diagnostics |
| P5 presentation | transition/effects/particle/frame/state tests plus Gallery pages, reduced-motion propagation, deterministic cross-cycle replay, and visible reversible scrub for Spring/selection/camera/particles |
| P6 graphics | guarded framebuffer, U8g2 raster/font golden tests, bitmap composition/flip/XOR/clipping, atlas, dither phase, and off-screen immutability |
| P7 regression | 32/32 normal, 32/32 warnings-as-errors, and 32/32 ASan+UBSan tests; app and representative Gallery snapshots at both profiles emit PNG artifacts on mismatch |

Fresh completion gates:

- host Debug tests: 32/32 pass;
- strict AppleClang build (`-Wall -Wextra -Wpedantic -Werror`): 32/32 pass;
- ASan+UBSan host build: 32/32 pass;
- SDL3 3.4.12 dummy-driver executable smoke: pass at 320×170 @ 2× and
  400×240 @ 4× with HUD and device frame enabled;
- PlatformIO T-Embed clean release compile: pass;
- firmware size: 82,616 B RAM, 316,409 B Flash;
- `git diff --check`, source-manifest audit, platform-coupling audit, and
  third-party pin/license audit: pass.

The final temporal Gallery audit sampled Spring, selection, camera, and
particles at five frames across two cycles and both profiles. It caught and
fixed one-shot demos, zero-delta CameraShake state mutation, non-functional
stateful scrubbing, and a hard-coded particle origin. The accepted particle
midpoint snapshots now remain centered at both 320×170 and 400×240.

## Interaction audio automated evidence

Verified on macOS on 2026-07-18 after the audio implementation and asset
contract were added:

| Gate | Evidence |
| --- | --- |
| Research/adoption | 16 fixed repositories with commit/license/source boundaries, official Playdate docs, public-device recording analysis, and explicit adopt/reject decisions in the three `audio-*-research.md` documents |
| Portable synth | wavetable sine, triangle, PolyBLEP square, deterministic xorshift noise, precomputed exponential envelope, finite parameter rejection, minimum ramps, saturating mix, exact ending silence and four-voice priority/age/smooth-steal tests |
| Concurrency/control | fixed 16-slot SPSC FIFO, four critical slots, no producer overwrite, Navigate cooldown, full-queue overflow evidence, and out-of-band Muted/StopAll safety mailbox; a saturated 16-critical-cue queue still renders immediate zero |
| Semantic integration | Input/Action/Surface/Outcome/System expose 18 stable cues including TimerComplete；Navigate/Boundary/Confirm/Back/Toggle/MenuOpen/MenuClose/Reject 路由由 bundled Apps、app-open 与 System Menu 测试覆盖；Menu 开合不再复用 Confirm/Back，显式 Home 动作仍使用 Back transition |
| Headless PCM | a real Launcher turn renders 2,048 deterministic samples, hash `14994789996363689834`, nonzero bounded peak; every cue also has a 44,100-sample golden and exact silent tail |
| SDL | SDL3 3.4.12 dummy callback consumes independently of App updates, no-device failure preserves portable service, stop prevents later callbacks; real executable passes three frames at both profiles with dummy video+audio drivers |
| T-Embed adapter | host test locks GPIO 7/5/6 and right-left mono duplication; the real adapter is compiled against ESP-IDF/FreeRTOS stubs and injected with install, pin, task, partial-write and fatal-write failures; locked PlatformIO Arduino-ESP32 2.0.17 release compiles and links the independent core-0 legacy-I²S task |
| Asset workflow | all 16 cues plus four family demos export as valid 44.1 kHz, 16-bit mono RIFF/WAVE; local Select/Turn On/Turn Off references are rejected by the shared-source audit and are not build inputs |

## Activation Timer 软件验证

2026-07-19 的 `build-activation-timer-app` 结果见
[`activation-timer-implementation-report.md`](activation-timer-implementation-report.md)：
normal/strict/ASan+UBSan 各 73/73，双 profile SDL dummy、PlatformIO T-Embed、
OpenSpec/source/research/diff gates 通过。headless 和 desktop InputReducer E2E 覆盖
后台计时、System Menu Home、其他 App/transition 到期、held-button capture、确认停音
和再次开始。实体旋钮手感、屏幕、响度、疲劳与长时间运行仍待真机，不以软件结果代替。

Fresh gates after integration with the system-service foundation and the
Confirm/Back calibration fix:

- normal host: 50/50;
- AppleClang warnings-as-errors: 50/50;
- ASan+UBSan: 50/50;
- SDL dummy executable: T-Embed and Sharp profiles pass;
- PlatformIO firmware: 98,808 B RAM (30.2%), 358,805 B Flash (11.4%);
- four-voice ABI: `AudioEngine` 592 B, `InteractionSoundService` 1,728 B;
  no per-sample transcendental function or allocation; ESP32 runtime timing is
  still a physical-board measurement;
- approved-prototype correlation: Confirm 0.984379, Back 0.979893; the real App
  open/System Menu Home path renders their matching deterministic goldens;
- OpenSpec strict validation, source-manifest audit, platform-leakage audit and
  `git diff --check`: pass.

## System Overlay 软件验证

2026-07-18 的 `build-system-overlay-runtime` 软件结果：

- 参考 clone/commit/license/source/build-dependency audit：通过；
- input owner、suspend lifecycle、transition defer、typed setting、capacity/
  diagnostics tests：通过；
- 320×170 与 400×240 System Menu framebuffer golden：通过；
- desktop scripted path 访问全部 bundled App，并通过 System Menu Home 返回：通过；
- PlatformIO firmware：99,000 B RAM、361,705 B Flash；
- ESP-IDF 5.5 connectivity candidate：binary 1,188,496 B，static D/IRAM
  231,143 B；
- 实体 T-Embed 的 650 ms 手感、屏幕可读性和 100 次循环：待硬件，不能由软件门禁代替。

## Continuous Launcher 软件验证

`add-continuous-launcher-navigation` 增加以下独立证据；最终数字以该变更归档前的
fresh gate 为准：

- 逻辑目标使用无界整数、视觉位置连续追赶，并在 settled 后安全重基；单步中间态、
  首尾单 pitch 环绕、快速同向/反向 retarget、移动中打开和空目录均有自动化用例；
- Normal 与 Reduced Motion 均覆盖单调无 overshoot、精确 settled、反向 retarget
  不越界和 profile 中途切换；Normal 为 250 ms，Reduced 为 160 ms；
- Settings 的 Launcher 行通过 `SettingsWrite` command 同帧切换 Vertical/Horizontal，
  新 service session 默认恢复 Vertical；
- Launcher 快照矩阵覆盖 320×170/400×240、横纵 settled、确定中间帧、内置 Cover、
  fallback，以及按下/启动代表捕获；代表捕获必须与对应 neutral Cover 像素一致。
  交互测试另行验证 Cover 不接收状态、固定 layout bounds 与静默 viewport clip，
  避免点击变图或横向移动时内容重排；
- desktop 真实输入路径覆盖 Settings 切方向、System Menu Home/Resume、长按 release
  后稳定帧恢复、未 settled 时打开最新选择。本帧 Launcher 的 Invalid/Clipped
  geometry 计数为零；HUD 只显示本帧事件，无新事件时显示 `DIAG OK`，但历史环形
  日志仍保留供审计。

2026-07-18 fixed-ratio Cover 最终门禁证据：

- `cadenza_apps_tests`、`cadenza_launcher_snapshot_tests` 与
  `cadenza_desktop_smoke_tests` 定向门禁 3/3 通过；Timer 启动捕获与 neutral Cover
  hash 相同，Motion press 捕获与 neutral Cover hash 相同；
- host 全部 target 编译成功；使用带 Pillow 的项目 Python 时 70/70 项 CTest
  通过。八个母图来源检查证明各 profile PBM 直接来自对应 PNG，八个 Cover
  asset check 证明 packed header 与 PBM 一致；`cadenza_app_snapshot_tests` 与新增的
  `cadenza_launcher_snapshot_tests` 均已逐图审阅并批准固定比例完整画面；
- 两个 profile 的八个 PBM 均通过高分辨率母图→目标尺寸的像素级检查；T-Embed
  不再从已二值化的 350×155 PBM 二次缩小。Motion 的黑色连通块由 78 降至 56，
  ≤4 像素碎片由 43 降至 23，Settings 的对应计数由 36/17 降至 32/13；
- SDL 3.4.12 可执行文件分别以全新 dummy-driver 进程运行 320×170 与 400×240，
  `--frames 3 --overlay` 均正常退出；desktop smoke 的当前帧诊断审计通过；
- SDL 默认 `reflective` 呈现将 ink/paper 映射为 `#322F28`/`#B1AEA7`，显式
  `--palette pure` 保留 `#000000`/`#FFFFFF`；解析、精确 RGBA 值、非法 palette
  拒绝和双模式全新进程均通过。palette 不进入 framebuffer 与截图 hash；
- Retina Mac 的真实 SDL 进程报告 logical 640×340、backing 1280×680、density
  2.00x；texture 仍使用 nearest-neighbor 与 integer logical presentation；
- PlatformIO `cadenza-t-embed` release 编译成功：RAM 99,184 / 327,680 B
  (30.3%)，Flash 408,997 / 3,145,728 B (13.0%)；双 profile Cover 相比前一版
  增加 43,084 B flash，未增加静态 RAM；
- `cadenza_shared_source_audit` 与 `cadenza_portable_core_compile_probe` 2/2 通过，
  `openspec validate add-continuous-launcher-navigation --strict` 与
  `git diff --check` 通过。

反射色板只是对良好环境光下 Memory LCD 的近似，不能模拟无背光、观看角度、环境
亮度或真实黑白反差。软件证据也不能证明 T-Embed 的 30 FPS、TFT 撕裂、拖影或
高频 1-bit 相位闪烁。实体步骤见 `launcher-card-reference-research.md`。当前状态为
`fixed-ratio Cover artwork and platform gates complete / hardware motion acceptance pending`。

## 2026-07-19 非 Timer Cover 插画升级

- MOTION、SETTINGS 与 ANIMATION GALLERY 的新母图、350×155 / 280×124
  reflective 像素基线均取得用户明确批准；TIMER source/PBM/T-Embed PBM 的 SHA-256
  仍分别为 `e5e8455f652268f15614b8d48720e5e11304a3b4d70e30ca62af1bd938a14480`、
  `8406756202a4a9de974d133cd4e5de740819c34419d90f0ff47fdb51836a85bb`、
  `87a00f5298e5bfc682a508608ab1b03030f8649f6677be9ef634b323cd764cb7`。
- SETTINGS v1 因连续棚拍光照、软阴影和弱外轮廓在正式预览中呈现“照片转网点感”
  而撤销；v2 改用硬边离散插画平面和连续实色控制台轮廓。正式 PBM 与批准候选在
  两个 profile 中逐像素相同。
- Cover skill pipeline 重构为 master、pixel、approval、integration 四类门禁；
  `prepare_cover.py --edge-cleanup` 自动生成硬阈值、ordered-dither pure/reflective
  和 nearest-neighbor 4× 审阅图。新增 6 项脚本回归测试覆盖轮廓 guard、宽灰面保留、
  二值输入不变、硬阈值和 4× nearest-neighbor 像素块。
- source→PBM、PBM→header、静态 Cover、handoff、Launcher/App snapshots 与真实 SDL
  dummy executable 均通过；完整 host 为 81/81。
- PlatformIO `cadenza-t-embed` release 编译成功：RAM 100,112 / 327,680 B
  (30.6%)，Flash 463,981 / 3,145,728 B (14.7%)；`git diff --check` 与 OpenSpec
  strict validation 通过。

软件预览不能替代 Memory LCD 的一像素移动闪烁、反射环境和真机观看距离验收；
这些物理项继续标记为 hardware motion acceptance pending。

## 2026-07-19 About identity screen

- Settings 的 `ABOUT: OS` 从 Reject 占位行为改为可进入的独立页面；短按返回
  Settings，长按仍由系统菜单处理，进入 App 时不会残留旧 About 状态。
- 用户明确批准钢琴意象、`CADENZA OS` 与花体 slogan
  `A Space to Improvise.` 的双 profile 1-bit 基线；随后按用户反馈裁去内部白边放大
  Logo，并把署名降为最小 Footer 字号的 `Made by Tapir`。
- 正式 350×155 / 280×124 PBM 使用三档色调与显式 `--edge-cleanup`；source→PBM、
  PBM→header 三项可复现检查通过，1× reflective、硬阈值与 4× nearest-neighbor
  审阅无裁切、断字或关键轮廓 Bayer fringe。
- `cadenza_apps_tests` 的双 profile About open/render/return case 通过；完整 host
  83/83 通过，`git diff --check` 通过。
- PlatformIO `cadenza-t-embed` release 编译成功：RAM 100,528 / 327,680 B
  (30.7%)，Flash 476,733 / 3,145,728 B (15.2%)。

软件与反射色板预览不能替代真机观看距离下的花体 slogan、细小署名和 4×4 dither
验收；该项保留为 hardware visual acceptance pending。

## 2026-07-19 SIGHT 识谱训练

- `docs/sight-reading-reference-research.md` 锁定 Playdate SDK 3.1.0、MusicXML
  4.0、VexFlow 4.2.6 与 Bravura `02e8ed29` 的版本、许可证、关键源码语义和
  采用/不采用边界；OpenSpec `build-sight-reading-trainer` strict validation 通过。
- SIGHT 默认 C3–C5 自然单音，另有 C2–C6 自然单音与 12 个 root 的 major/minor
  原位三和弦；题库使用确定性 shuffle bag。Question 转轮无动作，click 揭晓并
  播放；Answer 默认 `NEXT`，可选择 `REPLAY / NEXT / LEVEL`。
- Bravura 四字形离线子集、双大谱表、加线、相邻和弦音错位、升降号和两行答案
  布局均通过 320×170 / 400×240 geometry 与快照验证。24 个和弦的 Question 和
  Answer 逐题检查无 clipped/invalid geometry，长答案不换行溢出。
- 受 `SoundPlay` capability 约束的 `MusicalNoteSet` 只接受 1–4 个 MIDI 21–108
  音符；固定音色覆盖 Replay 重启、四声部、队列 reserve、静音、StopAll、确定性、
  无整数环绕和精确归零尾部。SIGHT 定向套件为 26/26 case、532/532 assertion。
- 用户批准最终卷谱插画和增强灰阶立体字 Cover；`--levels 5 --edge-cleanup` 的
  350×155 / 280×124 source→PBM 与 PBM→header 检查、静态 Cover、Launcher
  snapshots 和 handoff snapshots 全部通过。
- normal、AppleClang warnings-as-errors 与 ASan+UBSan 均为 90/90；SDL 3.4.12
  dummy executable 通过；PlatformIO T-Embed release 为 RAM 100,928 / 327,680 B
  (30.8%)、Flash 496,245 / 3,145,728 B (15.8%)；`git diff --check` 通过。

自动化只证明音高、PCM 边界、路由、显示和构建；尚未在原版 T-Embed 扬声器上
试听单音、三和弦的音色、响度和 Replay 手感，也未在 Memory LCD 上验收 Cover
移动时的网点闪烁。首版明确不含语音识别、评分、间隔复习、钢琴键位、持久化、
调号、节奏、转位或七和弦。

## Delta-spec completion audit

This is the requirement-by-requirement audit, rather than an inference from a
single broad green build:

| Delta requirement | Direct evidence | Status |
| --- | --- | --- |
| same core across platforms | one `InteractionSoundService::render` used by headless, SDL and I²S; shared-source audit and both platform builds | automated pass |
| SDL callback output/lifecycle | dummy callback/no-device/stop tests, real dummy process at both profiles, invalid audio driver exits 0 with graphics active | automated pass |
| T-Embed I²S task | configuration/frame tests, injected driver/task/write failures against the real adapter source, locked firmware link | automated pass; electrical output pending hardware |
| verification/truthful declaration | normal/strict/sanitized/SDL/firmware/OpenSpec gates plus the physical script below | automated pass; listening explicitly pending |
| fixed realtime render | idle/nonzero/end-zero tests, fixed arrays and source audit, no allocation in voice/command/sample path | automated pass |
| bounded primitives | wavetable sine, triangle, PolyBLEP edge, seeded noise, exponential/linear envelope, finite rejection/clamping and all-cue ramp tests | automated pass |
| four voices/smooth steal | priority, oldest-age selection, low-priority rejection, 64-sample release and outgoing-gain regression | automated pass |
| saturating mix | four over-gain voices reach int16 bounds without wrapping; ASan/UBSan pass | automated pass |
| fixed SPSC queue | FIFO, reserve, overflow/no-replay and saturated-critical-queue immediate mute tests | automated pass |
| semantic vocabulary | 16 stable names/definitions/goldens across four families; Runtime/App tests preserve all seven existing business routes and TimerComplete | automated pass |
| restrained directional language | per-cue duration/tone-count/ramp tests; Confirm/ToggleOn up and Back/ToggleOff down | automated pass; taste pending hardware |
| high-frequency suppression | one cue for large-turn frame, 25 ms cooldown, drop/no-later-play and post-cooldown tests | automated pass |
| volume/mute/visual equivalence | four-level cycle/order, active and saturated-queue mute, Settings immediate framebuffer change at both profiles and muted visual interaction | automated pass |

## Physical T-Embed audio acceptance script

Automation proves format, routing, timing state, deterministic PCM and firmware
linkability. It cannot prove the installed MAX98357A/speaker's pleasantness.
Use an original T-Embed in a quiet room, powered from the same source expected
for normal use:

1. Flash the verified `cadenza-t-embed` build and confirm the serial diagnostic
   `I2S audio task started`; there must be no repeated AudioUnderrun/AudioFailure.
2. At Medium, turn slowly through Launcher choices and compare selection motion
   with Navigate onset. Check every boundary, open, System Menu Home, toggle,
   About open/return, and all four Settings volume states.
3. Repeat fast rotation for 10 seconds. Sound must stop when motion stops; there
   must be no delayed tick queue, display stall or watchdog reset.
4. Trigger Confirm, Back and Reject while other tails are active. Listen for
   clicks, hard cuts, integer-like wrap distortion or one channel disappearing.
5. Switch High → Muted during an active cue. The tail must stop immediately;
   all visual interactions must remain complete while muted. Restore Low and
   confirm no old cue resumes.
6. Perform at least 50 consecutive Navigate/Confirm/Back operations at Medium.
   Score semantic clarity, comfort, family consistency, sync and fatigue from
   1–5. Default acceptance requires each first four score ≥4, fatigue ≥4, and
   no click, obvious distortion or reset.
7. Repeat once with the enclosure held normally and once on a table. Record
   firmware hash, board revision, power source, volume, scores, defects and any
   selected replacement-cue version in the asset manifest/review record.

Until this script is performed, status is **automated implementation complete,
physical sound-quality acceptance pending**. Current synthesis parameters are
an editable baseline, not a claim of final product taste.

## Deliberately unexecuted P8

The following require the physical original T-Embed and remain open: encoder
direction/debounce/high-speed behavior, long-press feel, real FPS and slowest
frame, TFT tearing, simulator-to-TFT photographed pixel comparison, animation
performance budget under real transfer cost, repeated on-device regression
after effect groups, and the audio acceptance script above. Sharp hardware
driving, persistence, sample-asset playback and new Apps remain after this main
line.

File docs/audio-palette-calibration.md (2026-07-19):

# Semantic Hierarchy 合成校准记录

> 状态：Navigate v6、ToggleOn v2、ToggleOff v2 与原创 Menu Surface V2 已通过用户 A/B；参考 WAV 仅存在于本地试听工作区，不属于仓库输入、构建依赖或产品资产。

## 校准边界

用户接受以参数合成近似还原参考声音，要求听感不得“天差地别”，并保留逐 cue fallback。这里的自动特征只负责发现数量级偏差，不代替人工听感：

- 总时长偏差不超过参考的 15% 或 2 ms（取较大者）；
- 有效响度事件数量一致，事件间静音结构不得消失；
- 主导频段保持在同一听觉区间，不得从短高频触点变成长低频音符；
- 原始 peak 不用于直接归一化产品响度，合成候选 RMS 与参考相差超过 4 dB 时必须解释或调整 event gain；
- cue 结束后回到精确数字零；连续 Navigate 不得补播历史输入；
- 用户在单音与上下文 demo 中确认没有明显身份、材质或动作轮廓偏差。

## 本地参考测量

测量口径为 44.1 kHz S16 mono 本地校准副本、全文件 Hann FFT spectral centroid、1 ms RMS block 与 -45 dBFS active threshold。SHA-256 只用于证明本次分析对象，不能用于恢复或分发参考音频。

| Cue | 本地源摘要 | 时长 | Peak / RMS | Spectral centroid | Active spans |
| --- | --- | ---: | ---: | ---: | --- |
| Navigate / Select | `877cbda83810…` | 10.431 ms | -7.71 / -24.02 dBFS | 3027 Hz | 3–6 ms |
| ToggleOn / Turn On | `cf04e7f2cc02…` | 63.424 ms | -0.07 / -19.96 dBFS | 3263 Hz | 4–15 ms、45–55 ms |
| ToggleOff / Turn Off | `6ffaa6afbff8…` | 65.125 ms | -0.05 / -20.05 dBFS | 3368 Hz | 7–15 ms、49–56 ms |

可观察结构：Navigate 是约 10 ms 文件中的单次极短高频触点；ToggleOn/Off 都是两个短事件，中间约 30 ms 数字静音。两项 Toggle 的区别来自事件时序和第二段方向，不来自持续旋律。

## 首个合成候选

候选只使用重新创作的 Sine/Triangle 频率轨迹、短 attack、预计算指数衰减和 release，不包含参考 PCM。独立 A/B 页面位于本地试听工作区 `audio-study/synth-approximation.html`。

| Cue | 时长 | Peak / RMS | Spectral centroid | 自动判断 |
| --- | ---: | ---: | ---: | --- |
| Navigate synth v6 | 10.431 ms | -8.11 / -24.3 dBFS | 波形拟合 | 四个原创阻尼共振器；去除参考底噪后的全文件相关性 0.972、归一化 RMSE 0.233；用户通过 |
| ToggleOn synth v2 | 63.492 ms | -0.10 / -18.2 dBFS | 1887 Hz | 时长/双事件通过；第二段强化上行；用户通过 |
| ToggleOff synth v2 | 64.989 ms | -0.10 / -18.3 dBFS | 2599 Hz | 时长/双事件通过；第二段强化下行；用户通过 |

频谱重心低于参考不自动判失败：参考的瞬态噪声会显著抬高 centroid，而主观身份更多由短时主频、crest factor 与双事件节奏决定。若人工判断合成版过闷或过于音符化，再增加原创高频瞬态比例，不复制参考波形。

Select v6 使用四个阻尼共振器（约 1.64、2.29、2.85、5.84 kHz），分别具有独立初相位与 0.24–0.50 ms 衰减。参数由最小二乘与局部坐标搜索得到；模型只保存频率、衰减、幅度和相位，不保存参考采样序列。v5 仍保留在本地试听工作区作为 fallback。

## 正式运行时复核

获批参数移入 portable C++ 后，以 Medium master gain 反归一化，与试听页 WAV 在共同长度内比较：Navigate 相关性 0.999878，ToggleOn 0.992850，ToggleOff 0.999870。三项均保持原事件时序；ToggleOn 首事件明确延迟 3.5 ms，避免试听稿与运行时错位。正式 15-cue PCM golden 已冻结，所有 cue 结束后精确回零。用户对最终 Select 表示“很棒就这样吧”，因此该版本进入实现基线；后续改音必须显式更新试听结论与 golden。

## Confirm / Back 回归校准

2026-07-18 兼容性复核发现，正式 C++ 的 Confirm/Back 虽然拥有确定性 golden，但没有落在用户拍板的 `09-semantic-hierarchy-full` 进入/退出原型边界。golden 只能证明错误输出没有漂移，不能证明听感移植正确。以下原创试听 WAV 仅作为本地校准输入，不是运行时或构建依赖：

| Cue | 总时长 | Peak / RMS | 第一事件 | 第二事件 | 结构边界 |
| --- | ---: | ---: | --- | --- | --- |
| Confirm | 244.989 ms | -12.41 / -23.40 dBFS | 0 ms，约 660 Hz，尾部约 170 ms | 60–64 ms，约 990 Hz，延续到 245 ms | 两段固定调音敲击，上行音程；不得变成连续上滑 |
| Back | 210.000 ms | -10.50 / -23.40 dBFS | 0 ms，约 990 Hz，尾部约 130 ms | 40–45 ms，约 590 Hz，延续到 210 ms | 不对称下行，第二段更闷；不得复用 Confirm 或旧连续下滑 |

自动门禁直接约束事件数量、offset、每段主频漂移、事件时长与总时长；测试已先对旧正式实现产生预期失败，再随校准实现转绿。修正后的正式输出与获批原型在共同长度内的相关性为 Confirm 0.984379、Back 0.979893，有效结束时间分别为 244.92 ms、209.93 ms；对应 PCM golden 已更新。

App 集成回归从 Launcher 实际打开应用，并通过显式 Home 动作返回；App open 使用 Confirm，Home transition 使用 Back，两者均通过 `SystemServiceHost`。由此同时锁定业务语义、系统服务路由和合成输出，避免试听稿更新而 App 仍播放旧声。上下文试听导出为 `confirm-fixed.wav` 与 `back-fixed.wav`，仅用于人工验收，不进入构建。

## Menu Surface V2 校准

System Menu 原先展开复用 Confirm、收起复用 Back。两者虽然方向不同，却同属 210–245 ms 的双敲 Action，导致高频 Surface 操作都被听成难听的 confirm。修订后新增同时起音、无第二敲击的 MenuOpen/MenuClose；试听稿直接使用正式 `AudioEngine` 与 Medium master gain 生成，不依赖外部参考音频：

| Cue | 有效时长 | Peak / RMS | 主 tone | 触感 tone | 用户结论 |
| --- | ---: | ---: | --- | --- | --- |
| MenuOpen V2 | 159.9 ms | -17.39 / -28.89 dBFS | Sine，约 340→680 Hz，指数衰减 | 同时起音的 48 ms 低增益 Noise | 更低、更长且上升幅度明确；通过 |
| MenuClose V2 | 139.9 ms | -17.75 / -30.22 dBFS | Sine，约 640→290 Hz，指数衰减 | 同时起音的 42 ms 低增益 Noise | 更低、更长且下潜幅度明确；通过 |

正式独立 PCM golden 分别为 `0x7E65C35377921CA6` 与 `0x68D82E874AB181F1`。真实 Runtime 在先播放 App Confirm、再展开和收起 Menu 的上下文中，golden 分别为 `0xFFD867CDEBDCD06A` 与 `0xBC8674B8C5CA39A5`；Noise 状态会随此前 voice sequence 确定性演进，因此上下文 hash 与 fresh-service hash 不同。两 cue 均在 0.20 秒视觉形变内结束并与动画起点同帧提交。

## Fallback

任一 cue 的合成近似未通过人工 A/B 时，先继续调整对应 palette 参数；若受限合成器仍无法达到可接受听感，则为该 cue 单独提出 sample voice 变更。不得在当前实现中悄悄嵌入本地参考 WAV。

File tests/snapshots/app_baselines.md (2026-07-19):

# Bundled App framebuffer baselines

These FNV-1a hashes cover the active bytes of the canonical row-major,
MSB-first framebuffer plus its dimensions. They were approved after rendering
PBM artifacts with `cadenza_dump_headless_pbm` and visually inspecting PNG
conversions on 2026-07-19.

Capture point: a fresh `HeadlessHost`; Launcher is its initial render. The two
Launcher Gallery-selection cases apply one `turn = 3` frame and prove the
longest bundled application name stays inside its card. Each other App is
opened directly and captured on the first stable render after the 0.32-second
transition completes. No normal App update runs after completion.

| Profile | App | Hash (decimal) |
| --- | --- | ---: |
| 320×170 | Launcher | 4407872121496200056 |
| 320×170 | Timer Ready 10:00 | 12921254497184521768 |
| 320×170 | Motion | 1593956483296057867 |
| 320×170 | Settings | 9428840863604149705 |
| 320×170 | Animation Gallery | 14139291840108583961 |
| 400×240 | Launcher | 14360345327951497471 |
| 400×240 | Timer Ready 10:00 | 4523606151491982558 |
| 400×240 | Motion | 2802791382376082090 |
| 400×240 | Settings | 13956664939219996363 |
| 400×240 | Animation Gallery | 13234575752027769465 |

Settings hashes were re-approved on 2026-07-19 after the right-pane list was
changed to fill the full remaining width/height (title-sized left rail, equal
row partition, outlined rows) while keeping selection-follow scroll on overflow.

Timer hashes were re-approved on 2026-07-19 after adding native industrial
numerals, centering the enlarged time body, correcting `HOLD: MENU`, and applying
the approved 2D-title/3D-dial Launcher Cover. Both profile PNGs were visually
inspected.

Launcher selection baselines:

| Profile | Launcher state | Hash (decimal) |
| --- | --- | ---: |
| 320×170 | Animation Gallery selected | 15533885305252050834 |
| 400×240 | Animation Gallery selected | 6567266582574601646 |

Launcher and handoff hashes were re-approved on 2026-07-19 after replacing the
legacy Clock artwork with the approved `TIMER` cover. The horizontal/vertical
track endpoints, launch/return transition frames, and warped Menu closing frame
were visually inspected at both profiles before updating their test constants.
The Menu opening keyframe was re-approved again after the 24 FPS reference
comparison added a 22% bottom-edge lead-in delay; its first visible frame now
keeps the top edge settled while the bottom remains at the right edge.

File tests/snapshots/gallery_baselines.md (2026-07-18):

# Animation Gallery visual baselines

These hashes capture paused 50% progress after direct knob scrubbing. They
were accepted after inspecting PBM-to-PNG renders at both supported profiles
on 2026-07-18. The selected pages cover the easing graph, a dark-field
transition, a coverage transition, particles, atlas/state animation, and
ordered dither. `cadenza_gallery_snapshot_tests` owns the executable values.

| Profile | Page | Hash (decimal) |
| --- | --- | ---: |
| 320×170 | Easing | 11440640267301194983 |
| 320×170 | Dip | 4137199271609631912 |
| 320×170 | Checker dissolve | 9878436293935264858 |
| 320×170 | Particles | 11948840630181533057 |
| 320×170 | Sprite state | 9026563825525625221 |
| 320×170 | Dither | 13029273646656056373 |
| 400×240 | Easing | 17615136595640686815 |
| 400×240 | Dip | 15534794435185275820 |
| 400×240 | Checker dissolve | 13438891652020997183 |
| 400×240 | Particles | 7317937573070898047 |
| 400×240 | Sprite state | 1640077496920006473 |
| 400×240 | Dither | 17314096927354342150 |

Accepted trade-offs: Gallery favors deterministic, inspectable scenes over
asset richness; particle scrubbing does not reconstruct particle history;
reduced motion scales feedback and camera amplitudes but preserves direct
Tween, transition, Timeline, and frame-animation scrubbing. All comfortable
defaults live in `cadenza/presentation/defaults.h`.

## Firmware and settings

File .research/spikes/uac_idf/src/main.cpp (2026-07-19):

/* CadenzaOS ESP-IDF 5.5 T-Embed firmware: Runtime + UAC2 mic + CDC. */
#include <algorithm>
#include <cstddef>
#include <cstdint>
#include <cstring>

#include "Arduino.h"
#include "esp_check.h"
#include "esp_err.h"
#include "esp_log.h"
#include "esp_timer.h"
#include "freertos/FreeRTOS.h"
#include "freertos/task.h"
#include "tusb.h"
#include "usb_device_uac.h"
#if CONFIG_CADENZA_T_EMBED_RUNTIME
#include "cadenza/apps/apps.h"
#include "cadenza/core/app_runtime.h"
#include "cadenza/core/diagnostics.h"
#include "cadenza/core/mono_canvas.h"
#include "cadenza/core/mono_framebuffer.h"
#include "cadenza/system/frame_coordinator.h"
#include "cadenza/system/system_service_host.h"
#if CONFIG_CADENZA_CONNECTIVITY_RUNTIME
#include "idf_connectivity_adapter.h"
#endif
#include "t_embed_display.h"
#include "t_embed_input.h"
#endif
#include "cadenza/voice/usb_voice_packetizer.h"
#include "cadenza/voice/usb_voice_session_bridge.h"
#include "t_embed_microphone.h"
#include "t_embed_speaker.h"
#include "uac_lifecycle_adapter.h"

namespace {

struct VoiceAdapter {
#if CONFIG_CADENZA_T_EMBED_RUNTIME
  explicit VoiceAdapter(cadenza::voice::VoiceCaptureCoordinator& coordinator)
      : capture(coordinator), packetizer(capture), sessionBridge(capture) {}
  cadenza::voice::VoiceCaptureCoordinator& capture;
#else
  cadenza::voice::VoiceCaptureCoordinator capture;
#endif
  cadenza::voice::UsbVoicePacketizer packetizer{capture};
  cadenza::voice::UsbVoiceSessionBridge sessionBridge{capture};
  std::uint64_t sequence = 0;
};

#if CONFIG_CADENZA_T_EMBED_RUNTIME
class LogDiagnosticSink final : public cadenza::DiagnosticSink {
 public:
  void emit(const cadenza::DiagnosticEvent& event) noexcept override {
    // Same filter as PlatformIO SerialDiagnosticSink: Gallery Transition
    // clip noise over CDC can starve the loop task and trip the TWDT.
    if (event.category == cadenza::DiagnosticCategory::Graphics &&
        (event.code == cadenza::DiagnosticCode::ClippedGeometry ||
         event.code == cadenza::DiagnosticCode::FullyClipped ||
         event.code == cadenza::DiagnosticCode::InvalidGeometry)) {
      return;
    }
    // Launcher emits SelectionChanged on every detent; logging that over CDC
    // during scroll was measured to steal frame budget on the UI core.
    if (event.code == cadenza::DiagnosticCode::SelectionChanged) {
      return;
    }
    ESP_LOGI("cadenza_diag", "category=%u code=%u value=%ld %s",
             static_cast<unsigned>(event.category),
             static_cast<unsigned>(event.code), static_cast<long>(event.value),
             event.message ? event.message : "");
  }
};

bool shouldPresent(const cadenza::AppRuntime& runtime,
                   const cadenza::LauncherApp& launcher) noexcept {
  if (runtime.transitioning() || runtime.systemMenuActive() ||
      runtime.appSuspendedBySystem()) {
    return true;
  }
  if (runtime.currentId() != cadenza::apps::kLauncherAppId) {
    return true;
  }
  return launcher.needsPresent();
}

cadenza::system::SystemServiceHost services;
#if CONFIG_CADENZA_CONNECTIVITY_RUNTIME
cadenza::idf::IdfConnectivityAdapter connectivity{services};
#endif
VoiceAdapter voice{services.voiceCapture()};
cadenza::MonoFramebuffer framebuffer{cadenza::FramebufferProfile::TEmbed};
cadenza::MonoCanvas canvas{framebuffer};
cadenza::AppRuntime runtime{cadenza::FramebufferProfile::TEmbed};
cadenza::idf::TEmbedDisplay display;
cadenza::idf::TEmbedInput input;
LogDiagnosticSink diagnostics;
cadenza::LauncherApp launcher;
cadenza::TimerApp timerApp;
cadenza::SightApp sight;
cadenza::MotionApp motion;
cadenza::SettingsApp settings;
cadenza::AnimationGalleryApp gallery;
#else
VoiceAdapter voice;
#endif
#if CONFIG_CADENZA_T_EMBED_SPEAKER
#if !CONFIG_CADENZA_T_EMBED_RUNTIME
cadenza::audio::InteractionSoundService sound;
#endif
cadenza::idf::TEmbedSpeaker speaker;
#endif
#if CONFIG_CADENZA_T_EMBED_MICROPHONE
cadenza::idf::TEmbedMicrophone microphone{voice.capture};
#endif

esp_err_t provide_voice(uint8_t *buffer, size_t length, size_t *bytes_read,
                        void *context) {
  auto *adapter = static_cast<VoiceAdapter *>(context);
  adapter->sessionBridge.synchronize(adapter->packetizer);
  size_t offset = 0;
  while (offset < length) {
    cadenza::voice::UsbVoicePacket packet;
    if (!adapter->packetizer.nextPacket(packet)) {
      packet.samples.fill(0);
    }
    const size_t remaining = length - offset;
    const size_t copy = remaining < sizeof(packet.samples)
                            ? remaining
                            : sizeof(packet.samples);
    std::memcpy(buffer + offset, packet.samples.data(), copy);
    offset += copy;
  }
  *bytes_read = length;
  return ESP_OK;
}

#if !CONFIG_CADENZA_T_EMBED_MICROPHONE
void synthetic_capture_task(void *context) {
  auto *adapter = static_cast<VoiceAdapter *>(context);
  TickType_t last_wake = xTaskGetTickCount();
  while (true) {
    if (adapter->capture.state() == cadenza::VoiceCaptureState::Starting) {
      adapter->capture.notifyStarted(cadenza::voice::kVoicePcmFormat);
    }
    cadenza::voice::VoiceBlock block;
    block.sequence = adapter->sequence++;
    adapter->capture.publish(block, cadenza::voice::kVoicePcmFormat);
    vTaskDelayUntil(&last_wake, pdMS_TO_TICKS(10));
  }
}
#endif

#if CONFIG_CADENZA_T_EMBED_MICROPHONE
void hardware_capture_task(void *context) {
  static_cast<cadenza::idf::TEmbedMicrophone *>(context)->run();
  vTaskDelete(nullptr);
}
#endif

}  // namespace

extern "C" void tud_mount_cb(void) { cadenza::idf::uacMounted(); }
extern "C" void tud_umount_cb(void) { cadenza::idf::uacUnmounted(); }
extern "C" void tud_suspend_cb(bool remote_wakeup_enabled) {
  (void)remote_wakeup_enabled;
  cadenza::idf::uacSuspended();
}
extern "C" void tud_resume_cb(void) { cadenza::idf::uacResumed(); }

extern "C" void app_main(void) {
  initArduino();

#if CONFIG_CADENZA_T_EMBED_RUNTIME
  ESP_ERROR_CHECK(display.start());
  ESP_ERROR_CHECK(input.start());
  runtime.setDiagnosticSink(&diagnostics);
  services.setDiagnosticSink(&diagnostics);
  ESP_ERROR_CHECK(runtime.registerApp(cadenza::apps::kLauncherAppId, launcher,
                                      false,
                                      cadenza::apps::builtinAppCapabilities(
                                          cadenza::apps::kLauncherAppId))
                      ? ESP_OK
                      : ESP_FAIL);
  ESP_ERROR_CHECK(runtime.registerApp(
                      cadenza::apps::kTimerAppId, timerApp, true,
                      cadenza::apps::builtinAppCapabilities(
                          cadenza::apps::kTimerAppId))
                      ? ESP_OK
                      : ESP_FAIL);
  ESP_ERROR_CHECK(runtime.registerApp(
                      cadenza::apps::kSightAppId, sight, true,
                      cadenza::apps::builtinAppCapabilities(
                          cadenza::apps::kSightAppId))
                      ? ESP_OK
                      : ESP_FAIL);
  ESP_ERROR_CHECK(runtime.registerApp(
                      cadenza::apps::kMotionAppId, motion, true,
                      cadenza::apps::builtinAppCapabilities(
                          cadenza::apps::kMotionAppId))
                      ? ESP_OK
                      : ESP_FAIL);
  ESP_ERROR_CHECK(runtime.registerApp(
                      cadenza::apps::kSettingsAppId, settings, true,
                      cadenza::apps::builtinAppCapabilities(
                          cadenza::apps::kSettingsAppId))
                      ? ESP_OK
                      : ESP_FAIL);
  ESP_ERROR_CHECK(runtime.registerApp(
                      cadenza::apps::kGalleryAppId, gallery, true,
                      cadenza::apps::builtinAppCapabilities(
                          cadenza::apps::kGalleryAppId))
                      ? ESP_OK
                      : ESP_FAIL);
  ESP_ERROR_CHECK(runtime.configureHome(cadenza::apps::kLauncherAppId)
                      ? ESP_OK
                      : ESP_FAIL);
  ESP_ERROR_CHECK(runtime.begin(cadenza::apps::kLauncherAppId) ? ESP_OK
                                                               : ESP_FAIL);
  runtime.bindSystem(services.snapshot(), services);
#if CONFIG_CADENZA_CONNECTIVITY_RUNTIME
  ESP_ERROR_CHECK(connectivity.start());
#endif
#endif

#if CONFIG_CADENZA_T_EMBED_SPEAKER
#if CONFIG_CADENZA_T_EMBED_RUNTIME
  // Match PlatformIO: speaker failure must not kill the graphics runtime.
  const esp_err_t speakerResult = speaker.start(services.sound());
  services.postPlatformEvent(cadenza::system::PlatformEvent::soundOutputAvailability(
      speakerResult == ESP_OK));
  if (speakerResult != ESP_OK) {
    ESP_LOGW("cadenza_audio", "speaker disabled (%s); graphics remains active",
             esp_err_to_name(speakerResult));
  }
#else
  ESP_ERROR_CHECK(speaker.start(sound));
#endif
#endif

  voice.capture.setAvailable(true);
#if CONFIG_CADENZA_T_EMBED_RUNTIME
  services.postPlatformEvent(
      cadenza::system::PlatformEvent::microphoneAvailability(true));
#endif
  cadenza::idf::installUacLifecycleAdapter(voice.sessionBridge, 1);
#if CONFIG_CADENZA_T_EMBED_MICROPHONE
  ESP_ERROR_CHECK(microphone.start());
  BaseType_t task_created = xTaskCreatePinnedToCore(
      hardware_capture_task, "cadenza_mic",
      cadenza::t_embed_audio::kMicrophone.taskStackBytes, &microphone,
      cadenza::t_embed_audio::kMicrophone.taskPriority, nullptr,
      cadenza::t_embed_audio::kMicrophone.taskCore);
#else
  BaseType_t task_created = xTaskCreatePinnedToCore(
      synthetic_capture_task, "cadenza_mic", 4096, &voice, 5, nullptr, 1);
#endif
  ESP_ERROR_CHECK(task_created == pdPASS ? ESP_OK : ESP_ERR_NO_MEM);

  uac_device_config_t config = {
      .skip_tinyusb_init = false,
      .output_cb = nullptr,
      .input_cb = provide_voice,
      .set_mute_cb = nullptr,
      .set_volume_cb = nullptr,
      .cb_ctx = &voice,
      .spk_itf_num = -1,
      .mic_itf_num = 1,
  };
  ESP_ERROR_CHECK(uac_device_init(&config));

#if CONFIG_CADENZA_T_EMBED_RUNTIME
  // Match PlatformIO's Arduino loopTask: pin UI to core 1 so the core-0
  // speaker task (prio 2) cannot slice convert/compose/present. app_main
  // itself stays on CPU0 and only owns bring-up.
  constexpr std::uint8_t kUiTaskCore = 1;
  constexpr UBaseType_t kUiTaskPriority = 2;
  constexpr std::uint32_t kUiTaskStackBytes = 12288;
  const BaseType_t uiCreated = xTaskCreatePinnedToCore(
      [](void*) {
        std::int64_t lastFrameUs = esp_timer_get_time();
        bool holdPresentAfterSystem = false;
        while (true) {
          input.sample();
          const std::int64_t nowUs = esp_timer_get_time();
          if (nowUs - lastFrameUs < 16'667) {
            vTaskDelay(pdMS_TO_TICKS(1));
            continue;
          }
          const float dt = std::min(
              static_cast<float>(nowUs - lastFrameUs) / 1'000'000.0F, 0.05F);
          lastFrameUs = nowUs;
#if CONFIG_CADENZA_CONNECTIVITY_RUNTIME
          connectivity.pump();
#endif
          const auto inputFrame = input.takeFrame();
          cadenza::system::FrameCoordinator::runFrameAt(
              services, runtime, canvas,
              static_cast<cadenza::MonotonicMillis>(nowUs / 1000), dt,
              inputFrame);
#if CONFIG_CADENZA_CONNECTIVITY_RUNTIME
          connectivity.pump();
#endif
          const bool systemBusy = runtime.transitioning() ||
                                  runtime.systemMenuActive() ||
                                  runtime.appSuspendedBySystem();
          if (systemBusy) {
            holdPresentAfterSystem = true;
          }
          if (shouldPresent(runtime, launcher) || holdPresentAfterSystem) {
            if (!display.present(framebuffer)) {
              ESP_LOGE("cadenza_display", "frame transfer failed");
            }
            if (runtime.currentId() == cadenza::apps::kLauncherAppId) {
              launcher.markPresented();
            }
            if (!systemBusy) {
              holdPresentAfterSystem = false;
            }
          }
          // Drain encoder edges that arrived during a slow present.
          input.sample();
          vTaskDelay(pdMS_TO_TICKS(1));
        }
      },
      "cadenza_ui", kUiTaskStackBytes, nullptr, kUiTaskPriority, nullptr,
      kUiTaskCore);
  ESP_ERROR_CHECK(uiCreated == pdPASS ? ESP_OK : ESP_ERR_NO_MEM);
#endif
}

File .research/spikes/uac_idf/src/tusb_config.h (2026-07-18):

/* Build-only composite configuration: UAC2 microphone + CDC. */
#pragma once

#include "uac_descriptors.h"
#include "cadenza_usb_voice_contract.h"

#if CONFIG_UAC_SAMPLE_RATE != CADENZA_USB_VOICE_SAMPLE_RATE_HZ || \
    CONFIG_UAC_BIT_RESOLUTION != CADENZA_USB_VOICE_BITS_PER_SAMPLE || \
    CONFIG_UAC_MIC_CHANNEL_NUM != CADENZA_USB_VOICE_CHANNELS || \
    CONFIG_UAC_MIC_INTERVAL_MS != CADENZA_USB_VOICE_INTERVAL_MS || \
    CONFIG_UAC_SPEAKER_CHANNEL_NUM != 0
#error "ESP-IDF UAC configuration diverges from the Cadenza USB voice contract"
#endif

#ifndef CFG_TUSB_MCU
#define CFG_TUSB_MCU OPT_MCU_ESP32S3
#endif

#define CFG_TUSB_OS OPT_OS_FREERTOS
#define CFG_TUSB_DEBUG 0
#define CFG_TUD_ENABLED 1
#define CFG_TUSB_RHPORT0_MODE (OPT_MODE_DEVICE | OPT_MODE_FULL_SPEED)
#define CFG_TUD_MAX_SPEED OPT_MODE_FULL_SPEED
#define CFG_TUD_ENDPOINT0_SIZE 64
#define CFG_TUSB_MEM_ALIGN __attribute__((aligned(4)))

#define CFG_TUD_CDC 1
#define CFG_TUD_MSC 0
#define CFG_TUD_HID 0
#define CFG_TUD_MIDI 0
#define CFG_TUD_AUDIO 1
#define CFG_TUD_VENDOR 0

#if CONFIG_UAC_SUPPORT_MACOS
#define CFG_TUD_AUDIO_ENABLE_FEEDBACK_FORMAT_CORRECTION 1
#endif

#define CFG_TUD_AUDIO_ENABLE_FEEDBACK_EP 1
#define CFG_TUD_AUDIO_FUNC_1_DESC_LEN TUD_AUDIO_DEVICE_DESC_LEN
#define CFG_TUD_AUDIO_FUNC_1_N_FORMATS 1
#define CFG_TUD_AUDIO_FUNC_1_MAX_SAMPLE_RATE DEFAULT_SAMPLE_RATE
#define CFG_TUD_AUDIO_FUNC_1_N_CHANNELS_TX MIC_CHANNEL_NUM
#define CFG_TUD_AUDIO_FUNC_1_N_CHANNELS_RX SPEAK_CHANNEL_NUM
#define CFG_TUD_AUDIO_FUNC_1_FORMAT_1_N_BYTES_PER_SAMPLE_TX CONFIG_UAC_BYTES_PER_SAMPLE
#define CFG_TUD_AUDIO_FUNC_1_FORMAT_1_RESOLUTION_TX CONFIG_UAC_BIT_RESOLUTION
#define CFG_TUD_AUDIO_FUNC_1_FORMAT_1_N_BYTES_PER_SAMPLE_RX CONFIG_UAC_BYTES_PER_SAMPLE
#define CFG_TUD_AUDIO_FUNC_1_FORMAT_1_RESOLUTION_RX CONFIG_UAC_BIT_RESOLUTION
#define CFG_TUD_AUDIO_FUNC_1_FORMAT_1_FRAME_SZ_TX \
  (CFG_TUD_AUDIO_FUNC_1_FORMAT_1_N_BYTES_PER_SAMPLE_TX * CFG_TUD_AUDIO_FUNC_1_N_CHANNELS_TX)
#define CFG_TUD_AUDIO_FUNC_1_FORMAT_1_FRAME_SZ_RX \
  (CFG_TUD_AUDIO_FUNC_1_FORMAT_1_N_BYTES_PER_SAMPLE_RX * CFG_TUD_AUDIO_FUNC_1_N_CHANNELS_RX)

#define CFG_TUD_AUDIO_ENABLE_EP_IN 1
#define CFG_TUD_AUDIO_FUNC_1_FORMAT_1_EP_SZ_IN \
  ((CFG_TUD_AUDIO_FUNC_1_MAX_SAMPLE_RATE / 1000 * CFG_TUD_AUDIO_FUNC_1_FORMAT_1_FRAME_SZ_TX) + \
   CFG_TUD_AUDIO_FUNC_1_FORMAT_1_FRAME_SZ_TX)
#define CFG_TUD_AUDIO_FUNC_1_EP_IN_SW_BUF_SZ \
  (CFG_TUD_AUDIO_FUNC_1_FORMAT_1_EP_SZ_IN * (MIC_INTERVAL_MS + 1))
#define CFG_TUD_AUDIO_FUNC_1_EP_IN_SZ_MAX CFG_TUD_AUDIO_FUNC_1_FORMAT_1_EP_SZ_IN

#define CFG_TUD_AUDIO_ENABLE_EP_OUT 1
#define CFG_TUD_AUDIO_FUNC_1_FORMAT_1_EP_SZ_OUT 0
#define CFG_TUD_AUDIO_FUNC_1_EP_OUT_SW_BUF_SZ 0
#define CFG_TUD_AUDIO_FUNC_1_EP_OUT_SZ_MAX 0
#define CFG_TUD_AUDIO_FUNC_1_N_AS_INT 1
#define CFG_TUD_AUDIO_FUNC_1_CTRL_BUF_SZ 64

#define CFG_TUD_CDC_RX_BUFSIZE 64
#define CFG_TUD_CDC_TX_BUFSIZE 64
#define CFG_TUD_CDC_EP_BUFSIZE 64

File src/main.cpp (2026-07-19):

#include <Arduino.h>
#include <TFT_eSPI.h>
#include <esp_timer.h>

#include <algorithm>
#include <cstdint>

#include "board_pins.h"
#include "cadenza/core/app_runtime.h"
#include "cadenza/apps/apps.h"
#include "cadenza/core/mono_canvas.h"
#include "cadenza/core/mono_framebuffer.h"
#include "cadenza/system/frame_coordinator.h"
#include "input.h"
#include "i2s_audio_output.h"
#include "serial_diagnostic_sink.h"
#include "tft_presenter.h"

namespace {
TFT_eSPI display;
cadenza::MonoFramebuffer framebuffer{cadenza::FramebufferProfile::TEmbed};
cadenza::MonoCanvas canvas{framebuffer};
TftPresenter presenter(display);
InputController input;
cadenza::system::SystemServiceHost services;
cadenza::AppRuntime runtime{cadenza::FramebufferProfile::TEmbed};
SerialDiagnosticSink diagnosticSink;
I2sAudioOutput audioOutput;
cadenza::LauncherApp launcher;
cadenza::TimerApp timerApp;
cadenza::SightApp sight;
cadenza::MotionApp motion;
cadenza::SettingsApp settings;
cadenza::AnimationGalleryApp gallery;
std::int64_t lastFrameUs = 0;
std::int64_t fpsWindowStartUs = 0;
std::uint32_t fpsPresentedFrames = 0;
std::uint32_t fpsLogicFrames = 0;

struct LcdCommand {
  uint8_t command;
  uint8_t data[14];
  uint8_t length;
};

constexpr LcdCommand kLcdCommands[] = {
    {0x11, {0}, 0x80}, {0x3A, {0x05}, 1}, {0xB2, {0x0B, 0x0B, 0x00, 0x33, 0x33}, 5},
    {0xB7, {0x75}, 1}, {0xBB, {0x28}, 1}, {0xC0, {0x2C}, 1}, {0xC2, {0x01}, 1},
    {0xC3, {0x1F}, 1}, {0xC6, {0x13}, 1}, {0xD0, {0xA7}, 1},
    {0xD0, {0xA4, 0xA1}, 2}, {0xD6, {0xA1}, 1},
    {0xE0, {0xF0, 0x05, 0x0A, 0x06, 0x06, 0x03, 0x2B, 0x32, 0x43, 0x36, 0x11, 0x10, 0x2B, 0x32}, 14},
    {0xE1, {0xF0, 0x08, 0x0C, 0x0B, 0x09, 0x24, 0x2B, 0x22, 0x43, 0x38, 0x15, 0x16, 0x2F, 0x37}, 14},
};

void applyPanelInitialization() {
  for (const auto& entry : kLcdCommands) {
    display.writecommand(entry.command);
    for (uint8_t i = 0; i < (entry.length & 0x7F); ++i) display.writedata(entry.data[i]);
    if (entry.length & 0x80) delay(120);
  }
}

bool shouldPresent() noexcept {
  if (runtime.transitioning() || runtime.systemMenuActive() ||
      runtime.appSuspendedBySystem()) {
    return true;
  }
  if (runtime.currentId() != cadenza::apps::kLauncherAppId) {
    return true;
  }
  // Settled launcher with an already-presented pose skips TFT present and
  // recovers the SPI budget that previously capped the device near 8 FPS.
  return launcher.needsPresent();
}
}  // namespace

void setup() {
  pinMode(BoardPins::kPowerOn, OUTPUT);
  digitalWrite(BoardPins::kPowerOn, HIGH);
  Serial.begin(115200);
  delay(150);
  Serial.println("Cadenza OS runtime starting");
  Serial.printf("Flash: %u MB, PSRAM: %u MB\n", ESP.getFlashChipSize() / 1048576U,
                ESP.getPsramSize() / 1048576U);

  display.begin();
  applyPanelInitialization();
  display.setRotation(3);
  pinMode(BoardPins::kLcdBacklight, OUTPUT);
  digitalWrite(BoardPins::kLcdBacklight, HIGH);

  Serial.printf("Display: T-Embed ST7789, %dx%d SPI=80MHz\n",
                framebuffer.width(), framebuffer.height());
  input.begin();
  runtime.setDiagnosticSink(&diagnosticSink);
  services.setDiagnosticSink(&diagnosticSink);
  runtime.registerApp(cadenza::apps::kLauncherAppId, launcher, false,
                      cadenza::apps::builtinAppCapabilities(cadenza::apps::kLauncherAppId));
  runtime.registerApp(cadenza::apps::kTimerAppId, timerApp, true,
                      cadenza::apps::builtinAppCapabilities(cadenza::apps::kTimerAppId));
  runtime.registerApp(cadenza::apps::kSightAppId, sight, true,
                      cadenza::apps::builtinAppCapabilities(cadenza::apps::kSightAppId));
  runtime.registerApp(cadenza::apps::kMotionAppId, motion, true,
                      cadenza::apps::builtinAppCapabilities(cadenza::apps::kMotionAppId));
  runtime.registerApp(cadenza::apps::kSettingsAppId, settings, true,
                      cadenza::apps::builtinAppCapabilities(cadenza::apps::kSettingsAppId));
  runtime.registerApp(cadenza::apps::kGalleryAppId, gallery, true,
                      cadenza::apps::builtinAppCapabilities(cadenza::apps::kGalleryAppId));
  runtime.configureHome(cadenza::apps::kLauncherAppId);
  runtime.begin(cadenza::apps::kLauncherAppId);
  runtime.bindSystem(services.snapshot(), services);
  const bool audioAvailable =
      audioOutput.begin(services.sound(), &diagnosticSink);
  services.postPlatformEvent(
      cadenza::system::PlatformEvent::soundOutputAvailability(audioAvailable));
  if (!audioAvailable) {
    Serial.println("Audio disabled; graphics runtime remains active");
  } else {
    Serial.println("I2S audio task started (MAX98357A)");
  }
  lastFrameUs = esp_timer_get_time();
  fpsWindowStartUs = lastFrameUs;
}
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

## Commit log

2026-07-18 feat: add portable animation runtime and interaction sound (#1)
    * wip: plan portable animation runtime
    * wip: establish portable core foundation
    * wip: add canonical mono graphics
    * wip: migrate apps to portable runtime
    * wip: add deterministic headless host
    * wip: add SDL3 desktop simulator MVP
    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
2026-07-18 feat: add continuous launcher with fixed-ratio covers
    [main.cpp]
2026-07-19 feat: polish activation timer presentation
2026-07-19 fix: isolate persistent timer indicator
2026-07-19 fix: keep timer dump mode isolated
2026-07-19 fix: refine Timer duration adjustment
2026-07-19 fix: wrap Timer duration without zero
2026-07-19 fix: contain maximum Timer indicator label
2026-07-19 fix: polish T-Embed runtime and archive completed OpenSpecs
    Speed up present/blit paths, stabilize encoder via PCNT, improve Sight
    bass audibility, pack transitions, and keep the main loop yielding so
    Gallery DIP no longer trips the watchdog. Sync musical-note, SIGHT, and
    system-menu specs, then archive the finished sight-reading and overlay
    changes after T-Embed menu acceptance.
    [input.cpp, main.cpp]
2026-07-19 feat: promote ESP-IDF UAC firmware as the primary T-Embed path
    Ship a first-class IDF build/flash entry with PlatformIO-parity UI
    (Sight, PCNT encoder, skip-present, display orientation), harden USB
    mic remount and speaker playback, and make USB-mute-speaker opt-in
    via Settings (default off).
    [main.cpp, t_embed_display.cpp, t_embed_input.cpp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]
2026-07-19 feat: scope Home indicators and scroll Settings lists
    Keep Timer/MIC badges on Launcher with leave/return slide motion, and
    make overflowing Settings rows follow the selection so every item stays reachable.
2026-07-19 fix: smooth IDF UI and finish Settings right-pane layout
    Pin the ESP-IDF frame loop to core 1 so speaker work no longer preempts
    Launcher scrolling, align enter/return handoff timing, pack Cover blend,
    and fill the Settings list across the right pane with bottom padding.
    [main.cpp, t_embed_display.cpp]
2026-07-19 fix: stabilize T-Embed USB mic after RST packing lottery
    Pick DMA unpack/channel from a scored prime window each capture start,
    keep 24 dB dual-MEMS capture recoverable without tearing ES7210, and add
    host/selftest coverage for the sticky dirty-audio path.
    [t_embed_microphone.cpp, t_embed_microphone.h]
2026-07-20 wip: scaffold Rev A hardware design flow
    [bom.csv, cadenza_rev_a_smoke.kicad_pcb, cadenza_rev_a_smoke.sch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]
2026-07-20 wip: add verified Rev A product D0 package
    [BOM.csv, cadenza-assembled-envelope-d0.stl, cadenza-front-envelope-d0.stl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]
2026-07-20 wip: add D1 schematic and four-layer PCB layout
    [bom-d1.csv, cadenza-d1.kicad_pcb, cadenza-d1.kicad_sch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]
2026-07-21 wip: add capability mode JSON, update circuit and component documentation for Rev A
    [bom-d1.csv, bom.csv, cadenza-d1-antenna-cutout-v21-candidate.kicad_pcb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]
2026-07-22 hardware: replace Rev A with reference-derived Cadenza L1
    [BOM.csv, Cadenza-L1-JLCPCB-BOM.csv, Cadenza-L1-Screen-Only-Display.kicad_sch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]
2026-07-22 docs: refocus hardware work on product concepts
    [Cadenza-L1-JLCPCB-BOM.csv, Cadenza-L1-Screen-Only-Display.kicad_sch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]
2026-07-22 docs: add Cadenza industrial design concept
    [cadenza-concept-v1.3mf, cadenza-concept-v1.scad, cadenza-concept-v1.stl]
2026-07-22 docs: refine Cadenza industrial design
    [cadenza-concept-v1.3mf, cadenza-concept-v1.scad]
2026-07-23 docs: add infrared optical window concept
    [cadenza-concept-v1.3mf, cadenza-concept-v1.scad]

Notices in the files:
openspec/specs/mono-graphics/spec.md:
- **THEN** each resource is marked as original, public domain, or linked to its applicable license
